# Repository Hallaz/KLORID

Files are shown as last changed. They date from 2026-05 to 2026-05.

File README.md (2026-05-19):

# KLORID

42-key split keyboard, polydactyl layout, sourced untuk komponen yang mudah didapat di **Indonesia** (Tokopedia / Shopee). Derivative dari [Lefuneste83/KLOR](https://github.com/Lefuneste83/KLOR), yang sendirinya fork dari [GEIGEIGEIST/KLOR](https://github.com/GEIGEIGEIST/KLOR).

> **"ID"** suffix = Indonesia variant. Sourcing decisions menghindari long-wait import (Mill-Max, Elite-Pi, etc.), default ke part Tokopedia-sourceable.

## Hardware modifications dari upstream KLOR

### Core PCB modifications (Phase 2)

| # | Modification | Source → Target |
|---|---|---|
| MOD #1 | MCU footprint | Elite-Pi (Pro-Micro form factor) → bare **Waveshare RP2040-Zero** (2.54mm pitch through-hole) |
| MOD #2 | Inter-half connector | TRRS jack MJ-4PP-9 → **USB-C 16-pin midmount** (HRO Type-C-31-M-12) |
| MOD #3 | RGB orientation | south-facing **verified** — fork's existing `SK6812MINI_and_cherry_1` footprint sudah benar (no schematic change needed) |

### Phase 3 PCB layout enhancements

| Phase | Enhancement |
|---|---|
| **3e** | **Dual-purpose SW23 at matrix [3,5]** — single position serves either encoder OR MX switch, builder chooses per side at assembly (mix possible — encoder on one half, switch on other) |
| **3f** | Left thumb cluster **breakaway notch removed** (real-world fragility evidence — fork's intentional snap-off point breaks too easily under normal handling) |
| **3g** | **Haptic feedback re-added as DNP** — Pimoroni Haptic Buzz 5-pin connector (`Conn_01x05`), I2C-shared with OLED (GP2/GP3), trigger on GP14. Optional install at assembly time; PCB ships with footprint+routing ready. |
| **3h** | **Silkscreen branding** — KLORID text + Garuda Pancasila image (Indonesia national emblem) on F.SilkS layer |

### Dropped from upstream (out of scope for V1)

- Audio speaker (PWM buzzer on GP9 — pin now repurposed sebagai matrix col 2)
- Battery + power switch chain (wired-only build)
- Trackball / pointing device module
- `lvc27_onlyInput` buffer (haptic-related, not needed dengan Pimoroni breakout approach)

## Status — Phase 4 ready (Gerber export complete)

PCB design lengkap. All Phase 3 enhancements committed. Gerber files regenerated (ZIP siap upload). Pending: actual JLCPCB order + case fabrication.

**Latest milestones:**
- ✅ Phase 3a-3h PCB layout complete (DRC clean, 0 violations)
- ✅ Schematic + PCB sync (ERC clean, 0 errors)
- ✅ Gerber export untuk all layers (`hardware/PCB/klor1_4/gerbers/gerbers.zip`)
- ✅ Switchplate DXF generated (`working/switchplate_klorid.dxf` — for CO2 laser cut)
- ⏳ JLCPCB order pending
- ⏳ Other case acrylic layers (bottom plate, spacers, top frame) pending generation
- ⏳ Firmware Phase 6 deferred (QMK + Vial dengan Justin Lam RP2040-Zero config)

Detail per-phase progress di [PHASE_LOG.md](PHASE_LOG.md).

## Case strategy (Indonesia-friendly)

PCB modifications drive case requirements (USB-C cutout, encoder/MX position, OLED window). Case approach untuk Indonesia sourcing:

- **PCB fab:** JLCPCB (2-layer FR4 1.6mm, black HASL)
- **Switchplate + acrylic layers:** Local CO2 laser cut shop (DXF generated programmatically from PCB)
- **Case body 3DP:** JLCPCB 3D printing service atau lokal print
- **Hardware:** M2 standoffs + screws from Tokopedia

## Spec & decisions

- [PROJECT_SPEC.md](PROJECT_SPEC.md) — Tier 1 (locked Requirements R1-R10) + Tier 2 (Component Decisions dengan justifikasi)
- [PHASE_LOG.md](PHASE_LOG.md) — Build progress log (append-only, latest at bottom)
- [CONTRIBUTING.md](CONTRIBUTING.md) — Collaboration model + KiCad workflow + hard rules
- [docs/phase-1-recon/](docs/phase-1-recon/) — Phase 1 reconnaissance outputs (5 deliverables)

## Repository structure

```
KLORID/
├── README.md             ← (you are here)
├── LICENSE               ← GPL-3.0 (inherited from upstream)
├── PROJECT_SPEC.md       ← Requirements + component decisions
├── PHASE_LOG.md          ← Build progress
├── CONTRIBUTING.md       ← Collaboration + workflow rules
├── docs/
│   └── phase-1-recon/    ← Phase 1 deliverables
└── hardware/             ← KiCad PCB + schematic + firmware + case
    ├── PCB/klor1_4/      ← Active design (KiCad 10)
    ├── FIRMWARE/         ← QMK + Vial firmware
    ├── case/             ← 3DP STL + acrylic DXF
    └── docs/             ← Fork's original hardware docs
```

Excluded (local-only, not in repo): `references/` (upstream snapshots untuk development context), `working/` (derived gerbers/firmware build artifacts), `.claude/` (harness state).

## License

**GPL-3.0** — same as upstream KLOR. Derivative works WAJIB tetap GPL-3.0. See [LICENSE](LICENSE).

## Attribution

Credit chain:
- **GEIGEIGEIST/KLOR** — original KLOR design
- **Lefuneste83/KLOR** — fork dengan klor1_4 (Rev 1.4) PCB
- **Hallaz/KLORID** — Indonesia-sourceable variant (this repo)

Built with Claude Code as collaborator. AI-assisted PCB modification per [CONTRIBUTING.md](CONTRIBUTING.md) collaboration model.

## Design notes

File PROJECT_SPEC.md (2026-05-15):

# KLOR Custom Build — Project Spec

> **Last updated 2026-05-14** (Phase 2 in-progress — schematic MOD #1 + MOD #2 done, ERC clean). Spec dibagi 2 tier: REQUIREMENTS (locked, user-owned) + COMPONENT DECISIONS (Claude-decided, justified). Tier 1 berubah hanya dengan explicit user discussion. Tier 2 bisa berubah dengan justifikasi teknis/sourcing.

---

## TIER 1: REQUIREMENTS (locked)

User's functional spec — apa keyboard ini harus DO.

| # | Requirement | Notes |
|---|---|---|
| R1 | 42-key split keyboard, polydactyl layout | **21 keys per side + 1 encoder/knob position per side** (total 42 keys + 2 encoders); 19.05 × 19.05 mm key spacing |
| R2 | MX switch ecosystem | Universal MX hotswap socket; switch + keycap MX-compatible |
| R3 | USB-C native MCU primary | No Pro-Micro daughterboard awkward USB |
| R4 | USB-C inter-half connector | Replace TRRS jack |
| R5 | Per-key RGB matrix | 42 LED total (21/side × 2), south-facing orientation |
| R6 | OLED display | Status / mode / animation rendering |
| R7 | Rotary encoder optional via jumper | EC11-style with push button (1 per side default) |
| R8 | JLCPCB-manufacturable | 2-layer FR4 1.6mm, standard DRC compliant |
| R9 | Vial-QMK firmware | Real-time keymap edit without re-flash |
| R10 | Socketable MCU | Untuk prototyping iteration |

---

## TIER 2: COMPONENT DECISIONS

### MCU

| | Decision | Rationale |
|---|---|---|
| **Part** | Original Waveshare RP2040-Zero (not clones) | 20 GPIO sufficient (17 used + 3 headroom), USB-C native, compact, $3-5/unit |
| **Sourcing** | Tokopedia / Shopee (verified seller) | Indonesia sourcing-locked: Elite-Pi unavailable |
| **Mounting** | 1.27mm pitch female pin header (2×12-pin per side) di PCB + 1.27mm male pin header solder ke castellated edge RP2040-Zero | Mill-Max preferred low profile tapi Aliexpress 3-4wk wait. 1.27mm header Tokopedia ~10rb/pasang. Stack ~6mm. |

### Inter-half connector

| | Decision | Rationale |
|---|---|---|
| **Part** | USB-C 16-pin midmount SMD (GCT USB4085 or HRO TYPE-C-31-M-12, final TBD Phase 2) | 16-pin = right pin count; midmount = cleaner PCB profile |
| **Wire allocation (firmware initial)** | **Half-duplex single-wire serial on GP1** (3 wires: VBUS + GND + GP1) | Per fork [config.h:49](hardware/FIRMWARE/qmk_rp2040/electronlab/klor/config.h) currently active |
| **Wire allocation (PCB routing)** | **Route both GP1 + GP4 to USB-C pads** (4 traces) | Future-proof full-duplex upgrade path per fork [CHANGELOG.md:69-73](hardware/CHANGELOG.md). Firmware switch later, no PCB re-spin needed. |
| **CC1, CC2** | Tied to 5.1kΩ pulldown to GND each | Dumb-sink USB-C; implemented in MOD #2 schematic |
| **VBUS / 5V net** | USB-C VBUS pin joined to global `+5V` net (shared with MCU 5V pad + LED VCC). `PWR_FLAG` marker placed on `+5V` net (MCU-side, `#FLG02`) to satisfy ERC | USB-C VBUS pin = passive type — ERC needs PWR_FLAG declared somewhere on net. PWR_FLAG is net-level marker; one instance covers entire `+5V` net regardless of placement. No PCB/physical effect. |
| **Cable** | USB-C to USB-C, ~30cm | Tokopedia sourceable; not part of PCB BOM |

### RGB LED

| | Decision | Rationale |
|---|---|---|
| **Part** | SK6812MINI-E (6028 size), south-facing reverse-mount | Better current + uniformity vs WS2812 3535. Fork klor1_4 sudah south-facing per [README:37](hardware/README.md) |
| **Count** | 42 (21 per side × 2) | Per R5 |
| **Footprint variant** | `SK6812MINI_and_cherry_1` (already di klor1_4 KLOR.pretty) — dual-layer pad placement + Edge.Cuts cutout zone | **No new footprint needed** ([FOOTPRINT_INVENTORY C.3](docs/phase-1-recon/FOOTPRINT_INVENTORY.md)) |
| **Assembly** | Hand-solder reverse-mount dengan hot air / reflow plate | User confirmed SMD capability |

### OLED

| | Decision | Rationale |
|---|---|---|
| **Part** | SSD1306 **0.96" 128×64** I²C 4-pin | **Revised from 128×32** — fork rendering code, animation library (`klorimation.h`), logo bitmap semua tuned untuk 128×64. Switching = significant firmware rewrite untuk zero benefit |
| **Footprint** | `SSD1306_128x64OLED` (existing klor1_4 KLOR.pretty) | Outline ~27×27mm = 0.96" form factor. Pin pitch 2.54mm universal |
| **Sourcing** | Tokopedia / Aliexpress (~25-35rb/unit) | Abundant |

### Encoder

| | Decision | Rationale |
|---|---|---|
| **Part** | EC11 vertical mount with push switch | Standard, fork sudah implementasi, sourceable Tokopedia |
| **Config** | Optional via jumper bridge | Fork's design preserved |
| **Encoder push position di matrix** | L35 [3,5] (left), R30 [7,5] (right) — encoder push-button shares matrix position untuk keycode assignment via Vial | Per fork `keyboard.json` LAYOUT_polydactyl |

### Switch socket & matrix

| | Decision | Rationale |
|---|---|---|
| **Hotswap** | Kailh MX hotswap PG1511 | Fork sudah pakai. Universal MX. Tokopedia |
| **Diode** | 1N4148W SOD-123 SMD | Fork's `Diode_SOD123` footprint dual-side reversible |
| **Direction** | COL2ROW | Per fork `keyboard.json:17` |
| **Matrix size** | 8 rows × 6 cols logical (4 rows × 6 cols per half) | Fork-preserved |

### Matrix pin allocation (RP2040-Zero) — REMAPPED

```json
// keyboard.json matrix_pins (Phase 6 firmware update):
"cols": ["GP27", "GP26", "GP9", "GP10", "GP11", "GP12"],
"rows": ["GP5", "GP6", "GP7", "GP8"]
```

| Logical pin | Pin (was, elite_pi) | Pin (new, RP2040-Zero) | Reason |
|---|---|---|---|
| col 0 | GP27 | GP27 | Keep — RP2040-Zero ADC pad |
| col 1 | GP26 | GP26 | Keep — RP2040-Zero ADC pad |
| col 2 | GP22 | **GP9** | Remap — GP22 not exposed on RP2040-Zero edge; ascending order chosen untuk natural label sequence |
| col 3 | GP20 | **GP10** | Remap |
| col 4 | GP23 | **GP11** | Remap |
| col 5 | GP21 | **GP12** | Remap |
| row 0-3 | GP5-GP8 | GP5-GP8 | Keep — exposed on RP2040-Zero edge |

**Additional GPIO assignments** (RP2040-Zero, 20 GPIO total):

| Function | Pin | Notes |
|---|---|---|
| RESET button | **GP15** | Soft reset via firmware (Vial reset keycode). Hardware reset to bootloader requires fine-wire jumper ke RP2040-Zero RUN test pad — defer ke Phase 5 assembly kalau dibutuhkan untuk "Windows startup recovery" use case |
| Spares | GP13, GP14 | 2 free GPIO untuk future expansion (e.g., second encoder, status LED, additional I²C device) |

Full GPIO allocation: [docs/phase-1-recon/PIN_MAPPING_PROPOSAL.md](docs/phase-1-recon/PIN_MAPPING_PROPOSAL.md).

### Base PCB variant

| | Decision | Rationale |
|---|---|---|
| **Variant** | Fork's `PCB/klor1_4/` (Rev 1.4) | Latest with committed files. Rev 1.5 announced but PCB files absent. LP_KS33 = irrelevant (low-profile beta) |

### Case

| | Decision | Rationale |
|---|---|---|
| **Files** | Fork's `case/3DP/polydactyl/regular/*.stl` + `case/3DP/polydactyl/switchplate/*.stl` | Drop-in from fork; no modification needed |
| **Material** | 3D printed (PETG / PLA / ASA — user choice) | Standard FFF print |

### Manufacturing & assembly model

| | Decision | Rationale |
|---|---|---|
| **PCB fab** | JLCPCB, 2-layer FR4 1.6mm, HASL/LeadFree HASL, black, "Remove Order Number: Yes" | Per fork [PCB/README.md:14](hardware/PCB/README.md) |
| **PCBA service** | ❌ NOT used | User has SMD soldering capability — hand-solder all parts |
| **BOM sourcing** | Mix Tokopedia + Aliexpress + LCSC | Indonesia sourcing-flexible |

### Firmware configuration (Phase 6 spec)

Per [Justin Lam handwired Skeletyl blog](https://www.justinmklam.com/posts/2025/08/handwired-skeletyl/) — bare RP2040-Zero requires these specific settings (NOT same as fork's `elite_pi` config):

**`keyboard.json` changes:**
```diff
- "development_board": "elite_pi"
+ "processor": "RP2040",
+ "bootloader": "rp2040"
```
Reason: Bare RP2040-Zero needs explicit processor + bootloader macros, bukan dev_board alias. Otherwise flashing may fail.

**`config.h` additions:**
```c
#define RP2040_BOOTLOADER_DOUBLE_TAP_RESET           // double-tap reset → bootloader entry
#define RP2040_BOOTLOADER_DOUBLE_TAP_RESET_TIMEOUT 500U
#define PICO_XOSC_STARTUP_DELAY_MULTIPLIER 64        // crystal startup delay = reliable boot
#define SERIAL_PIO_USE_PIO1                          // 🔑 PIO1 untuk serial; prevents conflict dengan WS2812 (PIO0)
```

**`rules.mk` addition:**
```make
SERIAL_DRIVER = vendor
```
`vendor` = QMK's RP2040-specific PIO-based serial driver.

---

## DROPPED (out of scope; do not re-add tanpa discussion)

- Haptic feedback (DRV2605L driver + ERM/LRA motor + Pimoroni footprint) — ✅ dropped from schematic commit `17c1fb3`
- Audio (PWM speaker on GP9 + `lib/klounds.h` sound clips) — ✅ Mallory Buzzer BZ1 dropped commit `17c1fb3`
- **Trackball module** (mouse/pointing device section in original fork schematic) — ✅ dropped commit `17c1fb3`. Discovered during Phase 2 housekeeping; was NOT in initial DROPPED list. User explicitly decided to skip pointing-device feature scope.
- ZMK firmware variant (QMK only)
- Bluetooth / Nice Nano support (wired RP2040-Zero only)
- Battery & power switch chain (wired-only build): drop MSK12C02 slide switch + JST-PH + `custombatteryconnector_small` placements — ✅ dropped commit `ee98b40` (MOD #1)
- `lvc27_onlyInput` 74LVC2G17 buffer — ✅ dropped commit `17c1fb3` (confirmed haptic-support related)

---

## PCB Modification Scope (revised after Phase 1)

1. **MOD #1 — MCU footprint:** Elite-Pi (RP2040 Pro-Micro form-factor) → custom Waveshare RP2040-Zero footprint with 1.27mm pitch socket pads. **Plus** re-route 4 matrix col pins per remap (GP22/20/23/21 → GP9/10/11/12, ascending order). RESET button connected ke GP15 (soft reset).

2. **MOD #2 — Inter-half connector:** TRRS jack (MJ-4PP-9) → USB-C 16-pin midmount SMD. Route both GP1 + GP4 to USB-C pins (future-proof).

3. **MOD #3 — RGB orientation (VERIFY ONLY):** Confirm klor1_4 schematic instantiate `SK6812MINI_and_cherry_1` variant (south-facing already) bukan older `SK6812MINI_and_cherry`. If yes, no PCB modification for RGB. Verify at Phase 2 schematic open.

**Plus housekeeping (Phase 2 schematic):**
- Remove placements: Pimoroni Haptic, Mallory buzzer, MSK12C02 slide switch, JST-PH battery, custombatteryconnector, lvc27_onlyInput (if haptic-related)
- Phase 6: update `keyboard.json` per pin remap + firmware config

### KEEP unchanged

- Switch footprint area (MX hotswap PG1511)
- Key spacing (19.05 mm × 19.05 mm)
- Encoder placement (optional via jumper, matrix [3,5]/[7,5] coords for push-button)
- OLED area (same physical slot for 128×64)
- Diode positions
- Matrix routing logic (8 rows × 6 cols, COL2ROW)
- Reset switch placement
- LED chain order (entry at GP0 → LED 00 → daisy-chain to LED 20)

---

## Phase 1 Recon outputs (reference)

All deliverables di `docs/phase-1-recon/`:
- [INVENTORY.md](docs/phase-1-recon/INVENTORY.md) — File census + LICENSE (GPL-3.0) + fork status (stale ~20 bulan)
- [MATRIX_VALIDATION.md](docs/phase-1-recon/MATRIX_VALIDATION.md) — Matrix dimensions, pin audit, GPIO budget
- [FOOTPRINT_INVENTORY.md](docs/phase-1-recon/FOOTPRINT_INVENTORY.md) — Library audit + mod-critical footprints
- [PIN_MAPPING_PROPOSAL.md](docs/phase-1-recon/PIN_MAPPING_PROPOSAL.md) — Final 17/20 GPIO allocation
- [REFERENCE_ANALYSIS.md](docs/phase-1-recon/REFERENCE_ANALYSIS.md) — zerosprey42 + Justin Lam + fork delta + Phase 2 risk register (15 items)

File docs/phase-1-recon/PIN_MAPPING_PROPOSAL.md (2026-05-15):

# Phase 1 / Deliverable #4 — PIN_MAPPING_PROPOSAL

> Lock specific pin assignments untuk Waveshare RP2040-Zero target. Cross-validated dari `keyboard.json`, `config.h`, [KLORpinout.png](../../references/KLOR-upstream/docs/images/KLORpinout.png) visual reference, dan zerosprey42 (42-key RP2040-Zero) sebagai exemplar.

---

## A. Reference baseline — fork's pin mapping (Pro Micro physical layout)

[KLORpinout.png](../../references/KLOR-upstream/docs/images/KLORpinout.png) menunjukkan **fork PCB uses Pro Micro physical pinout** (24-pin dual-row format). Pin label di PNG = AVR convention (D0-D7, B1-B7, C6, E6, F4-F7). Fork's elite_pi config (`development_board: "elite_pi"`) maps these physical positions ke **RP2040 GPxx labels** via standard elite_pi-to-Pro-Micro pin mapping.

Cross-reference table (Pro Micro pin → AVR label → RP2040 GPxx → function):

| PM pin # | Side | AVR label | RP2040 GPxx | Fork function | Source |
|---|---|---|---|---|---|
| 1 | TL | TX0/D3 | **GP0** | WS2812 RGB DI | KLORpinout, keyboard.json `ws2812.pin` |
| 2 | TL | RX1/D2 | **GP1** | Serial TX (half-duplex) | KLORpinout, [config.h:49](../../hardware/FIRMWARE/qmk_rp2040/electronlab/klor/config.h) |
| 3 | TL | GND | GND | Ground | — |
| 4 | TL | GND | GND | Ground | — |
| 5 | TL | 2/D1/SDA | **GP2** | I²C1 SDA (OLED) | KLORpinout, [config.h:26](../../hardware/FIRMWARE/qmk_rp2040/electronlab/klor/config.h) |
| 6 | TL | 3/D0/SCL | **GP3** | I²C1 SCL (OLED) | KLORpinout, config.h:25 |
| 7 | TL | 4/D4 | **GP4** | (Reserved: serial RX full-duplex) | config.h:52 commented |
| 8 | TL | 5/C6 | **GP5** | Matrix row 0 | KLORpinout, keyboard.json rows[0] |
| 9 | TL | 6/D7 | **GP6** | Matrix row 1 | keyboard.json rows[1] |
| 10 | TL | 7/E6 | **GP7** | Matrix row 2 | keyboard.json rows[2] |
| 11 | TL | 8/B4 | **GP8** | Matrix row 3 | keyboard.json rows[3] |
| 12 | TL | 9/B5 | **GP9** | Audio PWM (DROPPED) | KLORpinout, config.h:115 |
| 13 | TR | B6/10 | **GP21** | Matrix col 5 | keyboard.json cols[5] |
| 14 | TR | B2/16 | **GP23** | Matrix col 4 | keyboard.json cols[4] |
| 15 | TR | B3/14 | **GP20** | Matrix col 3 | keyboard.json cols[3] |
| 16 | TR | B1/15 | **GP22** | Matrix col 2 | keyboard.json cols[2] |
| 17 | TR | F7/A0 | **GP26** | Matrix col 1 | keyboard.json cols[1] |
| 18 | TR | F6/A1 | **GP27** | Matrix col 0 | keyboard.json cols[0] |
| 19 | TR | F5/A2 | **GP28** | Encoder A (left), Encoder B (right per split.encoder) | keyboard.json encoder |
| 20 | TR | F4/A3 | **GP29** | Encoder B (left), Encoder A (right) | keyboard.json encoder |
| 21 | TR | VCC | 3.3V | Logic power | — |
| 22 | TR | RST | RST | Reset (to button) | — |
| 23 | TR | GND | GND | Ground | — |
| 24 | TR | RAW | VBUS | 5V from USB | — |

✅ **Verified cross-consistency:** KLORpinout PNG, `keyboard.json`, `config.h` semua agree — pin assignment fork tersinkron.

---

## B. RP2040-Zero pin availability audit

Waveshare RP2040-Zero exposes **20 GPIO** (per [Waveshare wiki](https://www.waveshare.com/wiki/RP2040-Zero)):

| GPxx | Edge pad? | Notes |
|---|---|---|
| GP0–GP15 | ✅ Castellated edge | 16 pins, 1.27mm pitch |
| GP16 | ❌ Internal | Onboard WS2812 status LED (Waveshare boot indicator) |
| GP17–GP19 | ❌ NOT accessible | Not broken out |
| GP20–GP25 | ❌ NOT accessible | Not broken out (USB pins GP24/25) |
| GP26–GP29 | ✅ Bottom ADC pads | 4 pins (separate from castellated edge) |

🚨 **Critical mismatch identified:** Fork's cols GP20, GP21, GP22, GP23 are **NOT exposed** di RP2040-Zero. Need remap.

---

## C. Final pin allocation untuk Waveshare RP2040-Zero

| GPxx | Function | Type | Rationale | Status |
|---|---|---|---|---|
| **GP0** | WS2812 RGB DI | PIO | Native RGB data pin, PIO-driven (any GPIO works, GP0 is convention) | ✅ Keep from fork |
| **GP1** | Serial TX (half-duplex) | UART/PIO | Per fork config.h:49 active config | ✅ Keep from fork |
| **GP2** | I²C1 SDA | I²C alt-func | I²C1 hardware peripheral pair (GP2/GP3 native) | ✅ Keep from fork |
| **GP3** | I²C1 SCL | I²C alt-func | Pair with GP2 | ✅ Keep from fork |
| **GP4** | Serial RX (full-duplex upgrade path) | UART/PIO | Per fork CHANGELOG.md:69-73 documented spec | ⚠️ Route PCB pad even if firmware tidak enable initially |
| **GP5** | Matrix row 0 | GPIO | Keep from fork | ✅ |
| **GP6** | Matrix row 1 | GPIO | Keep from fork | ✅ |
| **GP7** | Matrix row 2 | GPIO | Keep from fork | ✅ |
| **GP8** | Matrix row 3 | GPIO | Keep from fork | ✅ |
| **GP9** | **Matrix col 2** | GPIO | **REMAP** dari GP22 (freed from audio drop). Ascending order chosen untuk natural label sequence | 🆕 New |
| **GP10** | **Matrix col 3** | GPIO | **REMAP** dari GP20 | 🆕 New |
| **GP11** | **Matrix col 4** | GPIO | **REMAP** dari GP23 | 🆕 New |
| **GP12** | **Matrix col 5** | GPIO | **REMAP** dari GP21 | 🆕 New |
| **GP13** | (Headroom / spare 1) | GPIO | Available for future feature | ⚪ Free |
| **GP14** | (Headroom / spare 2) | GPIO | Available for future feature | ⚪ Free |
| **GP15** | **RESET button** | GPIO | Soft reset via firmware (Vial reset keycode). User-accessible reset button on PCB | 🆕 New |
| GP16-GP25 | (Not accessible on RP2040-Zero) | — | Not broken out (board design limit) | ❌ N/A |
| **GP26** | Matrix col 1 | GPIO | Keep from fork (ADC-capable, but used as GPIO here) | ✅ |
| **GP27** | Matrix col 0 | GPIO | Keep from fork | ✅ |
| **GP28** | Encoder A (left) / B (right) | GPIO | Keep from fork. ADC-capable but used as GPIO here. | ✅ |
| **GP29** | Encoder B (left) / A (right) | GPIO | Keep from fork | ✅ |

**Total used: 18 GPIO of 20 available. Headroom: 2 GPIO** (GP13, GP14).

Used breakdown: GP0 (RGB DI) + GP1 (serial TX) + GP2-3 (I²C OLED) + GP4 (serial RX reserve, PCB-routed) + GP5-8 (rows) + GP9-12 (cols 2-5) + GP15 (RESET) + GP26-27 (cols 0-1) + GP28-29 (encoder).

---

## D. Updated `keyboard.json` matrix_pins (Phase 6 firmware update preview)

**Current** (fork's klor1_4):
```json
"matrix_pins": {
    "cols": ["GP27", "GP26", "GP22", "GP20", "GP23", "GP21"],
    "rows": ["GP5", "GP6", "GP7", "GP8"]
}
```

**Proposed** (post-remap untuk RP2040-Zero, **LOCKED** per schematic MOD #1 commit `ee98b40`):
```json
"matrix_pins": {
    "cols": ["GP27", "GP26", "GP9", "GP10", "GP11", "GP12"],
    "rows": ["GP5", "GP6", "GP7", "GP8"]
}
```

**Mapping logic untuk new col pins (ascending):**
- Maintain GP27/GP26 di cols 0-1 (fork-preserved, ADC pad)
- Cols 2-5 remap ascending to GP9, GP10, GP11, GP12 — user-accepted untuk natural label sequence (`col 2 < col 3 < col 4 < col 5` matches `GP9 < GP10 < GP11 < GP12`)
- GP9 freed by audio feature drop (was PWM speaker); now repurposed sebagai col 2

**Status:** locked in schematic. Update `keyboard.json` at Phase 6 firmware step (along with `processor`/`bootloader` macros + Justin Lam config — see PROJECT_SPEC.md firmware section).

---

## E. Pin function compatibility check (RP2040 alt-function table)

Verify none of our assignments conflict dengan RP2040's hardware peripheral routing:

| GPxx | Our use | RP2040 alt-functions yang relevant | Conflict? |
|---|---|---|---|
| GP0 | PIO (WS2812) | UART0 TX, I²C0 SDA, SPI0 RX, PIO | None — PIO is software-defined, no conflict dengan unused alts |
| GP1 | Serial (PIO or UART0 RX) | UART0 RX, I²C0 SCL, SPI0 CS, PIO | None |
| GP2 | I²C1 SDA | I²C1 SDA (native), SPI0 SCK, UART0 CTS | ✅ Using native peripheral |
| GP3 | I²C1 SCL | I²C1 SCL (native), SPI0 TX, UART0 RTS | ✅ Native |
| GP4 | Serial (PIO or UART1 TX) | UART1 TX, I²C0 SDA, SPI0 RX, PIO | None — flexible |
| GP5-GP8 | GPIO (matrix rows) | Various; not used | None |
| GP9-12 | GPIO (matrix cols 2-5) | Various; not used | None |
| GP15 | GPIO (RESET button) | Various; not used | None — used as standard digital input |
| GP26-29 | GPIO (cols + encoder) | ADC inputs; not used as ADC | None (configured as digital GPIO via QMK) |

✅ **No conflicts.** All special peripherals (I²C1, PIO untuk RGB, UART untuk serial) sudah pakai native pins atau PIO-flexible.

---

## F. Cross-validation dengan zerosprey42 (42-key RP2040-Zero exemplar)

[zerosprey42 README](../../references/zerosprey42/README.md) confirms:
- Same MCU: WaveShare RP2040-Zero
- Same firmware: QMK + Vial
- Same key count target: 42 keys
- **Different topology:** monoblock unibody (single PCB, single MCU) — bukan split

Zerosprey42 firmware ada di repo terpisah ([vial-qmk-zerosprey42](https://github.com/beekeeb/vial-qmk-zerosprey42)) — tidak cloned dalam workspace kita. Untuk pin assignment cross-check, akan butuh either:
- Clone vial-qmk-zerosprey42 (defer kalau tidak critical)
- Read zerosprey42's `pcb/zerosprey42.kicad_sch` schematic (sudah ada lokal, Phase 2 task)

**Penting:** zerosprey42 uses **42 individual switches direct-connected** (no matrix multiplexing? unlikely — likely uses matrix tapi RP2040 has plenty GPIO). Atau matrix dengan smaller dimensions (e.g., 6×7 or similar). PCB-back image menunjukkan diode per switch → matrix-scanned.

PCB-back visual menunjukkan **RP2040-Zero footprint di top center** dengan dual-row castellated edge pads — pattern reference untuk our PCB footprint design Phase 3.

> **Action item Phase 2:** Open zerosprey42 schematic untuk extract its exact pin allocation. Cross-validate vs proposal kita untuk catch any RP2040-Zero-specific gotcha (e.g., pins yang ternyata problematic di production).

---

## G. RGB LED data chain reference

[KLOR_LEDorder.png](../../references/KLOR-upstream/docs/images/KLOR_LEDorder.png) menunjukkan **WS2812/SK6812 daisy-chain order** per side:

- **Chain entry:** MCU GP0 → LED index 00 (bottom-right thumb area)
- **Chain progresses:** thumb cluster → bottom alpha row → home row → top alpha row
- **Chain exit:** LED index 20 (top-left)
- Per side: 21 LEDs total (matches `RGBLED_SPLIT { 21, 21 }` di config.h:86)

For RP2040-Zero target:
- GP0 still drives LED chain entry (no change)
- Chain order **preserved as-is** (no key layout changes per mod scope)
- `rgb_matrix.layout` di keyboard.json **unchanged** (matrix coordinates dan visual positions tetap)

> **Implication for Phase 3 PCB:** When relocating MCU footprint to RP2040-Zero physical position, ensure GP0 trace can reach the LED chain entry point on PCB tanpa awkward routing. Current fork uses ProMicro pin 1 (top-left of MCU) untuk GP0. RP2040-Zero edge GP0 pad will be at different physical position — Phase 3 plan trace accordingly.

---

## H. Untouched fork conventions (no change)

| Aspect | Fork value | Our value | Reason |
|---|---|---|---|
| MATRIX_ROWS | 8 (logical, split-aware) | 8 | Unchanged |
| MATRIX_COLS | 6 | 6 | Unchanged |
| DIODE_DIRECTION | COL2ROW | COL2ROW | Unchanged |
| DEBOUNCE | 5 ms | 5 ms | Unchanged |
| SPLIT_USB_DETECT | Enabled | Enabled | Unchanged |
| RGBLED_SPLIT | { 21, 21 } | { 21, 21 } | Unchanged (per side count) |
| OLED I²C address | Default 0x3C | 0x3C | Unchanged (SSD1306 standard) |

---

## I. Open items (Phase 2+)

1. ~~**Final col-pin order locked di Phase 3** based on PCB routing optimization.~~ ✅ **RESOLVED 2026-05-14** — Locked di schematic MOD #1 (commit `ee98b40`): ascending order `[GP27, GP26, GP9, GP10, GP11, GP12]`. User-accepted untuk natural label sequence.
2. ~~**GP4 routing decision Phase 2:** route to USB-C connector unconditionally?~~ ✅ **RESOLVED 2026-05-14** — Routed in schematic MOD #2 (commit `fa041cc`). GP1 + GP4 both connect ke USB-C inter-half data pins. Firmware enables half-duplex GP1 initially; GP4 reserve untuk future full-duplex upgrade.
3. ~~**CC1/CC2 USB-C handling Phase 2:** tie to 5.1kΩ pulldown?~~ ✅ **RESOLVED 2026-05-14** — Implemented in MOD #2 (commit `fa041cc`). 5.1kΩ pulldown ke GND each. PWR_FLAG on `+5V` net to satisfy ERC for passive VBUS pin.
4. **Encoder push-button matrix scanning:** keyboard.json LAYOUT_polydactyl has L35/R30 di matrix [3,5]/[7,5] sebagai encoder push position. Verify physical PCB encoder footprint connects switch terminals correctly — per new col mapping: row 3 (GP8) + col 5 (**GP12**, was GP10) for left, row 7 (GP8) + col 5 (**GP12**) for right. **Phase 3 PCB layout task.**
5. **zerosprey42 schematic pin extraction** — deferred non-critical. Our pin allocation already cross-validated via Justin Lam's blog + Waveshare wiki.
6. ~~**PROJECT_SPEC.md updates batch**~~ ✅ **RESOLVED 2026-05-13/14** — Phase 1 batch applied (OLED, serial, R1, col pins). Phase 2 follow-up applied 2026-05-14 (ascending col order, RESET GP15, PWR_FLAG note).
7. **NEW — RESET button hardware fallback:** GP15 soft-reset works via Vial keycode dari host PC. Untuk "Windows startup recovery" scenario (PC won't boot, can't send keycode), user needs hardware bootloader entry → fine-wire jumper between RP2040-Zero **RUN** test pad + GND. **Defer ke Phase 5 assembly:** decide whether to add jumper trace di PCB atau leave as soldering exercise during build.

---

## J. Summary table — bottom line untuk Phase 2 schematic

**RP2040-Zero pin allocation untuk PCB schematic Phase 2:**

```
GP0  → WS2812 RGB DI               (PIO-driven, route to LED chain entry)
GP1  → Serial TX (half-duplex)     (route to USB-C inter-half data pin)
GP2  → I²C1 SDA (OLED)             (route to OLED pad 4 SDA)
GP3  → I²C1 SCL (OLED)             (route to OLED pad 3 SCL)
GP4  → Serial RX reserve           (route to USB-C inter-half pin, NC initially di firmware)
GP5  → Matrix row 0
GP6  → Matrix row 1
GP7  → Matrix row 2
GP8  → Matrix row 3
GP9  → Matrix col 2
GP10 → Matrix col 3
GP11 → Matrix col 4
GP12 → Matrix col 5
GP13 → (free, spare)
GP14 → (free, spare)
GP15 → RESET button (soft reset, user-accessible)
GP26 → Matrix col 1
GP27 → Matrix col 0
GP28 → Encoder A (left half) / B (right half)
GP29 → Encoder B (left half) / A (right half)
VBUS → 5V from USB-C (USB1 primary + USB-C inter-half VBUS sharing)
3V3  → Logic level (RP2040-Zero internal LDO output, available on castellated)
GND  → ground reference
```

---

## K. Cross-references

- [INVENTORY.md](INVENTORY.md) — Phase 1 #1 file census
- [MATRIX_VALIDATION.md](MATRIX_VALIDATION.md) — Matrix dimensions + initial pin findings
- [FOOTPRINT_INVENTORY.md](FOOTPRINT_INVENTORY.md) — Library audit
- [KLORpinout.png](../../references/KLOR-upstream/docs/images/KLORpinout.png) — Fork pinout visual
- [KLOR_LEDorder.png](../../references/KLOR-upstream/docs/images/KLOR_LEDorder.png) — RGB chain order
- [zerosprey42 README](../../references/zerosprey42/README.md) — RP2040-Zero exemplar
- [Waveshare RP2040-Zero wiki](https://www.waveshare.com/wiki/RP2040-Zero) — GPIO availability spec
- [keyboard.json](../../hardware/FIRMWARE/qmk_rp2040/electronlab/klor/keyboard.json) — Pin source of truth (fork current)
- [config.h](../../hardware/FIRMWARE/qmk_rp2040/electronlab/klor/config.h) — Firmware config (fork current)

---

## L. Next deliverable

**Phase 1 deliverable #5: `REFERENCE_ANALYSIS.md`**

Scope:
- Compare zerosprey42 pin mapping (extract dari schematic file) vs proposal kita — catch any RP2040-Zero pin gotchas
- Lessons dari Justin Lam handwired Skeletyl blog (PIO serial, double-tap bootloader reset)
- Lefuneste83 fork analysis — what diverged dari upstream GEIGEIGEIST, why
- Compatibility check: KiCad 10 vs fork's KiCad 6/7/8 format (migration risks)
- Risk register untuk Phase 2 (things to watch saat schematic mod)

Estimated output: ~200 baris di `docs/phase-1-recon/REFERENCE_ANALYSIS.md`.

Confirm "go", atau ada catatan untuk PIN_MAPPING_PROPOSAL.md dulu?

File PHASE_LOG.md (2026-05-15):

# Phase Log

Append-only chronological log of decisions, milestones, blockers. Latest entries at bottom.

---

## Phase 0 — Project Setup · 2026-05-13 (morning)

**Done:**
- Cloned 4 repos: KLOR (Lefuneste83), KLOR-upstream (GEIGEIGEIST), zerosprey42 (beekeeb), Skeletyl (Bastardkb)
- Workspace reorganized: `hardware/`, `references/{KLOR-upstream, zerosprey42, Skeletyl}/`
- Scaffolded `docs/phase-1-recon/`, `working/{gerbers, bom, firmware, screenshots}/`
- Captured initial spec → [PROJECT_SPEC.md](PROJECT_SPEC.md) (refactored Phase 0.5)
- Captured project overview → [README.md](README.md)
- Captured Claude guidance → [CONTRIBUTING.md](CONTRIBUTING.md)

**Decisions confirmed:**
- Haptic + audio features → DROPPED
- MCU framing: Elite-Pi (RP2040 Pro-Micro form-factor) → Waveshare RP2040-Zero
- KiCad files edited in-place

**Environment:**
- Windows 11 (build 26200); KiCad 10.0.2; Git
- QMK CLI deferred Phase 6

---

## Phase 0.5 — Collaboration framework + spec refactor · 2026-05-13 (afternoon)

**Trigger:** User clarified — electronics + PCB-design background but NOT keyboard DIY expert.

**Framework changes:**
- [PROJECT_SPEC.md](PROJECT_SPEC.md) refactored: 2 tiers (REQUIREMENTS locked + COMPONENT DECISIONS Claude-decided)
- [CONTRIBUTING.md](CONTRIBUTING.md) updated collaboration model + Indonesia sourcing context

**Sourcing-driven decisions:**
- RP2040-Zero LOCKED (Elite-Pi unavailable Indonesia)
- 1.27mm female pin header (vs Mill-Max — Aliexpress wait avoided)
- User confirmed SMD capability → JLCPCB bare PCB only, no PCBA

**Initial Tier 2 component decisions** (all revisable per Phase 1 findings).

---

## Phase 1 — Recon · COMPLETED 2026-05-13

All 5 deliverables in `docs/phase-1-recon/`:

| # | Deliverable | Status | Key output |
|---|---|---|---|
| 1 | [INVENTORY.md](docs/phase-1-recon/INVENTORY.md) | ✅ | File census + **LICENSE = GPL-3.0** (not CC-BY-NC-SA) + fork stale ~20 bulan |
| 2 | [MATRIX_VALIDATION.md](docs/phase-1-recon/MATRIX_VALIDATION.md) | ✅ | 8×6 matrix; **GP20-23 not exposed on RP2040-Zero** (4 col pins must remap); OLED is 128×64 (fork) not 128×32 |
| 3 | [FOOTPRINT_INVENTORY.md](docs/phase-1-recon/FOOTPRINT_INVENTORY.md) | ✅ | KLOR.pretty 17 footprints custom (no marbastlib ref); `SK6812MINI_and_cherry_1` = south-facing ready (mod #3 = verify only) |
| 4 | [PIN_MAPPING_PROPOSAL.md](docs/phase-1-recon/PIN_MAPPING_PROPOSAL.md) | ✅ | Final 17/20 GPIO allocation; col remap GP22/20/23/21 → GP13/12/11/10 |
| 5 | [REFERENCE_ANALYSIS.md](docs/phase-1-recon/REFERENCE_ANALYSIS.md) | ✅ | Justin Lam firmware critical config; 15-item Phase 2 risk register |

### Major findings affecting PROJECT_SPEC.md (corrections applied this date)

1. **R1 clarification:** 42-key polydactyl = 21 keys + 1 knob per side (encoder/knob occupies matrix [3,5]/[7,5] in `LAYOUT_polydactyl`). User confirmed via "21 keys per side tidak termasuk knob"
2. **OLED:** firmware uses **128×64** (not 128×32) — `config.h:74` defines `OLED_DISPLAY_128X64` + footprint outline ~27×27mm. Accept fork's 128×64; revised spec.
3. **Inter-half serial:** **half-duplex GP1 active** (not full-duplex as initial assumption from CHANGELOG documentation). Route both GP1+GP4 pada PCB future-proof.
4. **GP20-23 NOT exposed on RP2040-Zero** → 4 col pins remap to GP10-13.
5. **MOD #3 reduces to "verify only"** — fork's `SK6812MINI_and_cherry_1` footprint already south-facing (dual-layer pad + Edge.Cuts cutout).
6. **Bare RP2040-Zero firmware config gotchas** (Justin Lam blog):
   - `keyboard.json`: `processor: RP2040, bootloader: rp2040` instead of `development_board: elite_pi`
   - `config.h`: add `SERIAL_PIO_USE_PIO1` (prevents PIO conflict with WS2812), `RP2040_BOOTLOADER_DOUBLE_TAP_RESET`, `PICO_XOSC_STARTUP_DELAY_MULTIPLIER 64`
   - `rules.mk`: `SERIAL_DRIVER = vendor`
7. **PCB housekeeping** (Phase 2 schematic): drop placements for Pimoroni Haptic, Mallory buzzer, MSK12C02 slide switch, JST-PH, custombatteryconnector, lvc27_onlyInput (74LVC2G17 buffer)
8. **Fork delta vs upstream:** 152 commits 100% Lefuneste83 work (118+34 alt identity). klor1_4 is Lefuneste's primary contribution. Rev 1.5 announced 2024-09-10 tapi PCB files NEVER committed → stay di klor1_4.

### PROJECT_SPEC.md corrections applied (this date)

- Tier 1 R1 wording updated dengan "21 keys + 1 knob per side"
- Tier 2 OLED 128×32 → **128×64**
- Tier 2 serial wire allocation → **half-duplex active GP1; GP4 routed reserve**
- Tier 2 matrix_pins → new col pin mapping `[GP27, GP26, GP13, GP12, GP11, GP10]`
- Tier 2 firmware config block added (Justin Lam settings — `keyboard.json` processor/bootloader, config.h defines, rules.mk SERIAL_DRIVER)
- MOD #3 status → "verify only"
- DROPPED list expanded (lvc27, battery items explicit)
- PCB modification scope clarified per Phase 1 risks

---

## Phase 2 — Schematic Mod · in progress (pending kickoff)

### Phase 2 prep tasks (before opening klor1_4 in KiCad 10)

1. **Install marbastlib via KiCad 10 PCM**
   - Document version installed
   - Audit RP2040-Zero footprint coverage
   - Audit USB-C 16-pin midmount footprint coverage
   - Fallback plan jika gaps: custom-build dari Waveshare datasheet + community footprints

2. **Create git branch** `kicad-10-migration` di `hardware/`
   - First KiCad 10 open will auto-migrate file format (irreversible)
   - Branch retains pre-migration state for rollback

3. **Open `klor1_4.kicad_pro` di KiCad 10 untuk first migration**
   - Verify migration dialog success
   - Run DRC immediately (catch KiCad 10 stricter rule violations)
   - Visual inspect schematic + PCB editor
   - Commit migration result

### Phase 2 deliverables — in progress

**Completed (branch `kicad-10-migration`):**
- ✅ KiCad 10 migration (commit `75b16dd`)
- ✅ Custom RP2040-Zero footprint added to KLOR.pretty (commit `4029b11`)
- ✅ RP2040-Zero symbol added to KLORlib (commit `f98d576`)
- ✅ Schematic MOD #1: ProMicro → RP2040-Zero, drop battery section, ERC clean (commit `ee98b40`)
- ✅ Schematic MOD #2: TRRS → USB-C 16-pin midmount + 5.1kΩ CC pulldowns + PWR_FLAG on 5V, ERC clean (commit `fa041cc`)

**Pending Phase 2:**
- ⏳ MOD #3 verify: confirm schematic instantiates `SK6812MINI_and_cherry_1` (not older variant) for all 42 LED positions
- ⏳ Drop remaining placements if still in schematic: Pimoroni Haptic DRV2605L, Mallory buzzer, `lvc27_onlyInput` 74LVC2G17 buffer
- ⏳ Annotate symbols (Tools → Annotate Schematic) — assign final refdes
- ⏳ Update PCB from schematic (F8 in PCB editor / Tools → Update PCB from Schematic)
- ⏳ Verify PCB DRC clean

**Spec updates APPLIED 2026-05-14** (doc-sync session — committed Phase 2 schematic decisions ke spec docs):
- ✅ Matrix col pins: revised from `[GP27, GP26, GP13, GP12, GP11, GP10]` (descending) to `[GP27, GP26, GP9, GP10, GP11, GP12]` (ascending — user-natural label order, accepted). Applied di [PROJECT_SPEC.md](PROJECT_SPEC.md) Matrix section + MOD #1 description, dan [PIN_MAPPING_PROPOSAL.md](docs/phase-1-recon/PIN_MAPPING_PROPOSAL.md) Sections C/D/E/J.
- ✅ col2 → GP9, col3 → GP10, col4 → GP11, col5 → GP12 (was GP13-GP10 in original spec)
- ✅ RESET button → GP15 (soft reset via firmware; user wants accessible reset, GP15 was spare). Documented di PROJECT_SPEC Matrix section + PIN_MAPPING Section C row.
- ✅ 5V net uses `+5V` power port + `PWR_FLAG` on 5V net (USB-C VBUS is passive type, needs PWR_FLAG to satisfy ERC). Documented sebagai new row "VBUS / 5V net" di PROJECT_SPEC Inter-half connector table.
- ✅ Spares now: GP13, GP14 (GP15 used for RESET, GP9 used for col2). PIN_MAPPING Section C total updated: 18 used / 2 spare (was 17 used / 3 spare).
- ⏳ **keyboard.json deferred ke Phase 6** — akan diupdate bareng Justin Lam config block (`processor`/`bootloader`/SERIAL_PIO_USE_PIO1/etc.)

---

### Phase 2 doc-sync session · 2026-05-14

Sebelum lanjut MOD #3 verify, sync spec docs ke actual schematic state (commits `ee98b40` + `fa041cc`) untuk avoid stale baseline going into Phase 3 PCB layout.

**Done:**
- ✅ ERC verified clean — [ERC.rpt](hardware/PCB/klor1_4/erc/ERC.rpt) timestamp `2026-05-14T18:32:30`: **0 errors, 0 warnings**
- ✅ PROJECT_SPEC.md sync (4 edits): header date + status, Inter-half VBUS row, Matrix section ascending + RESET note + spares table, MOD #1 pin remap text
- ✅ PIN_MAPPING_PROPOSAL.md sync (6 edits): Section C table, total usage, Section D JSON + logic, Section E compatibility table, Section J summary, Section I open items (3 resolved + 1 new)

**PWR_FLAG semantics clarification (user concern resolved):**
- User question: "MCU 5V ada PWR_FLAG, USB-C 5V tidak ada — aman?"
- Answer: **AMAN**. `power:+5V` symbol creates global label → SEMUA `+5V` symbols (di MCU dan di USB-C) auto-connected sebagai net `+5V` tunggal oleh KiCad netlister. PWR_FLAG bersifat net-level (bukan node-level); satu instance pada net `+5V` (`#FLG02` near MCU) satisfies ERC untuk seluruh net. PWR_FLAG tidak ada efek fisik (bukan footprint/pad/copper).
- Bukti: ERC 0 errors. Topology verified via symbol position mapping di `klor1_4.kicad_sch`: MCU U1 `(at 49.53, 36.83)`, USB-C J1 `(at 119.38, 30.48)`, `+5V` #PWR03 dekat MCU, `+5V` #PWR04 dekat USB-C, `PWR_FLAG` #FLG02 dekat MCU `+5V`.

**Pending Phase 2 (unchanged from previous session):**
- ⏳ MOD #3 verify (LED footprint `_1` variant for all 42 positions)
- ⏳ Drop residual placements (Haptic / buzzer / lvc27 — verify if still present)
- ⏳ Annotate schematic (final refdes)
- ⏳ Update PCB from Schematic (F8)
- ⏳ PCB DRC clean

### Phase 2 — MOD #3 + Housekeeping · 2026-05-14 (commit `17c1fb3`)

**MOD #3 LED south-facing verify** — ✅ done (no schematic change needed):
- 42/42 LED placement instances use `KLOR:SK6812MINI_and_cherry_1` (south-facing variant)
- 0 instances use older `Button_Switch_Keyboard:SK6812MINI_and_cherry` (only present as overridden library default)
- Footprint files both exist locally di `KLOR.pretty/`
- Verify pattern: pure file read on `klor1_4.kicad_sch` (no KiCad open required)

**Housekeeping (commit `17c1fb3`):**
- Dropped via KiCad GUI delete (user-side action):
  - BZ1 Mallory Buzzer (`Device:Buzzer` + `KLOR:Buzzer_Mallory_AST1109MLTRQ_reversible` footprint)
  - J2 Pimoroni Haptic Buzz DRV2605L (`Connector_Generic:Conn_01x05` + `KLOR:Pimoroni Haptic Buzz DRV2605L Driver` footprint)
  - J3 lvc27_onlyInput 74LVC2G17 buffer (`Connector_Generic:Conn_01x05` + `KLOR:lvc27_onlyInput` footprint)
  - **Trackball module section** — NEW DROPPED item discovered during cleanup. Was NOT in original DROPPED list. User explicitly decided to skip pointing-device feature scope. Updated PROJECT_SPEC.md + CONTRIBUTING.md DROPPED lists.
  - Cosmetic text labels: "HAPTIC FEEDBACK", "SPEAKER", "TRACKBALL MODULE"
- ERC re-verified clean: `0 errors, 0 warnings` per [ERC.rpt](hardware/PCB/klor1_4/erc/ERC.rpt) timestamp `2026-05-14T19:50:35`
- Critical components preserved (post-cleanup grep verification):
  - 42× `SW_PUSH-MX_W_LED` placement (= 42 keys × switch+LED composite symbol)
  - 1× RP2040-Zero, 1× USB-C 16-pin connector, 1× SSD1306 OLED, 1× Rotary Encoder
  - 22× `D_Small` matrix diode (pre-existing fork count, unchanged)

**Pending Phase 2 (updated):**
- ⏳ Annotate schematic (Tools → Annotate Schematic Symbols) — assign final refdes after housekeeping
- ⏳ Update PCB from Schematic (F8 in PCB Editor)
- ⏳ PCB DRC clean — likely flag orphan footprints from dropped components; Phase 3 PCB layout territory

---

## Phase 3 — PCB layout mod · pending
## Phase 4 — Gerbers + JLCPCB · pending
## Phase 5 — Assembly · pending
## Phase 6 — Firmware (Vial-QMK fork + RP2040-Zero config) · pending

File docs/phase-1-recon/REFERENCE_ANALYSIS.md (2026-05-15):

# Phase 1 / Deliverable #5 — REFERENCE_ANALYSIS

> Final Phase 1 deliverable. Synthesize: zerosprey42 schematic insights, Justin Lam handwired Skeletyl blog (RP2040-Zero firmware config), Lefuneste83 fork delta vs upstream, KiCad 10 migration risks, dan Phase 2 risk register.

---

## A. zerosprey42 cross-validation

[zerosprey42](../../references/zerosprey42/) = beekeeb's 42-key unibody RP2040-Zero keyboard. Direct exemplar untuk our MCU choice tapi topologi berbeda (monoblock vs split).

### A.1 RP2040-Zero pin → physical pad mapping (from schematic symbol)

Extracted dari [zerosprey42.kicad_sch](../../references/zerosprey42/pcb/zerosprey42.kicad_sch) Lines 396-484 — RP2040-Zero symbol pin definitions:

```
Side A (castellated edge row 1):                Side B (castellated edge row 2):
  pin 23 → GP0    (top)                            pin 1  → 5V/VBUS
  pin 22 → GP1                                     pin 2  → GND
  pin 21 → GP2                                     pin 3  → 3V3
  pin 20 → GP3                                     pin 4  → GP29
  pin 19 → GP4                                     pin 5  → GP28
  pin 18 → GP5                                     pin 6  → GP27
  pin 17 → GP6                                     pin 7  → GP26
  pin 16 → GP7                                     pin 8  → GP15
  pin 15 → GP8                                     pin 9  → GP14
  pin 14 → GP9    (bottom)
  pin 13 → GP10
  pin 12 → GP11
  pin 11 → GP12
  pin 10 → GP13
```

**Implications untuk Phase 3 PCB footprint:**
- RP2040-Zero punya 2 castellated edge rows + bottom ADC pad row
- Side A (14 pads, GP0-GP13) + Side B (top 3 = USB; 4-9 = GP14, GP15, GP26-29 = 6 pads)
- **Total accessible: 16 GPIO castellated + 4 ADC = 20 GPIO** ✓ matches earlier audit
- Pin number ↔ GPxx mapping = reference saat draw custom footprint dengan pin label assignment

### A.2 zerosprey42 vs our proposal — pin allocation comparison

zerosprey42 detailed pin allocation TIDAK extracted di Grep (schematic pakai wire connections tanpa explicit GPxx net labels — would need open di KiCad 10 untuk trace). 

Tapi dari README + screenshot:
- 42 keys monoblock unibody (single PCB, single MCU)
- Per-key diode + hotswap (matrix-scanned, COL2ROW)
- No inter-half serial (unibody → no split transport)
- Choc-spaced (not 19.05mm)

**Difference from our build:**
- Our build = **split** (2 halves, 2 MCUs, inter-half USB-C serial)
- Our pin priorities differ (need serial GP1+GP4, plus I²C OLED GP2/3)
- zerosprey42's wider pin freedom (no inter-half overhead) makes pin allocation more flexible

**Validation outcome:** zerosprey42 confirms RP2040-Zero works for 42-key keyboards dengan QMK+Vial firmware. Specific pin allocation TIDAK directly cross-reference-able, tapi feasibility validated.

> **Phase 2 follow-up:** Open `zerosprey42.kicad_sch` di KiCad 10 untuk extract exact pin nets (matrix col/row to GPxx wire connections). Optional — saat ini proposal kita already sound based on RP2040-Zero edge availability.

---

## B. Justin Lam handwired Skeletyl blog — RP2040-Zero firmware lessons

Source: https://www.justinmklam.com/posts/2025/08/handwired-skeletyl/

### B.1 Critical firmware config untuk bare RP2040-Zero

**`keyboard.json` essentials:**
```json
"bootloader": "rp2040",
"processor": "RP2040",
```

🚨 **Key gotcha:** Untuk **bare Waveshare RP2040-Zero**, jangan pakai `"development_board": "elite_pi"` (yang dipakai fork saat ini). Pakai explicit `processor` + `bootloader` instead. Author Justin Lam emphasize: "the bootloader and processor needed to just be RP2040 instead of the dev board."

> **Implication for fork:** Current fork's `keyboard.json:16` `"development_board": "elite_pi"` akan **break** untuk our RP2040-Zero target. Need switch ke `"bootloader": "rp2040"` + `"processor": "RP2040"`. Phase 6 firmware update task.

**`config.h` RP2040-Zero specific:**
```c
#define RP2040_BOOTLOADER_DOUBLE_TAP_RESET
#define RP2040_BOOTLOADER_DOUBLE_TAP_RESET_TIMEOUT 500U
#define PICO_XOSC_STARTUP_DELAY_MULTIPLIER 64
#define SERIAL_PIO_USE_PIO1
```

Explained per setting:
- **`RP2040_BOOTLOADER_DOUBLE_TAP_RESET`** → enable double-tap-reset-button to enter bootloader. Better UX vs holding BOOT pin saat power on (RP2040-Zero punya BOOT button onboard).
- **`RP2040_BOOTLOADER_DOUBLE_TAP_RESET_TIMEOUT 500U`** → 500ms window between two reset taps. Industry-standard timing.
- **`PICO_XOSC_STARTUP_DELAY_MULTIPLIER 64`** → extends crystal oscillator stabilization delay. Important untuk reliable boot — bare RP2040-Zero kadang ada XOSC startup issue, multiplier 64 = safer.
- **`SERIAL_PIO_USE_PIO1`** → explicitly use **PIO1** state machine block untuk inter-half serial. **Critical:** WS2812 RGB di GP0 already pakai PIO0 by default. Without PIO1 explicit, serial mungkin conflict dengan RGB → garbled comms.

**`rules.mk` RP2040-Zero specific:**
```make
SERIAL_DRIVER = vendor
```

`vendor` driver = QMK's RP2040-specific serial driver (PIO-based). Pairs with `SERIAL_PIO_USE_PIO1` define.

### B.2 Justin's pin allocation (reference, not adopted directly)

Justin's example untuk handwired Skeletyl:
- Columns: GP4-GP8 (5 cols)
- Rows: GP9-GP12 (4 rows)
- Soft serial: GP1
- Diode: COL2ROW

**Difference vs our proposal:** Different MCU pin layout (Justin's handwired Skeletyl = different topology). Pin choice tidak directly reusable, tapi confirms:
- GP1 = standard pick untuk serial (✓ matches our PIN_MAPPING_PROPOSAL)
- GP4-15 range = safe for matrix scanning (✓ matches our col remap to GP10-13)
- COL2ROW direction = standard (✓ matches fork's keyboard.json:17)

---

## C. Lefuneste83 fork delta vs upstream GEIGEIGEIST

### C.1 Quantitative summary

| Metric | Value |
|---|---|
| Fork commits ahead of upstream | **152** |
| Files changed | **248** |
| Author breakdown (fork-only) | Lefuneste83 (118) + Hilarion Lefuneste (34) = **152 commits 100% by fork maintainer** |

Top changed directories (fork delta):

| Files changed | Directory | Significance |
|---|---|---|
| 51 | `FIRMWARE/zmk` | ZMK config for Nice Nano BLE variants (Lefuneste maintains separate `zmk-config-klor` repo too) |
| 42 | `case/Alternate Case Design` | Community-contributed v2/v2.1 gasket designs (committed via merge into fork) |
| 41 | `PCB/klor1_4` | **klor1_4 = Lefuneste's primary contribution** — refactored PCB design, south-facing SK6812MINI-E |
| 41 | `PCB/klor1_4_LP_KS33` | Low-profile Gateron KS33 beta — Lefuneste's experimental variant |
| 21 | `PCB/klor1_3` | Legacy fixes (DRC cleanup for JLCPCB validation) |
| 19 | `docs/images` | Build guide images, Rev 1.5 renders (PCB files belum committed) |
| 19 | `FIRMWARE/qmk_rp2040` | QMK RP2040 modernization (elite_pi config, Vial keymap, full-duplex serial doc) |
| 8 | `FIRMWARE/Ready-to-flash` | Pre-built UF2 binaries (will become stale post-Phase 6) |

### C.2 Qualitative fork contributions (per CHANGELOG + commit messages)

**Lefuneste83's core contributions:**

1. **PCB Rev 1.4** — completely refactored layout dari Rev 1.3:
   - South-facing SK6812MINI-E (vs upstream's WS2812 3535 north-facing)
   - Re-routed 90% of traces, cleaned DRC errors
   - Triangular solder jumpers (vs upstream rectangular)
   - Dual ground planes
   - Logo change to Lefuneste's branding
   - 0 JLCPCB DRC errors

2. **PCB Rev 1.4 LP KS33** — low-profile beta dengan Gateron KS33 hotswap.

3. **QMK RP2040 modernization** — elite_pi development_board config, full Vial-QMK support, EE_HANDS firmware-based handedness, half-duplex serial transport documented.

4. **Rev 1.5 announcement (Sept 2024)** — major improvements (direct USB 5V, full duplex, hardware handedness, OLED voltage select) **TAPI PCB files tidak committed di repo**. Hanya renders + CHANGELOG description. Inactive since Sept 2024.

5. **DIY Haptic Module alternative** — DRV2605L DIY breakout untuk cost-saving vs Pimoroni's $15 module. **Dropped from our scope** per haptic decision.

### C.3 Anything to merge back (upstream PR potential)?

Tidak relevant untuk our project (we fork from Lefuneste83 directly), tapi noting:
- Lefuneste's klor1_4 mature enough untuk dianggap upstream-mergeable, tapi GEIGEIGEIST upstream stagnant (last commit 2024 buildguide_acrylic.md update only)
- Lefuneste83 maintains independent fork ecosystem (zmk-config-klor + klor-config + community contributions)

### C.4 Unique-to-fork vs upstream-shared

| Feature | Upstream | Lefuneste's fork |
|---|---|---|
| PCB Rev 1.3 | Original | Inherited + DRC fixes |
| PCB Rev 1.4 | ❌ Not present | ✅ Lefuneste's main work |
| PCB Rev 1.4 LP KS33 | ❌ Not present | ✅ Beta low-profile |
| PCB Rev 1.5 | ❌ Not present (renders only) | ⚠️ Announced, PCB files NOT committed |
| QMK RP2040 elite_pi config | ❌ AVR Pro Micro era | ✅ Lefuneste modernized |
| Vial firmware support | ❌ QMK only | ✅ Lefuneste added |
| ZMK NiceNano support | ⚠️ Initial | ✅ Lefuneste enhanced (separate repo) |
| Alternate community cases | ❌ | ✅ Merged community PRs |
| SK6812MINI-E reverse-mount (`_1` variant) | ❌ WS2812 3535 era | ✅ Lefuneste klor1_4 |

> **For us:** Starting from Lefuneste83's fork = right choice. Inherits everything modernized, RP2040-ready, south-facing LED, Vial support. We just need to swap MCU footprint + USB-C connector.

---

## D. KiCad 10 migration risk register

### D.1 Fork's KiCad file format versions

| File | Generator version | Likely KiCad era |
|---|---|---|
| `klor1_4.kicad_pro` | version 1 (`meta.version`) | KiCad 7/8 |
| `ProMicro.kicad_mod` | 20211014 | KiCad 6/7 |
| `MJ-4PP-9.kicad_mod` | 20240108 (generator 8.0) | KiCad 8 |
| `Diode_SOD123.kicad_mod` | 20240108 | KiCad 8 |
| `RotaryEncoder_..keebio_modified.kicad_mod` | 20221018 | KiCad 7 |
| `SSD1306_128x64OLED.kicad_mod` | 20211014 | KiCad 6/7 |
| `SK6812MINI_and_cherry.kicad_mod` | 20211014 | KiCad 6/7 |
| `SK6812MINI_and_cherry_1.kicad_mod` | 20240108 | KiCad 8 |

Fork = **mixed KiCad 6/7/8 format**. KiCad 10 will auto-migrate semua to v10 format.

### D.2 Migration risks

| Risk | Likelihood | Mitigation |
|---|---|---|
| Auto-migration breaks footprint references | Low | Run KiCad 10 migration dialog di branch terpisah; verify open visually before commit |
| Schematic symbol-to-footprint mappings break | Low-medium | KiCad 10 typically handles backward compat well; tapi some KiCad 6 footprints with deprecated syntax mungkin warning |
| 3D model `${KISYS3DMOD}` path resolution | Medium | KiCad 10 deprecated `KISYS3DMOD` in favor of `KICAD8_3DMODEL_DIR` / `KICAD9_3DMODEL_DIR`. May cause "3D model not found" warnings (cosmetic, doesn't block design) |
| Net class definitions migration | Low | Should auto-migrate |
| DRC rule changes (KiCad 10 stricter) | Medium | Re-run DRC after open; existing 0-error status mungkin reveal new warnings. Fix if blocker |
| Library table format change | Low | `fp-lib-table` already version 7 = KiCad 7+ format, KiCad 10 compatible |
| Custom layer setups | Low | Standard 2-layer FR4, no exotic layers |

### D.3 Migration workflow (Phase 2 start)

**Mandatory steps before first KiCad 10 open:**

1. ✅ `cd hardware && git checkout -b kicad-10-migration` — create dedicated branch *(historical: ran from `base-fork/KLOR/` before Phase 2 close flatten)*
2. ✅ Commit current state if uncommitted (currently 0 dirty per Phase 0 verification)
3. ✅ Verify KiCad 10.0.2 installed (Anda verified earlier)
4. ✅ **Optional but recommended:** Install marbastlib via PCM **before** opening klor1_4 (so KiCad 10 already knows about new libraries during migration scan)
5. ⚠️ Open `klor1_4.kicad_pro` di KiCad 10 → dialog "Migrate files? (Irreversible)" → click Yes
6. ⚠️ KiCad 10 akan generate `_backup` files dari originals
7. ✅ Run DRC immediately to check no new errors (especially after KiCad 10's stricter rules)
8. ✅ Commit migrated files dengan message: "KiCad 10 auto-migration from KiCad 6/7/8 format"
9. ✅ Visual inspect: open schematic + PCB editor, verify nothing broken

### D.4 Rollback plan

Kalau migration breaks something irrecoverable:
- `git checkout main` — back to pre-migration state (KiCad 6/7/8 format intact)
- Either install older KiCad version (e.g., KiCad 8 LTS) OR fix issues manually post-migration
- Migration branch retains progress

---

## E. Phase 2 risk register (consolidated from all Phase 1 findings)

| # | Risk | Severity | Probability | Mitigation |
|---|---|---|---|---|
| 1 | RP2040-Zero footprint marbastlib coverage | High | Medium | Verify marbastlib has RP2040-Zero footprint at Phase 2 start. Fallback: custom-build from Waveshare datasheet (~2-3 jam) |
| 2 | USB-C 16-pin midmount footprint marbastlib coverage | High | Medium | Same fallback plan. GCT USB4085 + HRO TYPE-C-31-M-12 are common community footprints; should be obtainable |
| 3 | KiCad 10 auto-migration of fork's mixed-version files | Medium | High | Branch-based approach (D.3). Test before commit |
| 4 | Schematic uses OLDER `SK6812MINI_and_cherry` variant (without south-facing cutout) | Low-medium | Low | FOOTPRINT_INVENTORY C.3 identified `_1` variant is the correct south-facing. Verify at Phase 2 schematic open. Replace older variant if found |
| 5 | RP2040-Zero **GP20-23 not exposed** = 4 col pins must remap | High | Confirmed | PIN_MAPPING_PROPOSAL section C locks new col pins. Apply at Phase 6 firmware update |
| 6 | `keyboard.json` uses `"development_board": "elite_pi"` but bare RP2040-Zero requires `"processor": "RP2040", "bootloader": "rp2040"` | High | Confirmed (B.1 Justin Lam finding) | Update keyboard.json at Phase 6 firmware step |
| 7 | Inter-half PIO serial conflict with WS2812 (both use PIO by default) | Medium | Possible | Set `SERIAL_PIO_USE_PIO1` di config.h → separates serial (PIO1) from WS2812 (PIO0). Justin Lam confirmed pattern |
| 8 | RP2040-Zero XOSC startup unreliability | Low-medium | Low | Add `PICO_XOSC_STARTUP_DELAY_MULTIPLIER 64` to config.h per Justin Lam recommendation |
| 9 | Bootloader access: BOOT button on RP2040-Zero hard to access in case | Medium | Likely | Enable `RP2040_BOOTLOADER_DOUBLE_TAP_RESET` for double-tap-reset entry (no need to touch BOOT button after first flash) |
| 10 | GP0 RGB chain entry trace routing from new MCU position | Medium | Likely | Phase 3 PCB layout concern — trace from RP2040-Zero GP0 pad to LED 00 entry. Plan early |
| 11 | Mill-Max sockets sourcing fail-over | Low (already mitigated) | Low | PIN_MAPPING + FOOTPRINT decisions already specify 1.27mm pin header instead of Mill-Max |
| 12 | 1.27mm female pin header height adds ~3mm vs Mill-Max — case clearance | Low-medium | Possible | Verify klor1_4 case STL has sufficient MCU clearance (~6mm stack height). May need case mod (not in scope; user accepts trade-off per PROJECT_SPEC) |
| 13 | USB-C 16-pin midmount cutout pada PCB | Low-medium | Likely (per part chosen) | Most midmount USB-C requires PCB edge cutout (slot ~3-4mm deep × 9mm wide). Plan Phase 3 layout |
| 14 | Fork's CC pins handling on USB-C unclear | Low | Possible | Phase 2 schematic: tie CC1/CC2 to 5.1kΩ pulldown to GND for "dumb sink" behavior (standard practice for power-only USB-C connectors) |
| 15 | Drop placements correctness (haptic/audio/battery footprints removal) | Low | Likely | Phase 2 schematic mod: delete instantiated components, verify net cleanup, re-run ERC |

---

## F. PROJECT_SPEC.md update queue (batch at end of Phase 1)

Compiled corrections dari Phase 1 #1-#5, to be applied di single batch update:

### F.1 Tier 1 REQUIREMENTS clarifications
- **R1** clarify: "42-key split keyboard polydactyl layout = 21 keys per side + 1 encoder/knob position per side (total 42 keys + 2 encoders)" — explicit per user confirmation

### F.2 Tier 2 COMPONENT DECISIONS updates
- **OLED:** 128×32 → **128×64** (fork-native; firmware tuned for 128×64; tukar tidak worth it)
- **Inter-half wire allocation:** "full-duplex" → "**half-duplex active GP1; GP4 reserved for full-duplex upgrade (both pads routed pada PCB)**"
- **Matrix col pins remap** added: `GP27, GP26, GP13, GP12, GP11, GP10` (4 of 6 remapped untuk RP2040-Zero edge availability)
- **MOD #3 status:** scope reduces to "verify only" (klor1_4's `SK6812MINI_and_cherry_1` footprint already south-facing per FOOTPRINT_INVENTORY C.3)

### F.3 New firmware config additions (for Phase 6)
Per Justin Lam blog findings:
```c
// config.h additions (RP2040-Zero specific):
#define RP2040_BOOTLOADER_DOUBLE_TAP_RESET
#define RP2040_BOOTLOADER_DOUBLE_TAP_RESET_TIMEOUT 500U
#define PICO_XOSC_STARTUP_DELAY_MULTIPLIER 64
#define SERIAL_PIO_USE_PIO1
```

```make
# rules.mk:
SERIAL_DRIVER = vendor
```

```json
// keyboard.json changes:
// Remove: "development_board": "elite_pi"
// Add:    "processor": "RP2040", "bootloader": "rp2040"
// Update: "matrix_pins.cols": ["GP27","GP26","GP13","GP12","GP11","GP10"]
```

### F.4 PCB scope (housekeeping additions)
Beyond 3 main mods, drop placements (Phase 2 schematic):
- Pimoroni Haptic DRV2605L (haptic out)
- Mallory buzzer (audio out)
- MSK12C02 slide switch (battery out)
- JST-PH connector (battery out)
- `custombatteryconnector_small` (battery out)
- `lvc27_onlyInput` (74LVC2G17 buffer — likely haptic-related, verify and remove if so)

---

## G. Cross-references

- [INVENTORY.md](INVENTORY.md) — Phase 1 #1 file census
- [MATRIX_VALIDATION.md](MATRIX_VALIDATION.md) — Pin assignment audit + GPIO budget
- [FOOTPRINT_INVENTORY.md](FOOTPRINT_INVENTORY.md) — Library audit
- [PIN_MAPPING_PROPOSAL.md](PIN_MAPPING_PROPOSAL.md) — Final pin allocation + col remap
- [zerosprey42 README](../../references/zerosprey42/README.md) — RP2040-Zero exemplar
- [zerosprey42 schematic](../../references/zerosprey42/pcb/zerosprey42.kicad_sch) — RP2040-Zero symbol pin definitions (Phase 2 detailed extraction TBD)
- [Justin Lam blog](https://www.justinmklam.com/posts/2025/08/handwired-skeletyl/) — RP2040-Zero firmware config gotchas
- [PROJECT_SPEC.md](../../PROJECT_SPEC.md) — to be batch-updated dengan F.1-F.4
- [PHASE_LOG.md](../../PHASE_LOG.md) — to be appended dengan Phase 1 completion

---

## H. Phase 1 deliverable status

| # | Deliverable | Status | File |
|---|---|---|---|
| 1 | INVENTORY | ✅ Done | [docs/phase-1-recon/INVENTORY.md](INVENTORY.md) |
| 2 | MATRIX_VALIDATION | ✅ Done | [docs/phase-1-recon/MATRIX_VALIDATION.md](MATRIX_VALIDATION.md) |
| 3 | FOOTPRINT_INVENTORY | ✅ Done | [docs/phase-1-recon/FOOTPRINT_INVENTORY.md](FOOTPRINT_INVENTORY.md) |
| 4 | PIN_MAPPING_PROPOSAL | ✅ Done | [docs/phase-1-recon/PIN_MAPPING_PROPOSAL.md](PIN_MAPPING_PROPOSAL.md) |
| 5 | REFERENCE_ANALYSIS | ✅ **Done (this doc)** | [docs/phase-1-recon/REFERENCE_ANALYSIS.md](REFERENCE_ANALYSIS.md) |

**Phase 1 Recon COMPLETE.** Ready untuk transition ke Phase 2 Schematic Mod.

---

## I. Recommended next step

**Pending batch update:** [PROJECT_SPEC.md](../../PROJECT_SPEC.md), [CONTRIBUTING.md](../../CONTRIBUTING.md), [PHASE_LOG.md](../../PHASE_LOG.md) dengan F.1-F.4 corrections + Phase 1 completion status.

After batch update, Phase 2 prep:
1. Install marbastlib via KiCad PCM
2. Create `kicad-10-migration` branch di `hardware/`
3. Open `klor1_4.kicad_pro` for first KiCad 10 migration
4. Verify migration success + run DRC
5. Begin schematic mod (start dengan MCU footprint replacement)

Confirm "go" untuk batch update file root, atau ada catatan untuk REFERENCE_ANALYSIS.md dulu?

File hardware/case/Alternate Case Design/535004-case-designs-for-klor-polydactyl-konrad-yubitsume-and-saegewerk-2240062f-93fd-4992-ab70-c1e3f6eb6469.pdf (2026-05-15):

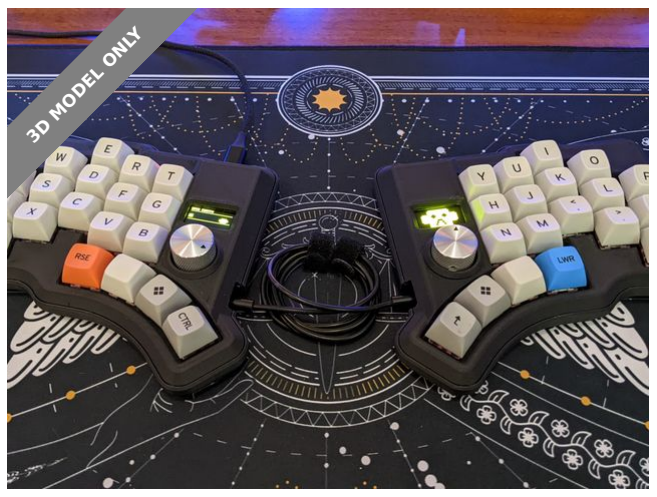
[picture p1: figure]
3D MODEL ONLY

## Summary

This is a case design for all four variants of the KLOR by GEIST

Gadgets (https://printables.com/model?categoryId=21) > Other Gadgets (https://printables.com/model?categoryId=43)

These are gasket mount case designs with optional tenting for KLOR. All four variants are supported. The top and bottom pieces fasten with 6mm x 3mm neodymium magnets. The optional tenting fastens via M3 heatset inserts. The lid pieces support encoder knobs up to 24mm. There are encoder inserts to accommodate knobs of a smaller diameter (20mm and 16mm).

IMPORTANT: The case design requires the MCU be mounted on TOP of the PCB with its components facing up. MCU sockets are recommended. The OLED screens were mounted with IC SIP sockets to allow it to be mounted low enough to fit in the case. Some low profile MCU sockets would also suffice.

M3 Inserts: https://www.amazon.com/gp/product/B09ZNXRD2H/ref=ppx_yo_dt_b_search_asin_title?ie=UTF8&th=1 (https://www.amazon.com/gp/product/B09ZNXRD2H/ref=ppx_yo_dt_b_search_asin_title?ie=UTF8&th=1)

Magnets: https://www.amazon.com/DIYMAG-6x3mm-Refrigerator-Premium-Brushed/dp/B07KZQGWNN (https://www.amazon.com/DIYMAG-6x3mm-Refrigerator-Premium-Brushed/dp/B07KZQGWNN)

chewiedies (https://printables.com/@chewiedies_360738)

## Case designs for

KLOR (Polydactyl,
Konrad, Yubitsume,

## and Saegewerk,)

VIEW IN BROWSER (https://printables.com/model/535004-case-designs-for-klor-polydactyl-konrad-yubitsume)

updated 2. 7. 2024 | published 2. 7. 2024

## Model files

3mm Foam: https://www.amazon.com/Neoprene-Adhesive-Padding-Multi-Function-Soundproof/dp/B08RB2FWVR/?th=1 (https://www.amazon.com/Neoprene-Adhesive-Padding-Multi-Function-Soundproof/dp/B08RB2FWVR/?th=1)

1mm Foam: https://www.amazon.com/gp/product/B07L6KV4QG/ref=ppx_yo_dt_b_search_asin_title?ie=UTF8&psc=1 (https://www.amazon.com/gp/product/B07L6KV4QG/ref=ppx_yo_dt_b_search_asin_title?ie=UTF8&psc=1)

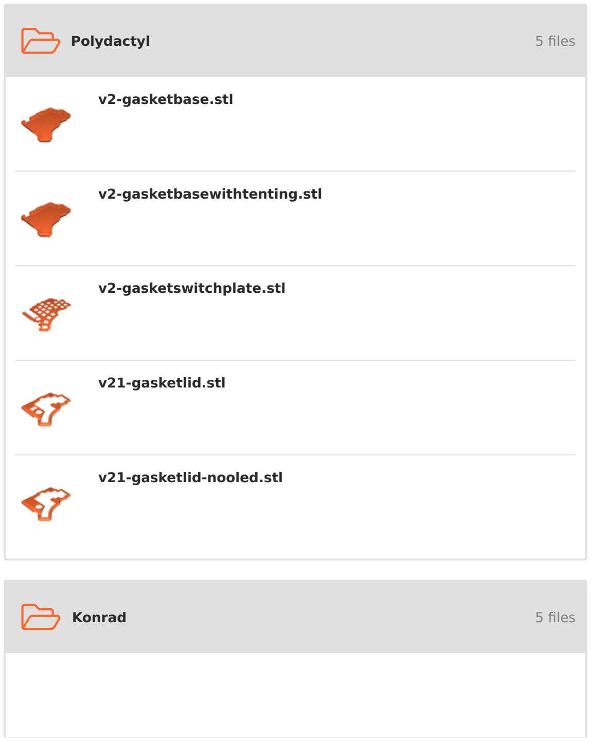
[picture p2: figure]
Polydactyl; 5 files; Konrad; v2-gasketbase.stl; v2-gasketbasewithtenting.stl; v2-gasketswitchplate.stl; v21-gasketlid.stl; v21-gasketlid-nooled.stl

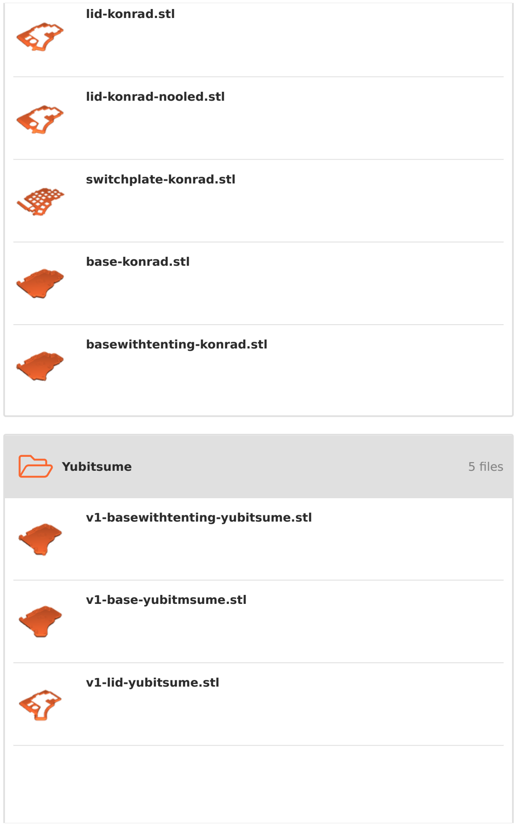
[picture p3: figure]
Yubitsume; 5 files; lid-konrad.stl; lid-konrad-nooled.stl; switchplate-konrad.stl; base-konrad.stl; basewithtenting-konrad.stl; v1-basewithtenting-yubitsume.stl; v1-base-yubitmsume.stl; v1-lid-yubitsume.stl

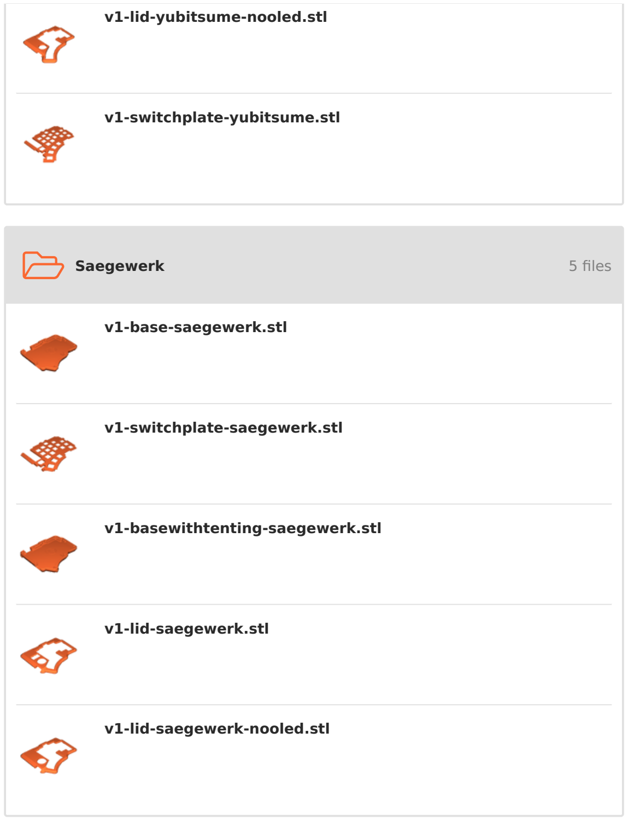
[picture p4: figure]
Saegewerk; 5 files; v1-lid-yubitsume-nooled.stl; v1-switchplate-yubitsume.stl; v1-base-saegewerk.stl; v1-switchplate-saegewerk.stl; v1-basewithtenting-saegewerk.stl; v1-lid-saegewerk.stl; v1-lid-saegewerk-nooled.stl

encoderinsert-flat-16mm.stl

## License

This work is licensed under a
Creative Commons (4.0 International License)

Attribution—Noncommercial—Share Alike (http://creativecommons.org/licenses/by-nc-sa/4.0/)

✖ | Sharing without ATTRIBUTION
✔ | Remix Culture allowed
✖ | Commercial Use
✖ | Free Cultural Works
✖ | Meets Open Definition

encoderinsert-flat.stl

encoderinsert-16mm.stl

encoderinsert.stl

klor-case-designs-v52.step

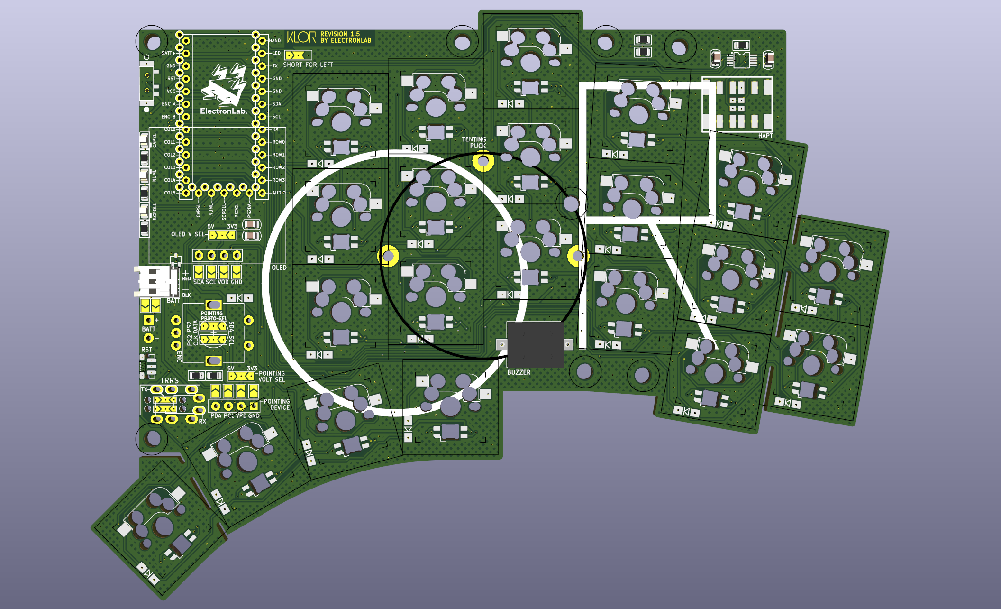
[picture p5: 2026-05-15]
hardware/docs/images/KLOR_1.5.png

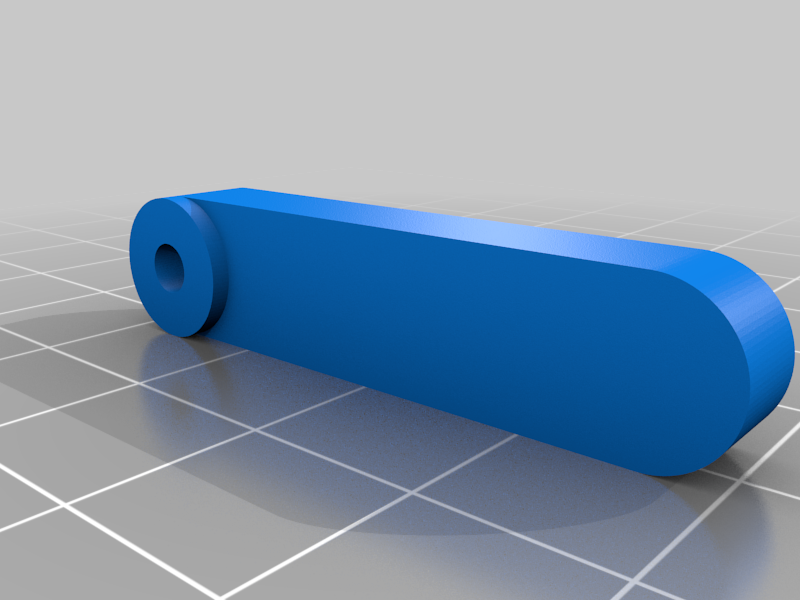
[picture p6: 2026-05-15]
hardware/case/Alternate Case Design/Tenting Legs/images/tentingleg36mm.png

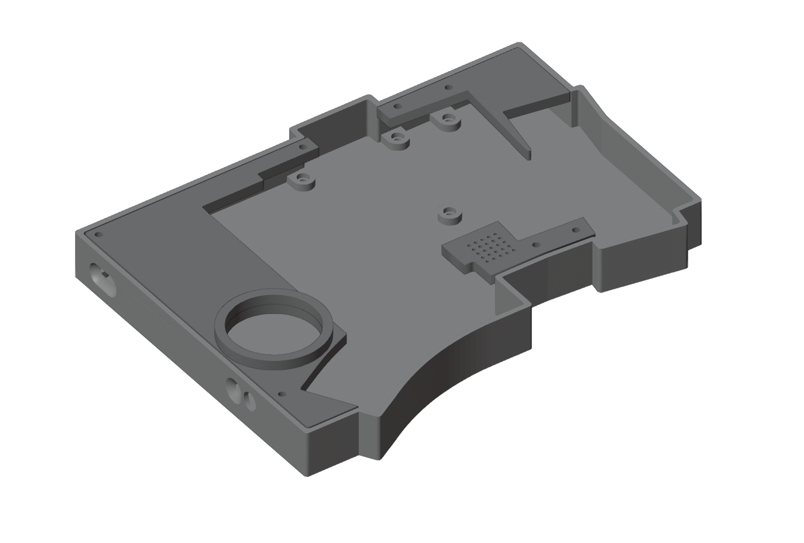
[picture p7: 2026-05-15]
hardware/case/docs/images/saegewerk_3dp_ble.png

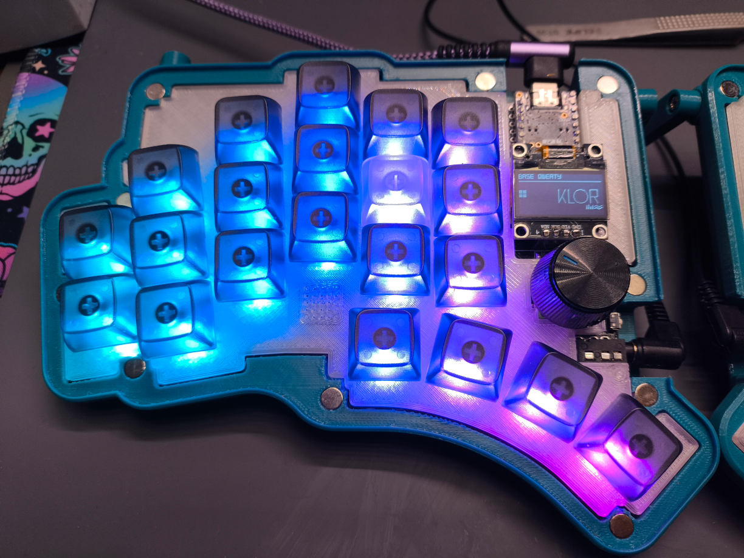
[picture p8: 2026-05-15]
hardware/docs/images/KLOR_1.5_picture3.png

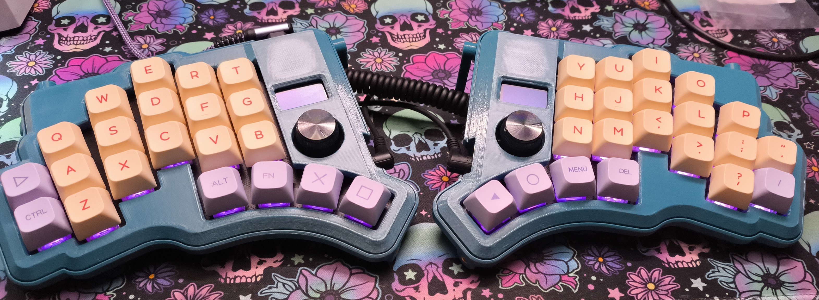
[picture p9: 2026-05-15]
hardware/docs/images/Klor_1.4_picture6.jpg

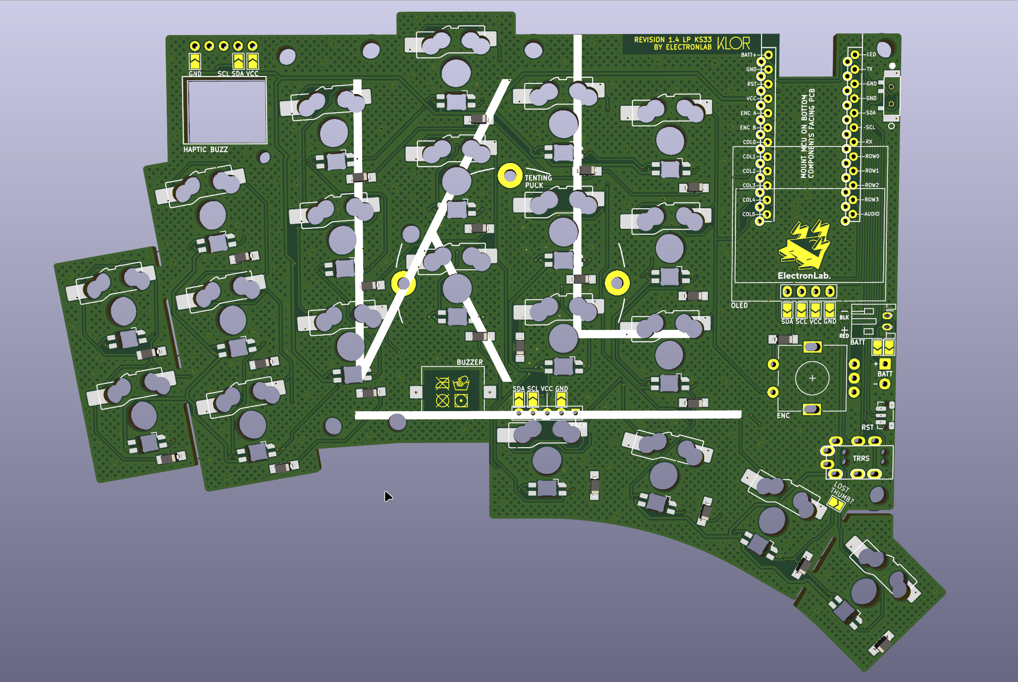
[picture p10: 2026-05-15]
hardware/docs/images/Klor_1.4_picture8.png

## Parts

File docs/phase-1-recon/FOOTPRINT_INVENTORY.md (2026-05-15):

# Phase 1 / Deliverable #3 — FOOTPRINT_INVENTORY

> Audit footprints di `hardware/PCB/klor1_4/`. Identifikasi library source per footprint, analyze mod-critical footprints (orientation, pad compat), list footprints baru yang harus ditambah untuk modifications.

---

## A. Library setup (klor1_4 project)

### Project-local libraries (fp-lib-table & sym-lib-table)

[fp-lib-table](../../hardware/PCB/klor1_4/fp-lib-table) (project root):
```
(fp_lib_table (version 7)
  (lib (name "KLOR")(type "KiCad")(uri "${KIPRJMOD}/KLOR.pretty")(options "")(descr ""))
)
```

[sym-lib-table](../../hardware/PCB/klor1_4/sym-lib-table):
```
(sym_lib_table (version 7)
  (lib (name "KLORlib")(type "KiCad")(uri "${KIPRJMOD}/KLORlib.kicad_sym")(options "")(descr ""))
)
```

**Implication:** Project-local library cuma satu = **KLOR.pretty** (footprints) + **KLORlib.kicad_sym** (symbols). Semua footprint dan symbol "non-KLOR" datang dari **KiCad global libraries** (instal sistem) — yaitu standard KiCad footprint libraries (Resistor_SMD, Diode_SMD, dll) yang sudah jadi default install.

**Important:** **marbastlib (Bastardkb) NOT installed/referenced di project.** Kalau marbastlib ada di KiCad PCM globally, footprint-nya accessible via global lib path; tapi tidak ada explicit reference di project.

### Library setup yang perlu Phase 2

Sebelum modify schematic Phase 2:
1. **Install marbastlib** via KiCad PCM (Plugin & Content Manager) — kemungkinan besar source untuk RP2040-Zero footprint dan USB-C midmount. Verify version compatible dengan KiCad 10.0.2.
2. **Add marbastlib ke project's `fp-lib-table`** (optional — could juga rely on global table)
3. **Atau:** clone marbastlib repo manual + reference via `${KIPRJMOD}/marbastlib/...`

---

## B. Inventory: KLOR.pretty footprints (17 entries di klor1_4)

| # | Footprint | Type | Pad placement | Generator | Source | Mod relevance |
|---|---|---|---|---|---|---|
| 1 | `ProMicro` | TH | Dual-side reversible | 20211014 (KiCad 6/7) | **Custom/KLOR** | 🚨 **MOD #1 — REPLACE** with RP2040-Zero |
| 2 | `MJ-4PP-9` | TH | Dual-side reversible | 20240108 (KiCad 8) | Custom/KLOR | 🚨 **MOD #2 — REPLACE** with USB-C |
| 3 | `SK6812MINI_and_cherry` | TH + SMD hybrid | Dual-side reversible | 20211014 | Custom/KLOR | ✅ Per-key LED+switch combined (older variant) |
| 4 | `SK6812MINI_and_cherry_1` | TH + SMD hybrid | Dual-side reversible + Edge.Cuts cutout | 20240108 (KiCad 8) | Custom/KLOR | ✅ **South-facing refined variant** (see C.3) |
| 5 | `Diode_SOD123` | SMD | Dual-side reversible | 20240108 | Custom/KLOR (override) | ✅ KEEP — fork's own SOD-123 with dual-side pads |
| 6 | `RotaryEncoder_Alps_EC11E-...keebio_modified` | TH | Single-side | 20221018 | Keebio-derived | ✅ KEEP encoder (R7) |
| 7 | `SSD1306_128x64OLED` | TH | Single-side | 20211014 | Custom/KLOR | ⚠️ See C.4 |
| 8 | `SW_Push_1P1T-MP_NO_Horizontal_Alps_SKRTLAE010_both_sides` | TH | Dual-side reversible | (unread) | Custom/KLOR | ✅ KEEP — reset switch |
| 9 | `MSK12C02_reversible` | TH | Dual-side reversible | (unread) | Custom/KLOR | 🗑️ Drop (battery/power switch, wired-only build) |
| 10 | `JST_PH_reversible` | TH | Dual-side reversible | (unread) | Custom/KLOR | 🗑️ Drop (no battery — wired only) |
| 11 | `custombatteryconnector_small` | TH | Dual-side | (unread) | Custom/KLOR | 🗑️ Drop (no battery) |
| 12 | `Buzzer_Mallory_AST1109MLTRQ_reversible` | TH | Dual-side | (unread) | Custom/KLOR | 🗑️ Drop (audio out of scope) |
| 13 | `Pimoroni Haptic Buzz DRV2605L Driver` | TH | Dual-side | (unread) | Custom/KLOR | 🗑️ Drop (haptic out of scope) |
| 14 | `lvc27_onlyInput` | SMD | Single-side | (unread) | Custom/KLOR | 🗑️ Probably drop (74LVC2G17 buffer — likely haptic/audio-related) |
| 15 | `R_1206_DoubleSided` | SMD | Dual-side | (unread) | Custom/KLOR | ✅ KEEP — resistor for jumper pullups |
| 16 | `Jumper` | SMD | Dual-side | (unread) | Custom/KLOR | ✅ KEEP — solder jumper triangle (FABNOTES mentions triangular shape) |
| 17 | `SplitkbTentingPuckWithoutCenterHole` | TH/NPTH | Single-side | (unread) | Custom/KLOR | ✅ KEEP — SplitKB puck mounting |

**Observations:**
- All footprints are **custom in `KLOR.pretty`** (project-local) — none reference external lib like marbastlib
- Mix dari generator versions: 20211014 (KiCad 6/7), 20221018, 20240108 (KiCad 8) → KiCad 10 akan auto-migrate semuanya (irreversible). Backup branch wajib sebelum first open.
- Mayoritas dual-side reversible footprints — sophisticated design untuk PCB mirror image (same PCB for both halves, mounted on opposite sides)

---

## C. Mod-critical footprint analysis

### C.1 `ProMicro.kicad_mod` — TO REPLACE (MOD #1)

Source: [hardware/PCB/klor1_4/KLOR.pretty/ProMicro.kicad_mod](../../hardware/PCB/klor1_4/KLOR.pretty/ProMicro.kicad_mod)

| Property | Value |
|---|---|
| Pin count | 24 (2 rows × 12 pins per row) |
| Pin spacing | 2.54mm (0.1" standard header) |
| Pad diameter | 1.524mm, drill 0.8128mm |
| Form factor | Pro Micro standard (~17.8mm × 32mm pad-to-pad) |
| Mount style | Through-hole, dual-side reversible (pads di F.Cu DAN B.Cu untuk kedua row) |
| Outline | F.SilkS dan B.SilkS rectangle |

**Why replace:** Pin pitch 2.54mm (Pro Micro form-factor) tidak match Waveshare RP2040-Zero yang punya pitch **1.27mm** di castellated edge (23-pin per side, 46 total + 4 ADC pad di bawah). Pad arrangement berbeda completely.

**Verdict:** Custom footprint baru wajib untuk RP2040-Zero. See D.1.

### C.2 `MJ-4PP-9.kicad_mod` — TO REPLACE (MOD #2)

Source: [MJ-4PP-9.kicad_mod](../../hardware/PCB/klor1_4/KLOR.pretty/MJ-4PP-9.kicad_mod)

| Property | Value |
|---|---|
| Pin count | 4 signal pins + 4 NPTH mounting holes |
| Type | 3.5mm TRRS jack, vertical mount |
| Pad shape | Oval 1.7 × 2.5mm, drill oval 1 × 1.5mm |
| Mount style | TH, dual-side reversible |
| Generator version | 20240108 (KiCad 8) — newer format |

**Why replace:** Spec project ganti TRRS → USB-C 16-pin midmount. Completely different connector + pad arrangement. See D.2.

### C.3 ✅ `SK6812MINI_and_cherry_1.kicad_mod` — SOUTH-FACING VERIFIED

Source: [SK6812MINI_and_cherry_1.kicad_mod](../../hardware/PCB/klor1_4/KLOR.pretty/SK6812MINI_and_cherry_1.kicad_mod)

**Key findings:**
- Footprint **combines MX switch + WS2812-style 4-pin LED** in single component
- 4 LED pads dengan **dual-layer placement** (F.Cu + B.Cu) di setiap pad — supports mounting LED pada F.Cu (north-facing) atau B.Cu (south-facing)
- Punya **Edge.Cuts cutout zone** (rect ~3.5mm × 4.5mm) — ini lubang fisik di PCB tempat LED light SHINES THROUGH dari bottom ke top side
- Punya **chamfered pads** (pin 1 indicator) — design refinement
- Has CUTOUT zone keepout (no copper around LED window) — supports south-facing optical clearance

**Conclusion:** `SK6812MINI_and_cherry_1` adalah **south-facing variant yang mature**. The `_1` suffix = newer iteration after fork README:37 ("moved to south-facing LED").

**Difference vs original `SK6812MINI_and_cherry`:**
- Original: pad shape `rect` (square corners), no Edge.Cuts cutout, no chamfer
- `_1`: pad shape `roundrect` (rounded), Edge.Cuts cutout for optical pass-through, chamfered pin 1

> **Verdict for MOD #3:** ✅ **`_1` variant already supports south-facing reverse-mount SK6812MINI-E**. Hipotesis di MATRIX_VALIDATION F.2 confirmed — **MOD #3 reduces to "verify klor1_4 schematic uses `_1` variant"** (not the original variant). Likely yes per fork README intent, but confirm di Phase 2 saat open schematic. **NO new footprint needed.**

**Bonus finding:** Both LED variants (`_1` and original) have **19.05mm × 19.05mm reference square** on Dwgs.User layer — confirming key spacing R1.

### C.4 ✅ `SSD1306_128x64OLED.kicad_mod` — Pad PIN-COMPATIBLE

Source: [SSD1306_128x64OLED.kicad_mod](../../hardware/PCB/klor1_4/KLOR.pretty/SSD1306_128x64OLED.kicad_mod)

| Property | Value |
|---|---|
| Pin count | 4 (VCC, GND, SCL, SDA — standard I²C OLED breakout) |
| Pin pitch | **2.54mm** (10.6 / 4 = 2.54) — verified from pad positions: -3.62, -1.08, 1.46, 4 |
| Pad shape | Oval 2 × 1.6mm, drill 1mm |
| Outline (B.SilkS / F.SilkS rect) | ~27.4mm × 27.3mm — matches **0.96" 128×64 module** physical size |

**Pin compatibility analysis:**

Universal 4-pin I²C OLED breakout modules (both 0.91" 128×32 dan 0.96" 128×64) menggunakan **identical 4-pin header @ 2.54mm pitch** dengan urutan (VCC, GND, SCL, SDA). **Footprint pad layout WORKS for both resolutions.**

**Outline compatibility:**
- 0.96" 128×64 module: ~27 × 27mm → fits footprint outline ✓
- 0.91" 128×32 module: ~30 × 11mm (taller × narrower) → fits pin holes tapi outline tidak match

**Decision (MATRIX_VALIDATION F.2 confirmed):** **Use 0.96" 128×64 module.** Footprint native compatible. No new footprint needed.

### C.5 ✅ `RotaryEncoder_Alps_EC11E-...keebio_modified.kicad_mod`

Source: [RotaryEncoder_Alps_EC11E-Switch_Vertical_H20mm-keebio_modified.kicad_mod](../../hardware/PCB/klor1_4/KLOR.pretty/RotaryEncoder_Alps_EC11E-Switch_Vertical_H20mm-keebio_modified.kicad_mod)

| Property | Value |
|---|---|
| Pin count | 5 signal (A, B, C, S1, S2) + 2 MP mechanical |
| Origin | Alps EC11E datasheet, modified from Keebio's library |
| 3D model | `${KISYS3DMOD}/Rotary_Encoder.3dshapes/...wrl` (KiCad built-in) |
| Mount style | TH, vertical shaft, H20mm height |

**Verdict:** ✅ KEEP unchanged. Standard EC11 encoder footprint, sourceable Tokopedia.

### C.6 ✅ `Diode_SOD123.kicad_mod`

Source: [Diode_SOD123.kicad_mod](../../hardware/PCB/klor1_4/KLOR.pretty/Diode_SOD123.kicad_mod)

| Property | Value |
|---|---|
| Package | SOD-123 (SMD) |
| Pad shape | Rect 1.8 × 1.5mm, drill 0.4mm (slight pad-hole hybrid) |
| Mount | Dual-side reversible (pads on `*.Cu` and `*.Paste`/`*.Mask` semua layers) |
| 3D model | `${KISYS3DMOD}/Diode_SMD.3dshapes/D_SOD-123.wrl` |

**Note:** Fork's variant punya **drill 0.4mm** even on SMD pads — ini hybrid SMD/TH design supaya bisa solder either way. Standard SOD-123 = pure SMD tanpa drill, fork's = SMD pad + small through-hole pin assist.

**Verdict:** ✅ KEEP — fork-specific reliability tweak for matrix diodes.

---

## D. New footprints needed for mods

### D.1 🚨 Waveshare RP2040-Zero footprint — MUST ADD

**Specification (per Waveshare wiki):**
- 23 pins per side castellated edge + 4 ADC pads di bottom = 50 total pad positions
- 20 GPIO accessible (some pads are GND/power/USB)
- Pin pitch: **1.27mm (0.05") on castellated edge**, custom pitch on bottom ADC pads
- Board dimensions: 18mm × 23.5mm
- Through-hole or surface-mount castellated (can solder edge-on-edge or via pin headers)

**Sourcing options:**

| Source | Pros | Cons |
|---|---|---|
| **marbastlib** (Bastardkb KiCad lib) | Well-maintained, supports KiCad 10 | Need to install via PCM + verify RP2040-Zero coverage (cek docs sebelum lock-in) |
| **Community footprint** (GitHub kiboard libraries) | Usually free, KiCad-native | Quality varies; may need verification with calipers |
| **Custom footprint** (build dari datasheet) | Full control, exact spec match | Time investment (~1-2 jam Phase 2); requires careful dimension verification |
| **boardsource/kicad-rp2040-zero** | Open source community | Verify maintenance status |

**Decision (Claude, Phase 2):** **Primary path = marbastlib.** Bastardkb known to support RP2040-based custom builds. Install PCM → verify footprint exists → use. **Fallback:** custom footprint dari Waveshare datasheet jika marbastlib coverage tidak ada.

**Note untuk socketing (R10):** Footprint harus support 1.27mm pitch female header pad arrangement — bukan langsung solder castellated. Typical pattern: through-hole pads di 1.27mm pitch yang line-up dengan castellated edge of RP2040-Zero. User insert RP2040-Zero ke pin headers vertically.

### D.2 🚨 USB-C 16-pin midmount SMD footprint — MUST ADD

**Specification target:**

Two candidate part numbers (final pick di Phase 2):

| Part | Pin count | Mount | LCSC stock | Footprint source candidate |
|---|---|---|---|---|
| **GCT USB4085** | 16 SMD | Midmount | Yes (good stock) | marbastlib likely; also community libs |
| **HRO TYPE-C-31-M-12** | 16 SMD | Midmount | Yes | Generic Type-C breakout, community footprints abundant |

Both share **16-pin SMD midmount form factor**. Pin allocation typical:
- A1, B12: GND
- A4, B9: VBUS
- A5: CC1, B5: CC2 (USB-C role detection)
- A6, B7: D+
- A7, B6: D-
- A2, A3, B10, B11: TX/RX SuperSpeed pairs (we ignore)
- A8, B8: SBU1, SBU2 (not used)
- A9, B4: extra contacts (often unused on basic breakouts)

**Decision (Claude, Phase 2):** Lock specific part di Phase 2 after marbastlib audit. Both parts have same footprint pad arrangement (16-pin SMD), so PCB design can proceed dengan generic 16-pin midmount footprint; final part sourcing depends on JLCPCB/LCSC stock pas-PCB order day.

**Wire usage** (per MATRIX_VALIDATION D):
- VBUS, GND: power
- D+ (single pin): half-duplex serial → GP1 ↔ GP1 inter-half
- D- (single pin): reserved for full-duplex serial upgrade → GP4 ↔ GP1 cross (when enabled)
- CC1/CC2: tied to 5.1kΩ pulldowns? Or NC for "dumb" sink behavior. Phase 2 schematic detail.
- Other pins: unused/NC

### D.3 ✅ SK6812MINI-E reverse-mount — NOT NEEDED

**Already covered by `SK6812MINI_and_cherry_1` footprint** (see C.3). South-facing reverse-mount supported via dual-layer pad placement and Edge.Cuts cutout zone. **MOD #3 reduces to "ensure klor1_4 schematic uses `_1` variant, not the older `SK6812MINI_and_cherry`."**

Phase 2 task: open schematic, verify all 42 LED positions instantiate `SK6812MINI_and_cherry_1`, replace any using older variant.

---

## E. marbastlib expected coverage (informational)

[marbastlib (Bastardkb)](https://github.com/Bastardkb/bastardkb-kicad-libraries) typically provides:

| Category | Coverage | Relevant to us? |
|---|---|---|
| RP2040 modules | RP2040-Zero, Pro Micro RP2040 variants | ✅ D.1 |
| USB-C connectors | Multiple midmount variants | ✅ D.2 |
| MX hotswap sockets | Kailh, Gateron, Outemu | (already have via custom KLOR variant) |
| SK6812 LEDs | Multiple orientation variants | (already have via `_1`) |
| TRRS jacks | Multiple variants | (not used — we're replacing TRRS) |

**Action item Phase 2 start:** Install marbastlib via PCM, audit which of D.1/D.2 footprints available. Document version installed for reproducibility.

---

## F. Library audit summary (Phase 2 prep)

| Action | Priority | Owner | Phase |
|---|---|---|---|
| Install marbastlib via KiCad 10 PCM | High | User (or via instructions saya) | Phase 2 start |
| Verify marbastlib has RP2040-Zero footprint | High | Claude (post-install) | Phase 2 |
| Verify marbastlib has USB-C 16-pin midmount | High | Claude (post-install) | Phase 2 |
| Build custom RP2040-Zero footprint (fallback) | Conditional | Claude — if marbastlib gap | Phase 2 |
| Build custom USB-C midmount footprint (fallback) | Conditional | Claude — if marbastlib gap | Phase 2 |
| Confirm schematic uses `SK6812MINI_and_cherry_1` (not older) | Medium | Claude — open schematic Phase 2 | Phase 2 |
| Remove placements: Pimoroni Haptic, Buzzer, MSK12C02, JST_PH, lvc27, custombatteryconnector | Medium | Phase 2 schematic mod | Phase 2 |
| Delete unused footprint files dari KLOR.pretty (cleanup) | Low | Optional — keep for fork reference | Phase 3 |

---

## G. Cross-references

- [INVENTORY.md](INVENTORY.md) — Phase 1 #1 file census
- [MATRIX_VALIDATION.md](MATRIX_VALIDATION.md) — Pin assignments
- [PROJECT_SPEC.md](../../PROJECT_SPEC.md) — Component decisions
- [hardware/PCB/klor1_4/KLOR.pretty/](../../hardware/PCB/klor1_4/KLOR.pretty/) — All custom footprints
- [marbastlib (GitHub)](https://github.com/Bastardkb/bastardkb-kicad-libraries) — Expected source for new footprints

## H. Open items (Phase 1 #4 + Phase 2 to resolve)

1. **Final col-pin remap GP10-15 specific assignment** → Phase 1 #4 PIN_MAPPING_PROPOSAL
2. **marbastlib version installation + audit** → Phase 2 start
3. **Confirm klor1_4 schematic uses `SK6812MINI_and_cherry_1` (south-facing) everywhere** → Phase 2 schematic open
4. **Final USB-C midmount part lock-in (GCT USB4085 vs HRO Type-C-31-M-12)** → Phase 2 based on JLCPCB stock & footprint availability
5. **RP2040-Zero footprint: marbastlib vs custom-built** → Phase 2 after marbastlib audit

## I. Next deliverable

**Phase 1 deliverable #4: `PIN_MAPPING_PROPOSAL.md`**

Scope:
- Lock specific GP10-15 assignment untuk matrix col remap (4 pins of 6)
- Cross-reference zerosprey42 (42-key RP2040-Zero) pin mapping untuk validation
- Document full 17-pin allocation table dengan reasoning per pin
- Note GPIO headroom (3-4 free pins) untuk future-proofing
- Validate PIO peripheral assignment (GP1/GP4 serial, GP0 RGB)

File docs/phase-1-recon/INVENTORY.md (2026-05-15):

# Phase 1 / Deliverable #1 — INVENTORY

> **Source:** `hardware/` — Lefuneste83 fork  
> **HEAD:** `2dbde45` (2024-09-10)  
> **Method:** read-only audit. No modifications to fork files.  
> **Date generated:** 2026-05-13

---

## A. File tree overview

```
hardware/
├── README.md                    (11.2 KB)  — Fork overview; Rev 1.4 = main build target
├── CHANGELOG.md                 (11.0 KB)  — Dates 2024-07 → 2024-09; mentions Rev 1.5
├── FABNOTES.md                  (5.4 KB)   — First-time builder recommendations
├── FIRMWARE.md                  (3.5 KB)   — Firmware variants overview (QMK + ZMK)
├── LICENSE.md                   (35 KB)    — GNU GPL v3 (full text)
├── .github/FUNDING.yml
├── PCB/                         ← 3 KiCad project variants
│   ├── klor1_3/                 — Rev 1.3 (original-derived, WS2812 3535)
│   ├── klor1_4/                 — Rev 1.4 ← MAIN TARGET (SK6812MINI-E south)
│   ├── klor1_4_LP_KS33/         — Rev 1.4 LP (Gateron KS33 low-profile, beta)
│   ├── Alternate DIY Haptic Module/
│   └── README.md                — Manufacturing notes (JLCPCB params)
├── FIRMWARE/
│   ├── qmk_rp2040/electronlab/klor/  — Main QMK source
│   ├── zmk/config/boards/shields/klor/ — ZMK shield (Nice Nano wireless)
│   └── Ready-to-flash/          — 8 pre-built UF2 binaries
├── case/
│   ├── 3DP/{konrad, polydactyl, saegewerk, yubitsume}/
│   ├── acrylic/{konrad, polydactyl, saegewerk, yubitsume}/
│   └── Alternate Case Design/   — Community v2/v2.1 gasket designs
├── docs/
│   ├── buildguide_{3DP, 3DP_ble, acrylic, acrylic_ble}.md
│   ├── images/                  — ~50 images including KLOR_1.5_picture1-5
│   └── klor_rev1-3_ibom.html    — Interactive BOM (Rev 1.3 only)
└── knob/                        — EC11 knob design
```

**File counts (Glob):**

| Type | Count | Globbed via |
|---|---|---|
| `.kicad_pro` | 3 | `hardware/**/*.kicad_pro` |
| `.kicad_sch` | 3 | `hardware/**/*.kicad_sch` |
| `.kicad_pcb` | 3 | `hardware/**/*.kicad_pcb` |
| `.kicad_sym` | 3 | `hardware/**/*.kicad_sym` |
| `.kicad_mod` (footprints) | 50 | `hardware/**/*.kicad_mod` |
| `.stl` (3DP) | 73 | `hardware/case/**/*.stl` |
| `.step` | 9 | `hardware/case/**/*.step` |
| `.dxf` | 16 | `hardware/case/**/*.dxf` |
| `.svg` | 90 | `hardware/case/**/*.svg` |

---

## B. KiCad files

### B.1 PCB project variants (three)

| Project folder | Variant | Status | Files |
|---|---|---|---|
| `PCB/klor1_3/` | Rev 1.3 | Stable, JLCPCB-passing, WS2812 3535 (older LED) | `klor1_3.kicad_pro/sch/pcb` + `KLORlib.kicad_sym` + `KLOR.pretty/` (16 footprints) |
| `PCB/klor1_4/` | **Rev 1.4 ← MAIN** | Refactored layout, SK6812MINI-E **south-facing** | `klor1_4.kicad_pro/sch/pcb` + `KLORlib.kicad_sym` + `KLOR.pretty/` (17 footprints) |
| `PCB/klor1_4_LP_KS33/` | Rev 1.4 LP | Beta — Gateron KS33 low-profile sockets | `klor1_4_LP_KS33.kicad_pro/sch/pcb` + `KLORlib.kicad_sym` + `KLOR.pretty/` (17 footprints) |

> **Decision input:** target variant untuk mod = **klor1_4** (MX standard hotswap + south-facing LED per fork README:11-12). Verifikasi di Phase 2 setelah migrate KiCad-8 → KiCad-10 di branch terpisah.

Plus folder `PCB/Alternate DIY Haptic Module/` — separate small PCB module project (DIY haptic alternative). Skipped from main mod scope per "haptic dropped" decision.

Source: Glob `hardware/PCB/**/*.kicad_*`.

### B.2 Footprint library `KLOR.pretty/` (klor1_4 — 17 footprints)

| Footprint file | Function | Relevance to our 3 mods |
|---|---|---|
| `ProMicro.kicad_mod` | MCU footprint (Pro Micro / Elite-Pi pinout) | **MOD #1 target** — replace with RP2040-Zero |
| `MJ-4PP-9.kicad_mod` | TRRS jack (MJ-4PP-9 standard) | **MOD #2 target** — replace with USB-C 16-pin midmount |
| `SK6812MINI_and_cherry.kicad_mod` | Combined LED + MX switch footprint | **MOD #3 verify** — README claims fork sudah south-facing |
| `SK6812MINI_and_cherry_1.kicad_mod` | Variant ke-2 dari combined footprint | TBD inspect; orientation difference? |
| `Pimoroni Haptic Buzz DRV2605L Driver.kicad_mod` | Pimoroni haptic module | **DROP per decision** — remove placements in PCB |
| `Buzzer_Mallory_AST1109MLTRQ_reversible.kicad_mod` | PWM speaker | **DROP per decision** |
| `MSK12C02_reversible.kicad_mod` | Slide power switch | KEEP — useful for wired build? FABNOTES says optional |
| `Diode_SOD123.kicad_mod` | 1N4148W matrix diode | KEEP unchanged |
| `RotaryEncoder_Alps_EC11E-Switch_Vertical_H20mm-keebio_modified.kicad_mod` | EC11 encoder | KEEP unchanged |
| `SSD1306_128x64OLED.kicad_mod` | OLED footprint | **VERIFY** — name says 128×64 tapi spec kita 128×32 (lihat Section G #3) |
| `SplitkbTentingPuckWithoutCenterHole.kicad_mod` | SplitKB tenting puck mount | KEEP |
| `JST_PH_reversible.kicad_mod` | Battery connector | KEEP (battery option ada di KLOR) |
| `custombatteryconnector_small.kicad_mod` | Alt battery connector | KEEP |
| `Jumper.kicad_mod` | Solder jumper (triangular) | KEEP |
| `R_1206_DoubleSided.kicad_mod` | Resistor 1206 SMD | KEEP |
| `lvc27_onlyInput.kicad_mod` | 74LVC2G17 buffer | TBD — relevance unclear; mungkin terkait haptic/audio gate (drop if so) |

`klor1_4_LP_KS33` adds: `KS33_Symetrical.kicad_mod` (low-profile Gateron socket — tidak relevan untuk MX hotswap target).

Source: Glob `hardware/PCB/**/*.kicad_mod`.

### B.3 Footprints needed but ABSENT (must add at Phase 2)

| Needed for | Footprint | Source candidate |
|---|---|---|
| MOD #1 | Waveshare RP2040-Zero (NOT clone) | marbastlib has variant; verify di Phase 1 deliverable #3 FOOTPRINT_INVENTORY |
| MOD #2 | USB-C 16-pin midmount (specific part TBD Phase 2) | marbastlib `USB_C_Midmount` family or KiCad community lib |
| MOD #3 verify | SK6812MINI-E reverse-mount (kalau existing tidak sesuai) | Bastardkb marbastlib likely has |

---

## C. Firmware files

### C.1 QMK source (`FIRMWARE/qmk_rp2040/electronlab/klor/`)

| File | Lines (approx) | Purpose |
|---|---|---|
| `keyboard.json` | 394 | **Already verified** — `development_board: elite_pi`, matrix pins GP5-8/20-27, RGB GP0, encoder GP28/29, split_count [21,21], 4 LAYOUT variants |
| `config.h` | TBD (Phase 1 deliverable #2) | Hardware-level settings; **OLED resolution di sini** |
| `halconf.h` | small | ChibiOS HAL config |
| `mcuconf.h` | small | RP2040 MCU clock/peripheral config |
| `klor.c` / `klor.h` | larger | Custom matrix scan, OLED rendering, haptic, audio, animations |
| `rules.mk` | small | Build flags |
| `lib/glcdfont.c` | large | OLED bitmap font |
| `lib/klorimation.h` | medium | OLED animation frames |
| `lib/klounds.h` | medium | Audio note/sound clips (DROP per audio decision) |
| `keymaps/default/` | 3 files | QMK keymap (config.h, keymap.c, rules.mk) |
| `keymaps/vial/` | 5 files | Vial-QMK keymap (+ klor.vil + vial.json) |

**QMK build path:** `qmk compile -kb electronlab/klor -km {default,vial}` (per FIRMWARE.md:21-25)

**Inter-half transport (per CHANGELOG.md & FIRMWARE.md):**
```c
// Full duplex serial (recommended for RP2040 ProMicro):
#define SERIAL_USART_TX_PIN GP4
#define SERIAL_USART_RX_PIN GP1
#define SERIAL_USART_FULL_DUPLEX
#define SERIAL_USART_PIN_SWAP
```
> Reference: CHANGELOG.md:69-73 + FIRMWARE.md:43-47

**Required QMK-root patch (per CHANGELOG.md:46-50):**  
File `./platforms/chibios/boards/QMK_PM2040/configs/mcuconf.h`:
```c
#define RP_PWM_USE_PWM4   TRUE   // was FALSE
```
> Gotcha untuk Phase 6 build setup — bukan edit di keyboard folder.

### C.2 ZMK source (`FIRMWARE/zmk/config/boards/shields/klor/`)

Shield-style ZMK config:
- Board overlays: `nice_nano.overlay`, `nice_nano_v2.overlay`, `nrfmicro_11.overlay`, `nrfmicro_11_flipped.overlay`, `nrfmicro_13.overlay`
- Device tree: `klor.dtsi`, `klor_common.dtsi`, `klor_{left,right}.overlay`, `klor.keymap`
- Side configs: `klor_left.conf`, `klor_right.conf`
- Battery monitoring: `battery_status.c/h` + 12 icon files (`bat_00.c`, `bat_25.c`, etc.)
- Bluetooth icons: 8 files (`bt_out_*.c`, `bt_pro_*.c`)
- Logo: `klor_logo.c`, `usb_out.c`
- Kconfig: `Kconfig.shield`, `Kconfig.defconfig`
- Shield metadata: `klor.zmk.yml`

> **Not relevant untuk build kita** (RP2040 wired, no BLE). Leave as-is di firmware fork nanti, atau strip kalau Anda mau bersihkan repo Phase 6.

### C.3 Pre-built UF2 binaries (`FIRMWARE/Ready-to-flash/`)

| Path | Variant |
|---|---|
| `qmk-RP2040/QMK/klor_default_{left,master_left,right}.uf2` | QMK default keymap |
| `qmk-RP2040/VIAL/klor_vial_{left,master_left,right}.uf2` | Vial-QMK keymap |
| `zmk-NiceNanoV2/klor_{left,right}-nice_nano_v2-zmk.uf2` | ZMK Nice Nano BLE |

> 8 pre-built binaries — akan **stale** setelah Phase 6 firmware rebuild. Pertimbangkan delete pasca-Phase 6 untuk avoid confusion.

---

## D. Case files

### D.1 3DP per layout variant (4 variants × 4 sub-folders)

Per variant (konrad, polydactyl, saegewerk, yubitsume) sub-folders:
- `acrylic/` — DXF + SVG untuk laser-cut acrylic plate (full version + logotype)
- `bluetooth/` — STL untuk BLE-specific case (skip untuk wired build)
- `regular/` — STL untuk wired case (case L, R, puck L, puck R)
- `switchplate/` — DXF + STEP + STL + SVG + ZIP (gerber untuk FR4 plate)

**Polydactyl-specific files (target Anda):**

| File | Size | Purpose |
|---|---|---|
| `case/3DP/polydactyl/regular/KLOR_polydactyl_case_L.stl` | 383 KB | Left half case |
| `case/3DP/polydactyl/regular/KLOR_polydactyl_case_R.stl` | 383 KB | Right half case |
| `case/3DP/polydactyl/regular/KLOR_polydactyl_case_puck_L.stl` | 364 KB | Left with SplitKB puck cutout |
| `case/3DP/polydactyl/regular/KLOR_polydactyl_case_puck_R.stl` | 364 KB | Right with puck cutout |
| `case/3DP/polydactyl/switchplate/KLOR_polydactyl_3DP_switchplate.{stl,step,dxf,svg,zip}` | 5 formats | FR4-cut switchplate |
| `case/3DP/polydactyl/acrylic/KLOR_polydactyl_3DPcase_acrylic.{dxf,svg}` | 4 files (+ logotype variants) | Bottom acrylic plate untuk 3DP case |

### D.2 Acrylic stacked case (polydactyl)

Layer-by-layer SVG untuk laser-cut acrylic stacked case:
- 6 layers: `01_bottom`, `02`, `03`, `04`, `05_top`, `06_ring`
- Plus `01_bottom_puck` variant (untuk SplitKB puck)
- Plus `_typo` (logotype embedded) variant untuk top layer
- Plus `_ble` variants per layer (untuk BLE build — skip)
- Plus `KLOR_polydactyl_acrylic_case_switchplate.{dxf,step,stl,svg,zip}`

Total ~16 SVG + ~1 DXF + ~1 STEP untuk polydactyl acrylic case (regular + BLE combined).

### D.3 Alternate Case Design

`case/Alternate Case Design/` — community contribution:
- `klor-case-designs-v52.step` — 28 MB combined source STEP for all 4 variants (v52)
- `Konrad/` — Base, BaseWithTenting, Lid variants
- `Polydactyl/` — v2/v2.1 Gasket designs (Lid, Base, SwitchPlate)
- `Saegewerk/`, `Yubitsume/` — similar
- `Tenting Legs/files/` — 7 STL variants (26mm, 36mm, 38mm, 40mm, 42mm, ALT31, ALT37)
- Encoder inserts: `EncoderInsert.stl`, `EncoderInsert-flat.stl`, `EncoderInsert-16mm.stl`, `EncoderInsert-flat-16mm.stl`
- Documentation: `LICENSE.txt`, `README.txt`, PDF guide `535004-case-designs...pdf` (245 KB)

> Worth keeping for reference. Not in mod scope; gunakan kalau Anda mau gasket-style enclosure.

---

## E. License & contribution status

### E.1 License: **GNU GPL v3** (confirmed)

`hardware/LICENSE.md:1-2`:
```
                    GNU GENERAL PUBLIC LICENSE
                       Version 3, 29 June 2007
```

**Implications untuk fork kita:**
- ✅ Commercial use diperbolehkan
- ✅ Modifikasi diperbolehkan (sesuai mod scope kita)
- ✅ Distribusi binary diperbolehkan
- ⚠️ **Copyleft (strong):** kalau kita distribute board (PCB + firmware bundled), source code modified harus GPL-3.0 dan publicly available
- ⚠️ Hardware design files: GPL applicability ke schematic/PCB layout debatable, tapi spirit GPL = share-alike
- ✅ Hobbyist personal build (no distribution): no obligation

> Source: `hardware/LICENSE.md` (35 KB = standard GPL-3.0 full text).

### E.2 Git activity stats

| Metric | Value | Source |
|---|---|---|
| Fork HEAD | `2dbde45` | `git rev-parse HEAD` |
| Upstream HEAD | `e2f9c2c` | `git rev-parse HEAD` di `references/KLOR-upstream/` |
| Fork commits ahead of upstream | **152** | `git log --oneline e2f9c2c..HEAD \| wc -l` |
| Files changed vs upstream | **248** | `git diff --name-only e2f9c2c HEAD \| wc -l` |
| Total commits (fork HEAD ancestry) | 469 | `git rev-list --count HEAD` |
| First commit (inherited from upstream) | 2022-06-21 "Initial commit" | `git log --reverse` |
| Last commit on fork | **2024-09-10** | `git log -1` |
| Time stale (as of 2026-05-13) | **~20 bulan** | calculated |

### E.3 Top contributors (fork repo, includes upstream history)

| Commits | Name | Likely identity |
|---|---|---|
| 291 | schwarzgrau | Upstream GEIGEIGEIST maintainer (inherited) |
| 113 | Lefuneste83 | **Fork maintainer** (GitHub username) |
| 31 | Hilarion Lefuneste | Same person, real name attribution |
| 17 | GEIST | Co-maintainer upstream |
| 4 | moritz-john | Community contributor |

> Lefuneste83 + Hilarion = 144 commits (~31% of total). Active fork divergence focused on firmware modernization (per file change pattern below).

### E.4 Files changed in fork (sample, 30 of 248)

Predominantly **firmware**:
- `FIRMWARE/qmk_rp2040/electronlab/klor/` — all source files (config.h, halconf.h, mcuconf.h, klor.c/h, keyboard.json, lib/*)
- `FIRMWARE/qmk_rp2040/electronlab/klor/keymaps/{default,vial}/` — full keymap rewrites
- `FIRMWARE/Ready-to-flash/qmk-RP2040/` + `zmk-NiceNanoV2/` — pre-built binaries
- Top-level docs: CHANGELOG, FABNOTES, FIRMWARE.md, README

Suggests Lefuneste83's contribution focus = **firmware modernization** (QMK RP2040 elite_pi config, Vial support, full-duplex serial, PWM4 workaround), bukan major PCB layout redesign. Detailed PCB-level diff perlu dilakukan di Phase 1 deliverable #5 REFERENCE_ANALYSIS.

---

## F. Documentation files

| File | Notable content |
|---|---|
| `README.md` | Rev 1.4 = main build target. Mentions Rev 1.5 design tapi PCB files tidak ada. References Sofle/Kyria/Yacc46/Elephant42 sebagai inspiration. Listed credits: KarlK90, MangoIV, 0xCB-dev, microfortnight, dreipunkteinsvier. |
| `CHANGELOG.md` | Last entry 2024-09-10. Rev 1.5 announced dengan major improvements (direct USB 5V, full duplex serial, hardware handedness, OLED voltage select), tapi PCB files belum committed. Full-duplex serial snippet di lines 69-73. PWM4 patch di lines 46-50. |
| `FABNOTES.md` | SK6812MINI-E orientation gotcha, Gateron socket asymmetry, Pimoroni haptic 15 EUR each, **Mill-Max 0.5mm gold wire** rekomendasi untuk socketed MCU mount, power switch optional untuk wired build. |
| `FIRMWARE.md` | Build commands per environment. **Note correction:** keyboard path adalah `electronlab/klor` (bukan `klor`) per FIRMWARE.md:21,25 (newer convention). |
| `PCB/README.md` | JLCPCB manufacturing params: 159.8 mm × 118 mm, 1.6mm thickness, 2 layers, **HASL or LeadFree HASL** finish, **Remove Order Number: Yes**. References gerber ZIP — but path points to Rev 1.3 only. |
| `docs/buildguide_*.md` | 4 guides: 3DP + 3DP_ble + acrylic + acrylic_ble (only `3DP_ble.md` is tiny stub 0.1 KB) — relevant Phase 5 assembly. |
| `docs/klor_rev1-3_ibom.html` | Interactive BOM Rev 1.3 only. **Rev 1.4 ibom belum di-generate** — bisa kita generate di Phase 4 untuk our custom rev. |

---

## G. Findings to flag for Phase 2

Hal-hal non-obvious yang akan affect Phase 2+ decisions:

1. **Rev 1.5 announced tapi PCB files absent.** CHANGELOG 2024-09-10 menunjukkan major design improvements (direct USB 5V distribution antar halves, full-duplex serial, hardware handedness detection, OLED voltage select 3.3V/5V). Tapi `PCB/` hanya berisi 1_3, 1_4, 1_4_LP_KS33. Confirm: kita fork dari **1.4** sebagai base. Worth investigating apakah 1.5 ada di branch lain (Phase 1 deliverable #5 REFERENCE_ANALYSIS).

2. **klor1_4 README claims south-facing LED.** `hardware/README.md:37` ("As Hipyo Tech can confirm, we are in 2024 so no North facing LED are allowed anymore. I have moved to South facing LED."). **MOD #3 mungkin sudah largely done** di fork. Verify di Phase 1 deliverable #3 FOOTPRINT_INVENTORY (open `SK6812MINI_and_cherry.kicad_mod` dan inspect pad orientation).

3. **OLED footprint nama `SSD1306_128x64OLED` vs spec 128×32.** Need to inspect footprint file di Phase 1 deliverable #2 MATRIX_VALIDATION untuk verify apakah ini universal SSD1306 pad layout (same untuk 128×32 dan 128×64) atau spesifik 128×64. Also cek `config.h` untuk `OLED_DISPLAY_HEIGHT` setting.

4. **Full-duplex serial config sudah documented** di CHANGELOG.md:69-73 — `TX=GP4, RX=GP1, FULL_DUPLEX, PIN_SWAP`. Ini base untuk PIN_MAPPING_PROPOSAL (Phase 1 deliverable #4). Konsisten dengan Justin Lam blog yang mention GP1 untuk PIO serial.

5. **PWM4 patch needed di QMK root** (CHANGELOG.md:46-50): file `./platforms/chibios/boards/QMK_PM2040/configs/mcuconf.h` set `RP_PWM_USE_PWM4 TRUE`. Gotcha untuk Phase 6 build — diff terhadap upstream QMK tree, bukan keyboard folder.

6. **Footprint `lvc27_onlyInput` (74LVC2G17 buffer).** Function unclear tanpa baca schematic. Mungkin terkait haptic atau audio signal gating — kalau iya, bisa removed dari layout per drop decision. Verify di Phase 2 schematic mod.

7. **Mill-Max 0.5mm gold wire** disebut FABNOTES sebagai best practice untuk socketed MCU. Bukan COTS part — flag for Phase 5 sourcing (Aliexpress / Mouser).

8. **GPL-3.0 license.** Different dari hipotesis awal CC-BY-NC-SA. Allow commercial + modifikasi tapi copyleft. Hobbyist build = no constraint. Distribution = full source must be available with same license.

9. **Fork ~20 bulan stale.** Lefuneste83 last commit 2024-09-10. Tidak ada upstream maintenance — bug discovered = self-fix. Tidak ada PR community yang merged di antara 2024-09 dan hari ini (verify Phase 1 #5).

10. **`development_board: elite_pi`** di `keyboard.json` mengindikasikan firmware sudah fully RP2040-aware. Setiap pin label sudah `GPxx`. **Implikasi:** kalau PCB kita routing RP2040-Zero ke pin label yang SAMA dengan elite_pi target, firmware delta = minimal (perhaps zero outside dropping haptic/audio).

---

## H. Cross-references

- [PROJECT_SPEC.md](../../PROJECT_SPEC.md) — Locked hardware spec (3 mods scope)
- [PHASE_LOG.md](../../PHASE_LOG.md) — Decision log
- [CONTRIBUTING.md](../../CONTRIBUTING.md) — Project guidance untuk Claude sessions
- [README.md](../../README.md) — Project overview
- [keyboard.json](../../hardware/FIRMWARE/qmk_rp2040/electronlab/klor/keyboard.json) — Pin mapping ground truth
- [hardware/CHANGELOG.md](../../hardware/CHANGELOG.md) — Fork change history
- [hardware/README.md](../../hardware/README.md) — Fork overview

---

## I. Next deliverable (proposed)

**Phase 1 deliverable #2: `MATRIX_VALIDATION.md`**

Scope (per kickoff spec):
- Konfirmasi matrix dimensions polydactyl variant (expected 4 row × 6 col, 21 keys per half)
- Extract `MATRIX_ROW_PINS` dan `MATRIX_COL_PINS` dari `config.h` (cross-reference `keyboard.json` matrix_pins)
- Identifikasi pin Pro Micro original (D0-D10 mapping) — note: fork sudah RP2040, jadi this maps to elite_pi GPxx labels
- Map polydactyl layout (21 keys per half) ke posisi matrix coordinates

Estimated read targets: `config.h`, `keymaps/default/keymap.c`, `klor.h`, `keyboard.json` (full re-read). Output: ~150 lines markdown di `docs/phase-1-recon/MATRIX_VALIDATION.md`.

**Confirm "lanjut" atau ada catatan untuk INVENTORY.md dulu?**

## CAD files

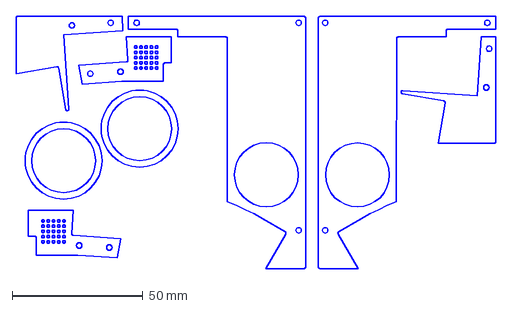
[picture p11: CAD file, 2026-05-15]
hardware/case/3DP/konrad/acrylic/KLOR_konrad_3DPcase_acrylic.dxf
183.7 x 96.8 mm

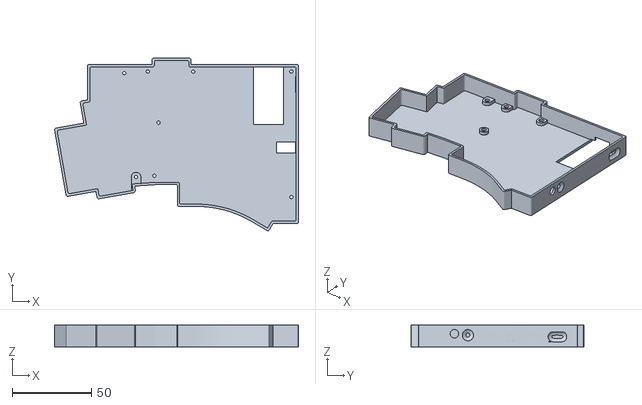
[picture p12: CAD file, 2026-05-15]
hardware/case/3DP/konrad/bluetooth/KLOR_konrad_case_ble_L.stl
154.3 x 109.2 x 13.6

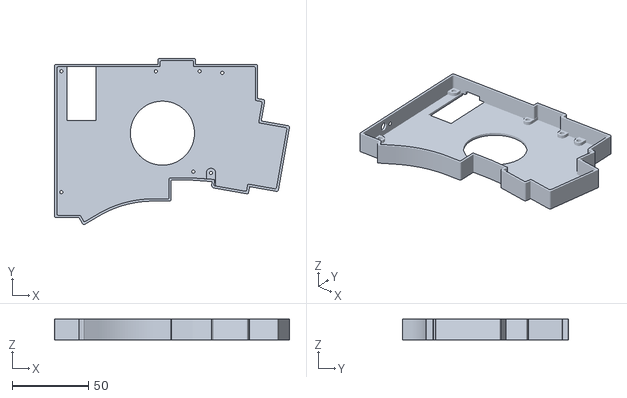
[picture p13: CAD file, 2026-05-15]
hardware/case/3DP/konrad/regular/KLOR_konrad_case_puck_R.stl
154.3 x 109.2 x 13.6

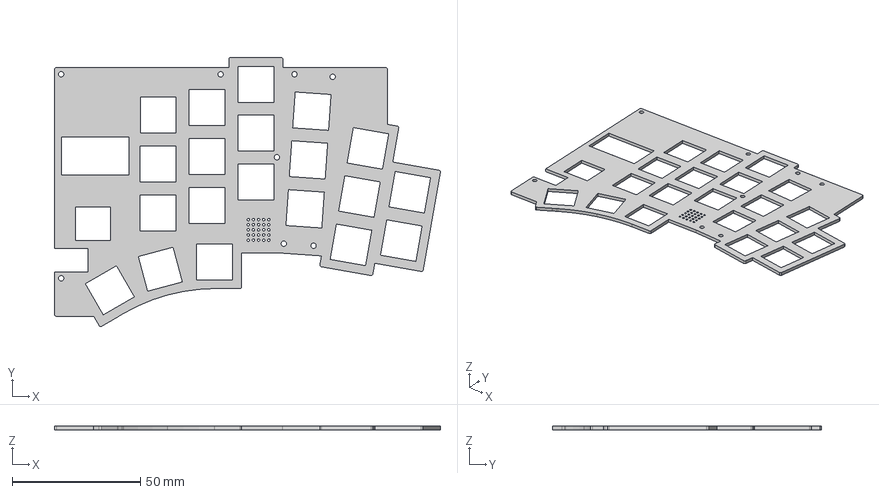
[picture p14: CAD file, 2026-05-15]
hardware/case/3DP/konrad/switchplate/KLOR_konrad_3DP_switchplate.step
150.3 x 104.8 x 1.50 mm

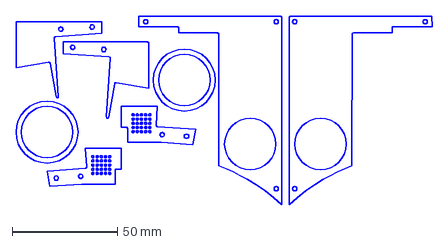
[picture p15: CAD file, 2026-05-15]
hardware/case/3DP/polydactyl/acrylic/KLOR_polydactyl_3DPcase_acrylic.dxf
197.8 x 89.7 mm

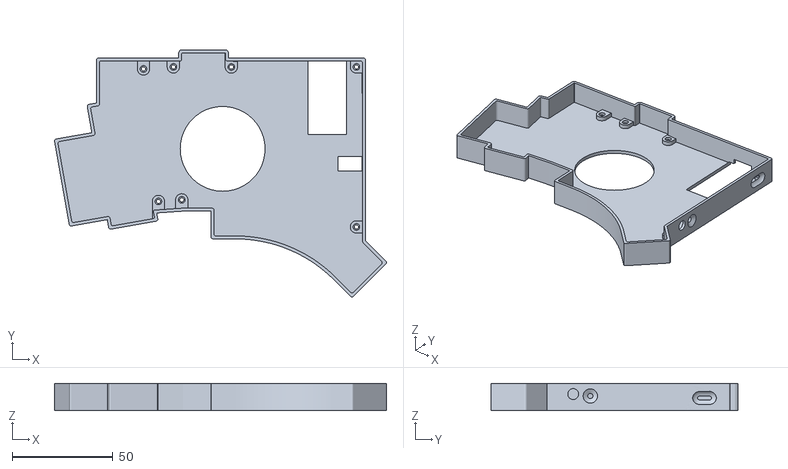
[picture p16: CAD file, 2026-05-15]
hardware/case/3DP/polydactyl/bluetooth/KLOR_polydactyl_case_ble_puck_L.stl
164.7 x 122.7 x 13.6

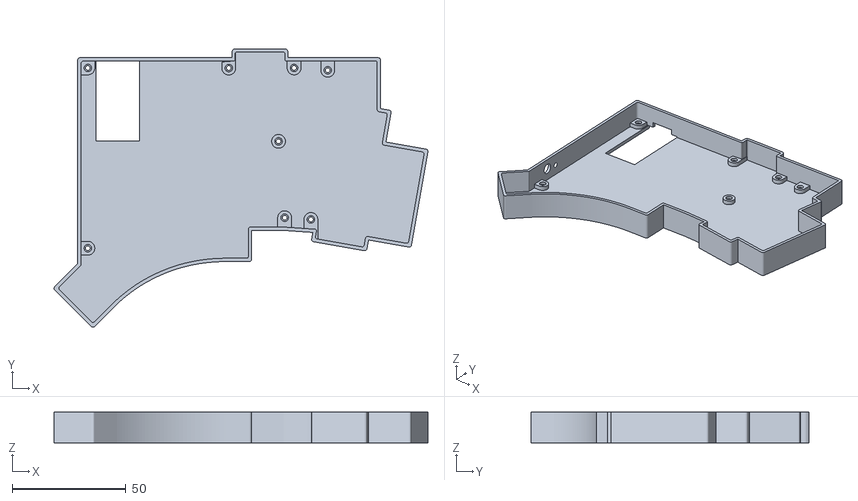
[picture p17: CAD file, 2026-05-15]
hardware/case/3DP/polydactyl/regular/KLOR_polydactyl_case_R.stl
164.7 x 122.7 x 13.6

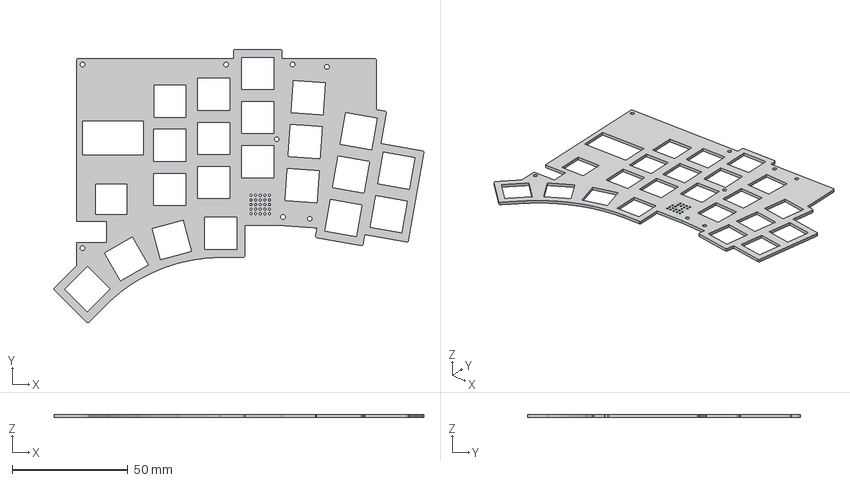
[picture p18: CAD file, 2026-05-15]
hardware/case/3DP/polydactyl/switchplate/KLOR_polydactyl_3DP_switchplate.step
160.0 x 118.2 x 1.50 mm

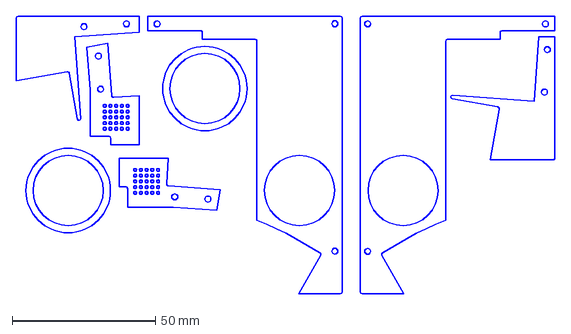
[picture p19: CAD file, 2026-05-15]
hardware/case/3DP/saegewerk/acrylic/KLOR_saegewerk_3DPcase_acrylic.dxf
188.1 x 96.8 mm

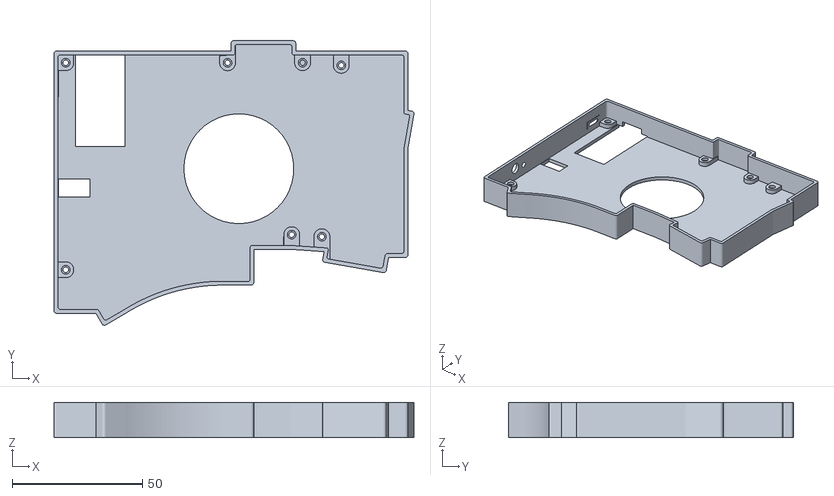
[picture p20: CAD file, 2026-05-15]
hardware/case/3DP/saegewerk/bluetooth/KLOR_saegewerk_case_puck_ble_R.stl
138.1 x 109.2 x 13.6

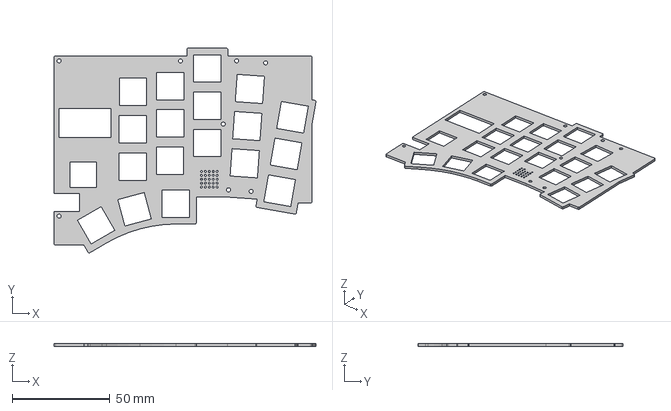
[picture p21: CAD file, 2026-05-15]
hardware/case/3DP/saegewerk/switchplate/KLOR_saegewerk_3DP_switchplate.step
134.0 x 104.8 x 1.50 mm

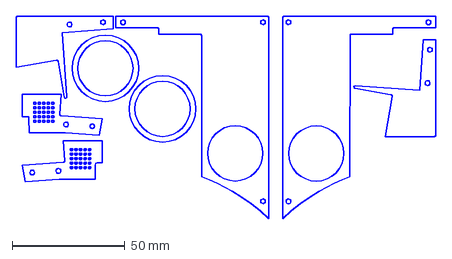
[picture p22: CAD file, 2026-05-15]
hardware/case/3DP/yubitsume/acrylic/KLOR_yubitsume_3DPcase_acrylic.dxf
186.0 x 89.7 mm

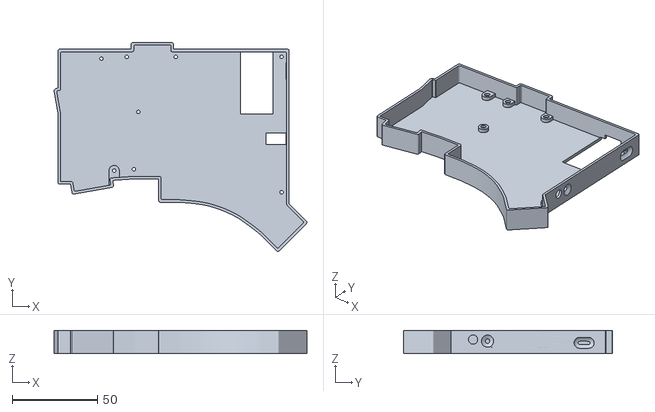
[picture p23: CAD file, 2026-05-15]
hardware/case/3DP/yubitsume/bluetooth/KLOR_yubitsume_case_ble_L.stl
148.4 x 122.7 x 13.6

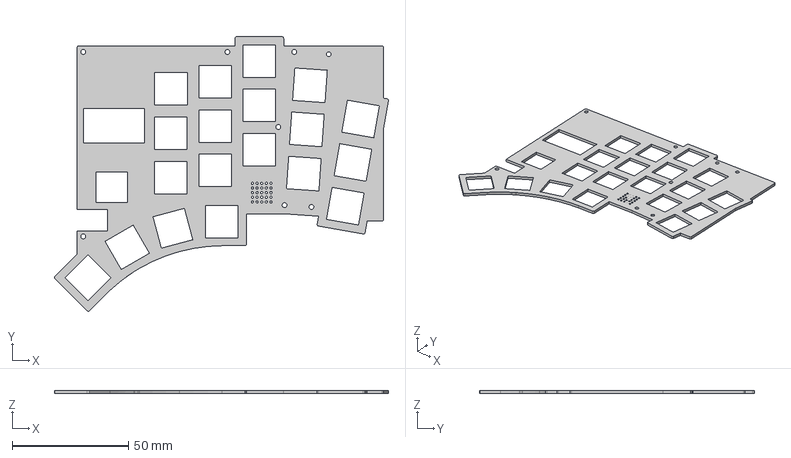
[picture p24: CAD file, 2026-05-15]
hardware/case/3DP/yubitsume/switchplate/KLOR_yubitsume_3DP_switchplate.step
143.8 x 118.2 x 1.50 mm

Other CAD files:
hardware/case/3DP/saegewerk/regular/KLOR_saegewerk_case_puck_L.stl
hardware/case/3DP/yubitsume/regular/KLOR_yubitsume_case_L.stl
hardware/case/acrylic/konrad/switchplate/KLOR_konrad_acrylic_case_switchplate.step
hardware/case/acrylic/polydactyl/switchplate/KLOR_polydactyl_acrylic_case_switchplate.step
hardware/case/3DP/konrad/acrylic/KLOR_konrad_3DPcase_acrylic_logotype.dxf
hardware/case/3DP/konrad/bluetooth/KLOR_konrad_case_ble_R.stl
hardware/case/3DP/konrad/bluetooth/KLOR_konrad_case_ble_puck_L.stl
hardware/case/3DP/konrad/bluetooth/KLOR_konrad_case_ble_puck_R.stl
hardware/case/3DP/konrad/regular/KLOR_konrad_case_L.stl
hardware/case/3DP/konrad/regular/KLOR_konrad_case_R.stl
hardware/case/3DP/konrad/regular/KLOR_konrad_case_puck_L.stl
hardware/case/3DP/konrad/switchplate/KLOR_konrad_3DP_switchplate.dxf
hardware/case/3DP/konrad/switchplate/KLOR_konrad_3DP_switchplate.stl
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

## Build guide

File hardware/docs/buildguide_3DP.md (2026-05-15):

# KLOR BUILD GUIDE (3DP CASE) [WIP]

## PART LIST

### REQUIRED PARTS

| Part name | Count | Remarks | 
| :--- | :---: | :--- |
| KLOR PCB | 02 | You can find the files for it [here](/PCB/) |
| ProMicro | 02 | Alternatively, you can use another controller with a similar pinout like the Elite-C, Puchi-C, KB2040 dda. |
| MX Key switch | 42 | 40 switches for Konrad / 38 switches for Yubitsume / 36 switches for Saegewerk |
| switch socket | 42 | 40 sockets for Konrad / 38 sockets for Yubitsume / 36 sockets for Saegewerk |
| diodes 1N4148W| 44 | These are surface mount diodes in SOD123 package. 42 for Konrad / 40 for Yubitsume / 38 for Saegewerk |
| 1u MX keycaps | 42 | 40 keycaps for Konrad / 38 keycaps for Yubitsume / 36 keycaps for Saegewerk |
| OLED module | 02 | SSD1306 128x64 pixel OLED Displays |
| reset button  | 02 | Alps SKRTLAE010 |
| TRRS jack | 02 | MJ-4PP-9 or PJ320A |
| TRRS cable | 01 | Alternatively, you can use a TRS cable for [half-duplex](https://github.com/qmk/qmk_firmware/blob/master/docs/serial_driver.md#usart-half-duplex)|
| EC11 encoder  | 02 | You can use any EC11 encoder, but it will look better if you use a short one, like the EC11N1524402 |
| encoder knob  | 02 | The design works best with a 2,2cm encoder knob. I'd recommend kilo international knobs with a number starting with 90. You could also use the [knob](/knob/) I designed for the KLOR, based on the kilo knob. 
| USB cable | 01 | For connecting the keyboard to your PC |

### OPTIONAL PARTS

| Part name | Count | Remarks | 
| :--- | :---: | :--- |
| MCU sockets | 04 | For socketing your MCU. Highly recommended |
| MCU pins | 48 | In combination with the MCU sockets |
| SK6812 Mini LED (not Mini-E) 3535 size | 42 | 40 LEDs for Konrad / 38 LEDs for Yubitsume / 36 LEDs for Saegewerk |
| [Haptic Feedback Module](https://shop.pimoroni.com/products/drv2605l-linear-actuator-haptic-breakout) | 01 | Pimoroni Haptic Buzz |
| speaker | 01 | Mallory AST1109MLTRQ or Keliking KLJ-1102 |
| [trackball](https://bit-trade-one.co.jp/selfmadekb/adtb7m/) | 01 | Pixart PAW3204OA. Available at [Yushakobo](https://shop.yushakobo.jp/products/adtb7m) |
| [level converter](https://github.com/sekigon-gonnoc/LevelConverterForTrackballModule) | 01 | Needed to use the trackball. You can get it from [Yushakobo](https://shop.yushakobo.jp/products/a0800tl-01-1/) |
| [tenting puck](https://splitkb.com/products/tenting-puck)| 02 | SplitKB Tenting Puck |

### 3DP CASE PARTS

| Part name | Count | Remarks | 
| :--- | :---: | :--- |
| 3D printed case | 02 | Find the case files [here](/case/3DP) |
| acrylic parts | 02 | Three parts and one ring per side |
| switch plate | 02 | 1.5mm switch plate |
| 7mm M2 standoffs | 16 | round |
| 6mm M2 screws | 16 | |
| 6mm M2 countersunk screws | 16 | The bottom only supports countersunk screws |

## INTRODUCTION

Here is an overview of where and on which side each component needs to be soldered (click on the image to see a larger version).

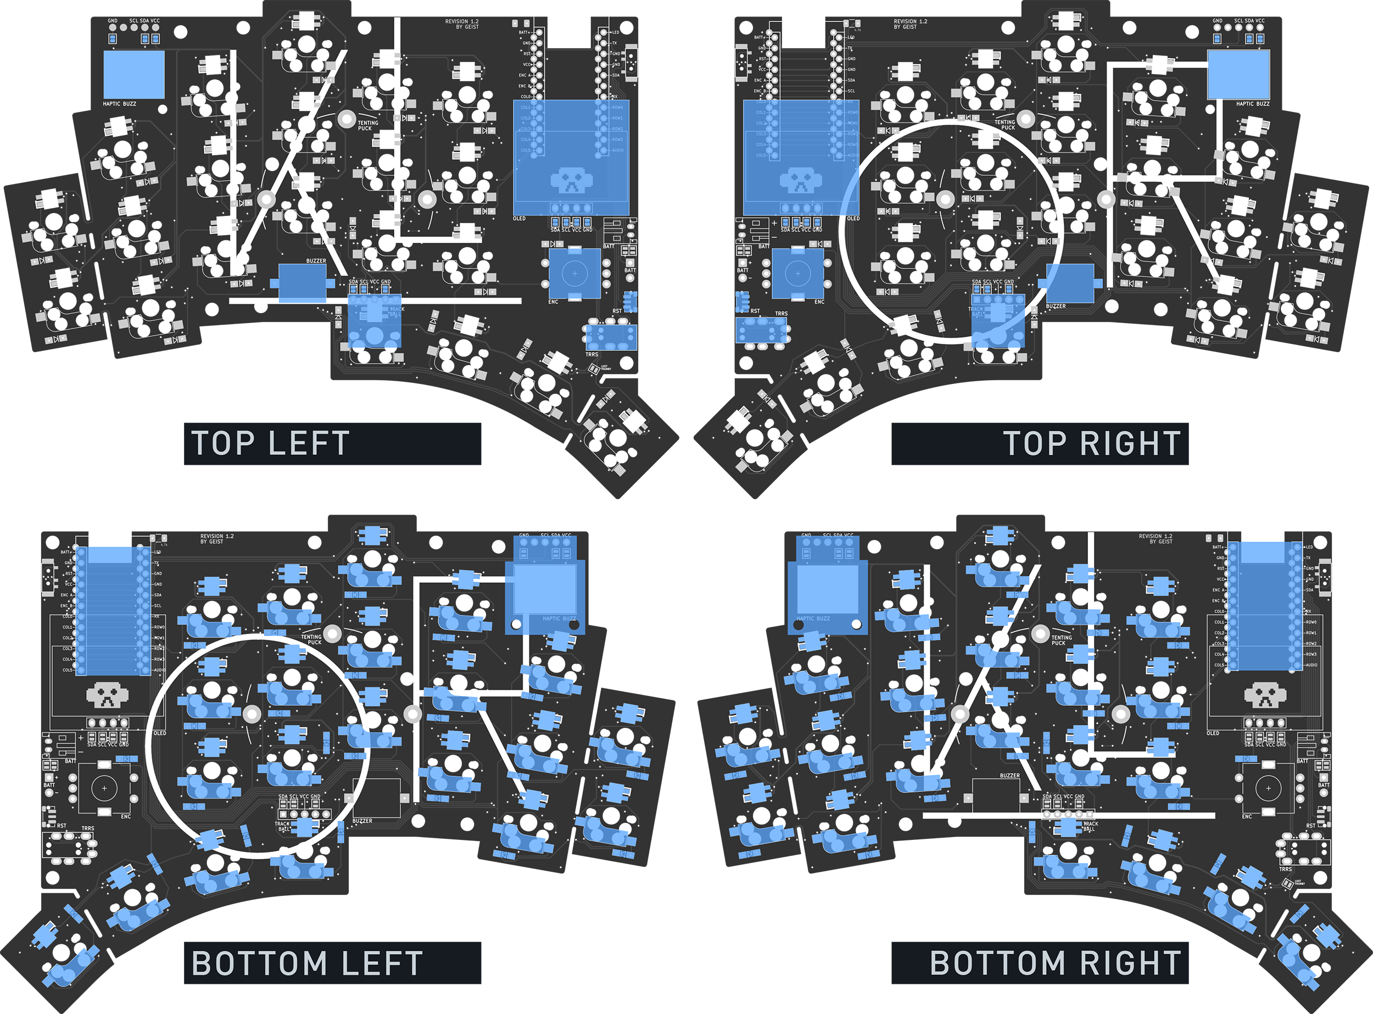
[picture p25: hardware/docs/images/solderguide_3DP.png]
KLOR solder guide


To see what component needs to sit where you can take a look at the [interactive HTML BOM](https://htmlpreview.github.io/?https://github.com/GEIGEIGEIST/KLOR/blob/main/docs/klor_rev1-3_ibom.html).

> **Warning**
> This interactive HTML BOM does show where each component is located, but please still refer to the soldering guide above to see if a component needs to go on the top or bottom of the PCB.

Be aware that for the stacked acrylic case some components need to be soldered on the opposite side.\
Some people mark the top and bottom with tape to keep track of which side is which, as the PCB is reversible.\
Begin with the flat components and progress to the higher ones, ending with the OLEDs and the encoders.

***

## BREAK OFF PARTS (optional)

If you choose a layout [other than](/README.md#layouts) Polydactyl you should remove the unnecessary parts. Use a flush cutter to snip through the support sections. You can also use a boxcutter to carve in grooves, which makes it easier to break on the right spot. 

> **Warning**
> Be very careful with this step, since there is a risk to break the PCB. Probably it would be best to begin with this step, to avoid losing already soldered parts.

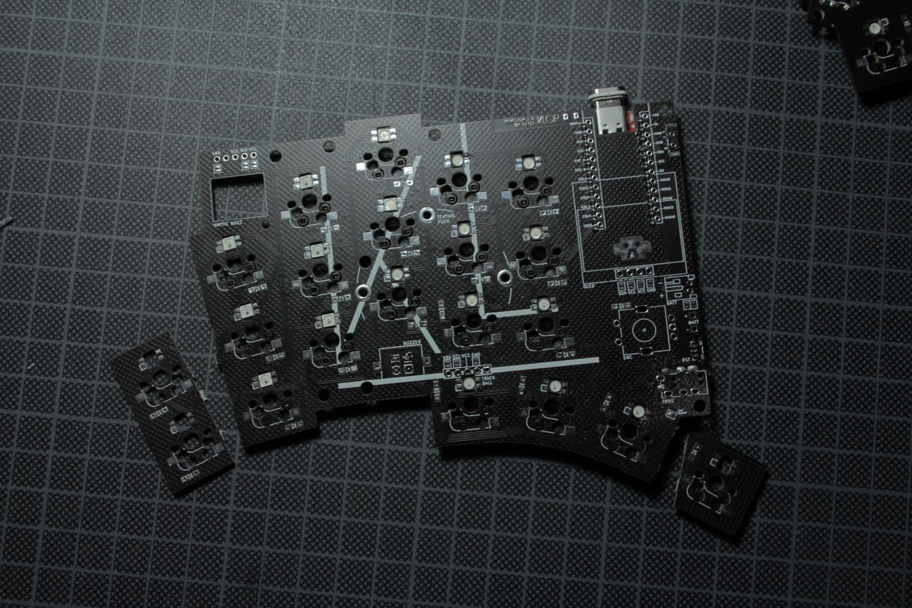
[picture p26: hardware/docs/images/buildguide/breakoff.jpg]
break off parts


You can use a file to smooth out the edges, but you should wear a mask while doing this since the FR4 dust is considered to be toxic.

***

## MICROCONTROLLER

> **Warning**
> First flash the microcontroller to make sure it works, before soldering it in.

Unlike most other boards here the microcontroller needs to be mounted on the bottom, with the components facing upwards (to the PCB).\
Feel free to use the included header pins, but it's highly recommended to use MillMax low-profile sockets.\
Place the sockets in the marked spots on the bottom side of the PCB.

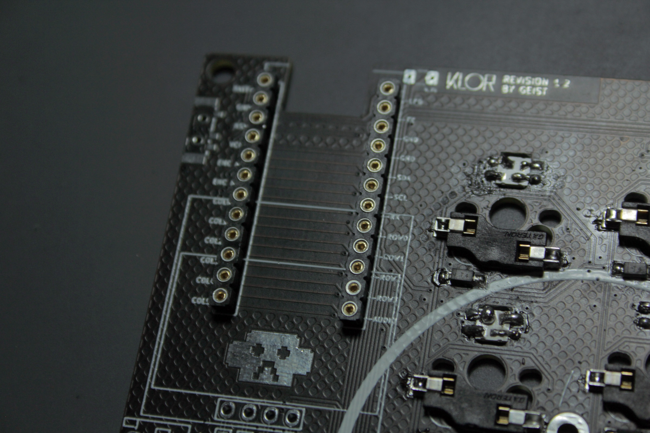
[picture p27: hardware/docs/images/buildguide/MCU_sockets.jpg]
MCU sockets


You can keep them in place by using masking tape.

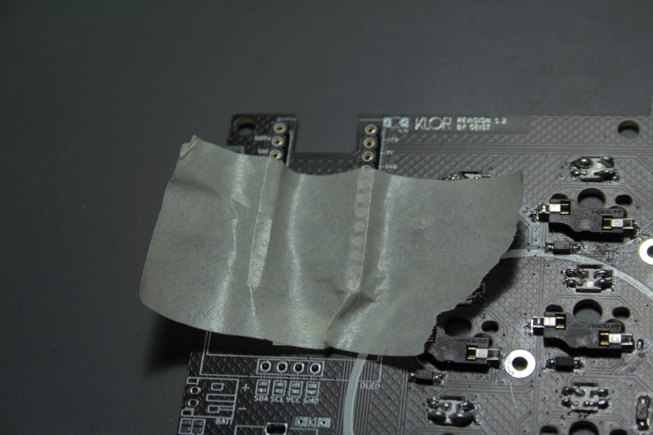
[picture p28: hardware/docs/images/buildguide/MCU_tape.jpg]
sockets taped


Then you can flip the board to solder in the sockets from the top.
Flip it again and insert the pins into the sockets.

> **Note**
> Use tweezers to insert them. Don't apply too much force, you will feel them snap in. After that, you can carefully apply some pressure, using a flat object to make sure they're fully seated. 

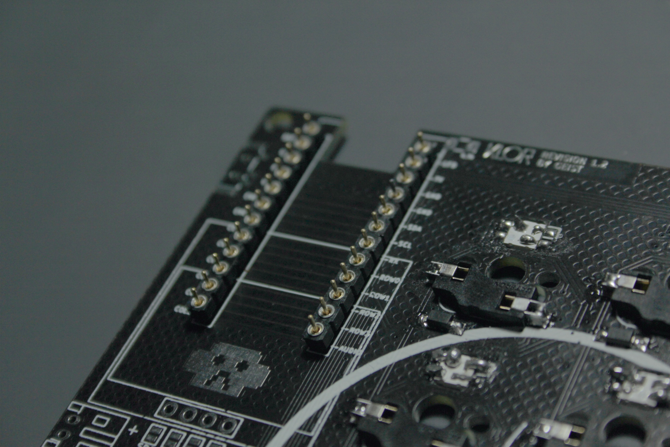
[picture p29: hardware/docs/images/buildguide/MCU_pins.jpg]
MCU pins


Now place your microcontroller on the pins (components facing the PCB) and solder it to them.\
You can use flush cutters to trim the header pins.

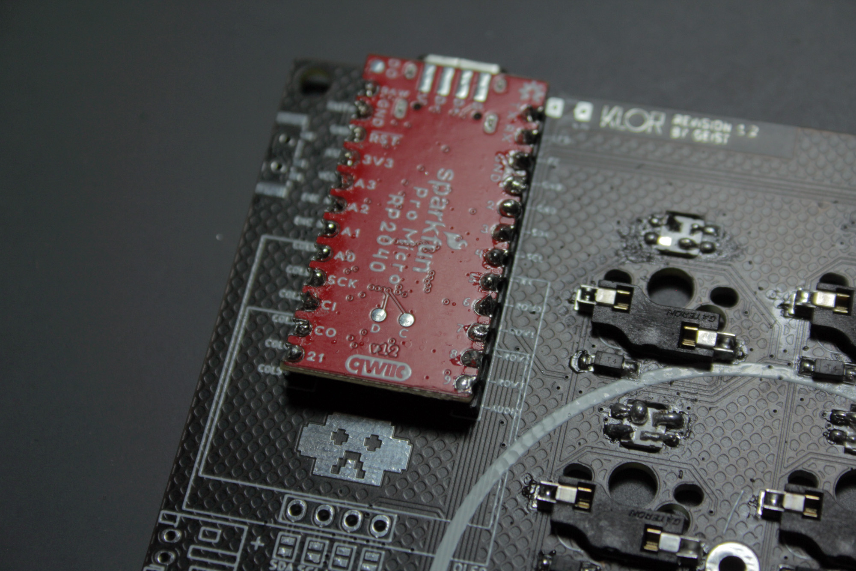
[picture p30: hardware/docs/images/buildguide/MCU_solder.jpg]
MCU solder


> **Warning**
> When trimming with flush cutters wear eye protection or hold your hand close above the pins. Otherwise, sharp metal pins flying around might hurt you.

***

## LEDS (optional)

> **Note**
> If you use a layout with three thumbs, instead of four, you need to bridge the 'lost thumb?' jumper below the TRRS sockets on the primary and secondary PCB, since the led chain lost its beginning. 

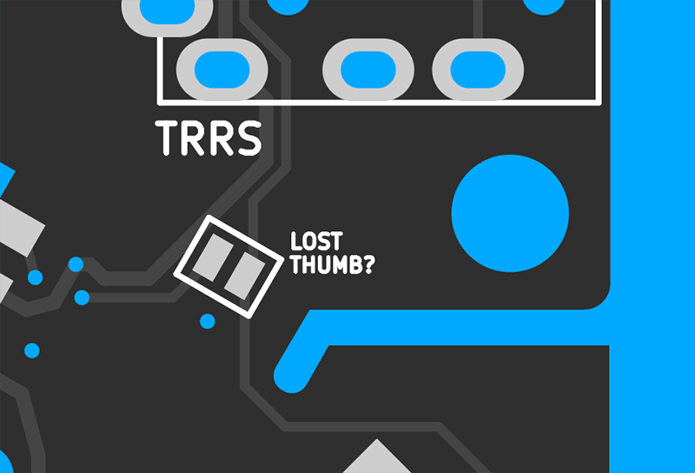
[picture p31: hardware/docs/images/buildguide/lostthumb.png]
Lost thumb jumper


LEDs are very heat sensitive. So it's a good idea to solder the pads on the PCB bottom first and then insert the LED.

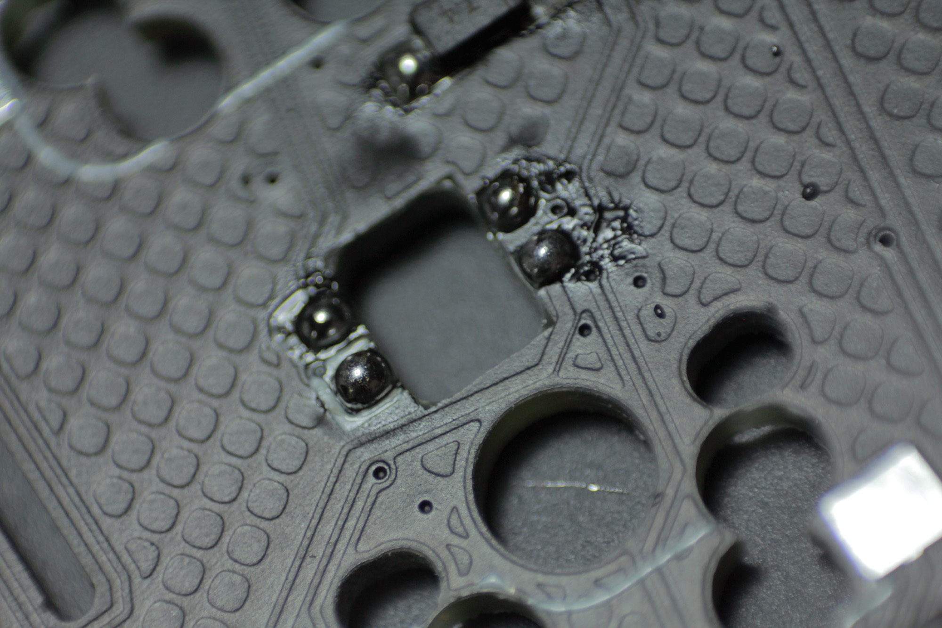
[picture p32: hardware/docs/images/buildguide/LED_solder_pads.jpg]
LED solder pads


While the bottom of the PCB is facing you, insert the LEDs in the holes. The lens should face the table.

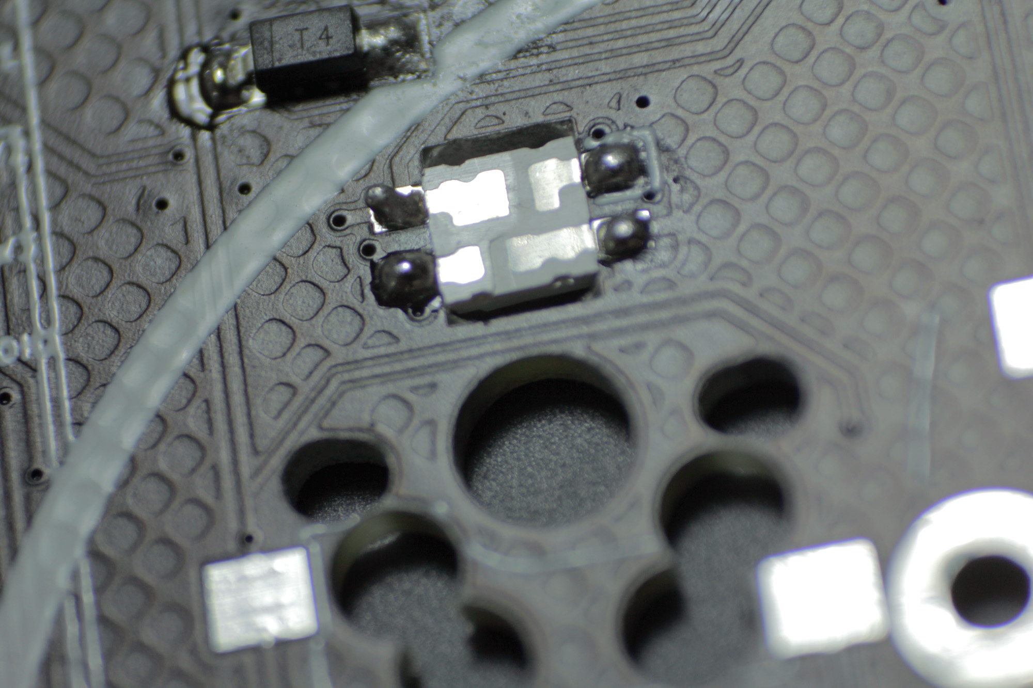
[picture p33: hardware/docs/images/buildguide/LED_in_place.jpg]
LED in place


This image depicts the correct orientation.\
The L-shaped pad on the LED needs to be connected to the square-marked pad.

LED orientation1

> **Note**
> While the orientation is uniform within a half, it differs between left and right.

> **Warning**
> It's recommended to solder the LEDs in at 220º since they're pretty heat sensitive. Personally, I had a hard time keeping it below 270º. So my advice would be while soldering the first pad on every LED, try to be really quick. Then solder the second pad on every LED, starting with the first LED. This way they can cool down in the meantime.

Make sure the solder always builds a strong connection between the pad on the LED and the pad on the PCB. 

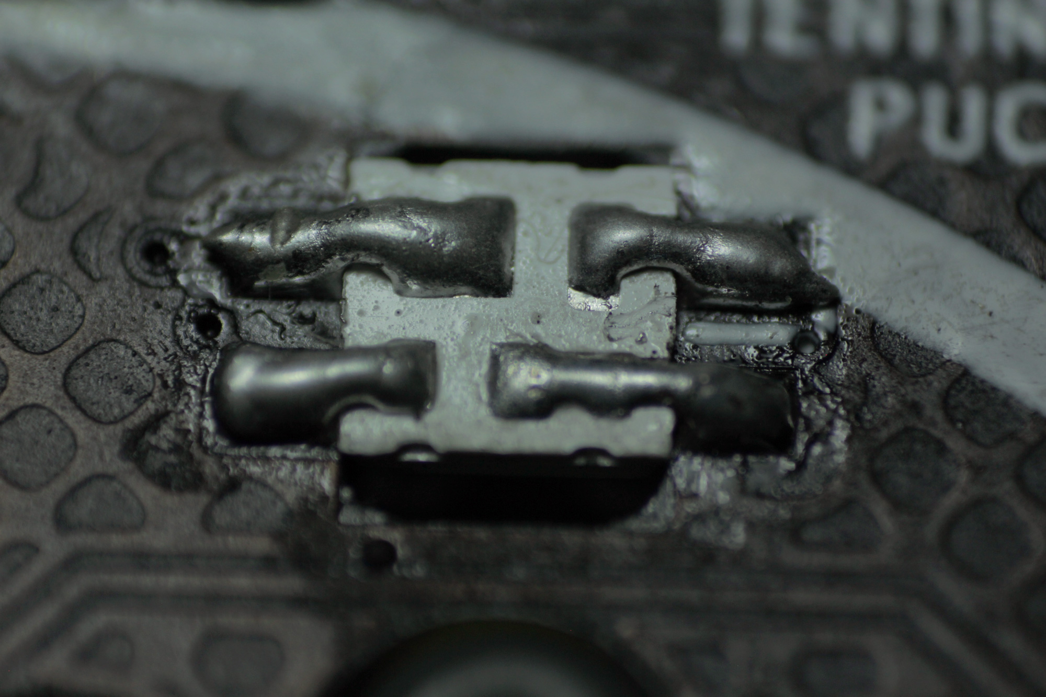
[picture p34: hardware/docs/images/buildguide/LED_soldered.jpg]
LED connection


The advantage of soldering in the microcontroller first is that you can occasionally check if all the LEDs work before continuing. 

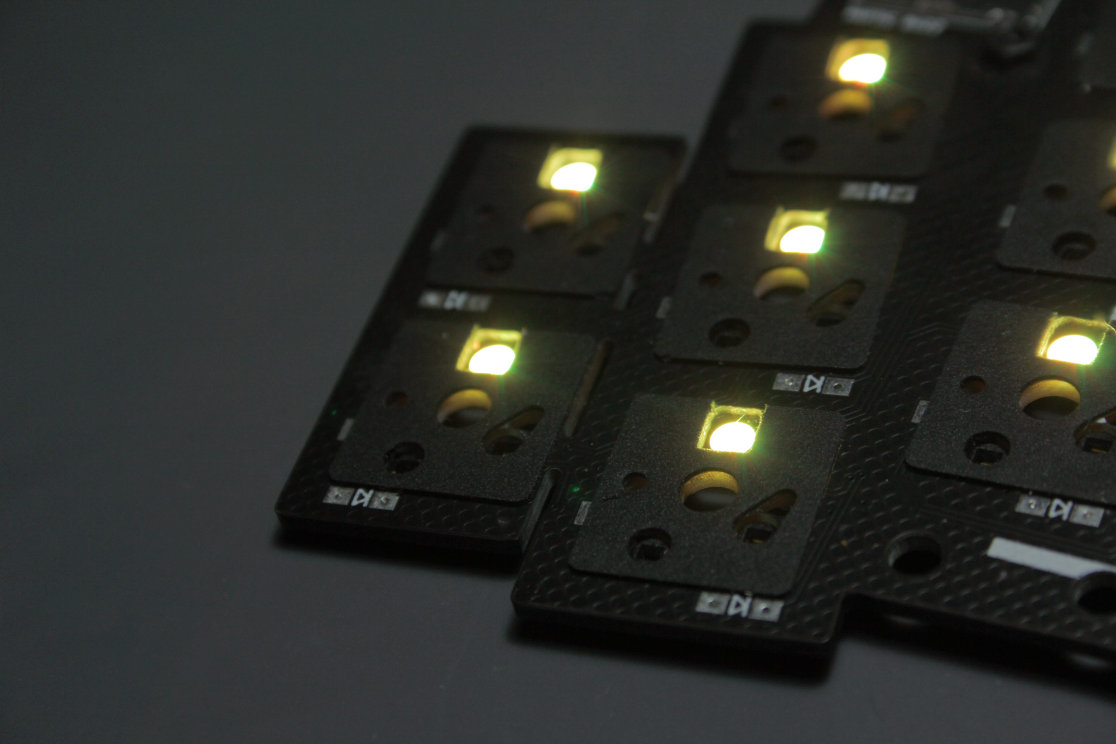
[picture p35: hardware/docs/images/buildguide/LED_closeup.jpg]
KLOR LED working


This graphic shows the order in which the LEDs are chained together.

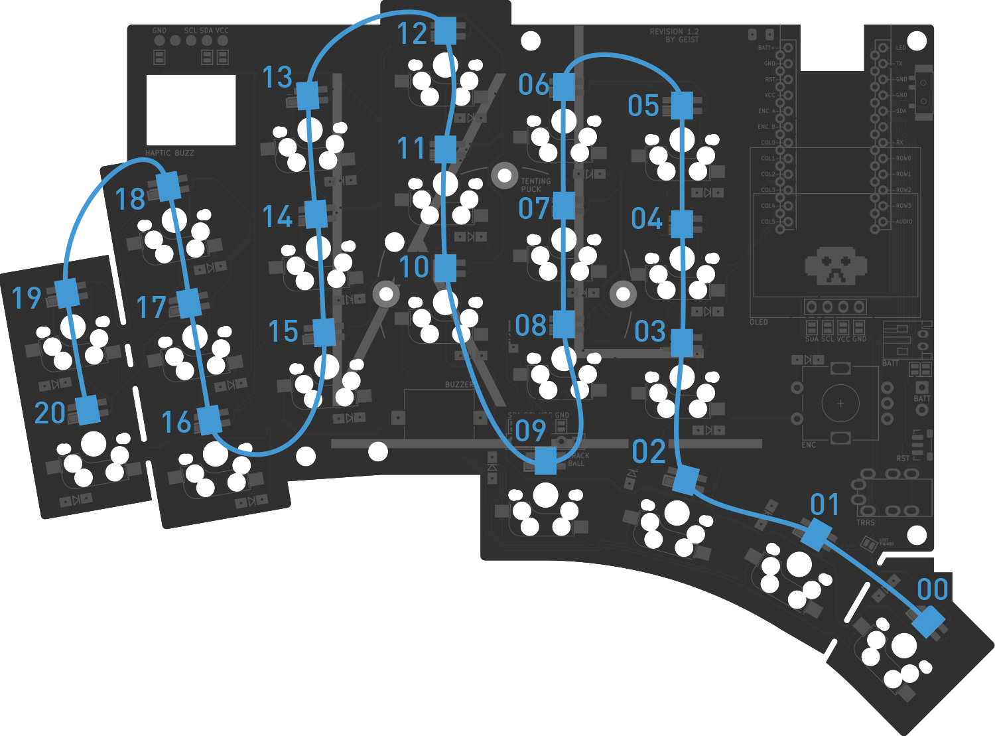
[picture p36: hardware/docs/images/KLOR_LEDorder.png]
KLOR LED order


***

## DIODES

The diodes need to be soldered on the bottom of the PCB. Pay attention to their orientation:  They have a small line on one side, which should be on the side the arrow on the PCB is facing to.

<p align="center">
<picture>
  <source media="(prefers-color-scheme: dark)" srcset="/docs/images/buildguide/diodes_dark.svg">
  <source media="(prefers-color-scheme: light)" srcset="/docs/images/buildguide/diodes_bright.svg">
  diode orientation
</picture>
</p>

Apply a small amount of solder on one pad.

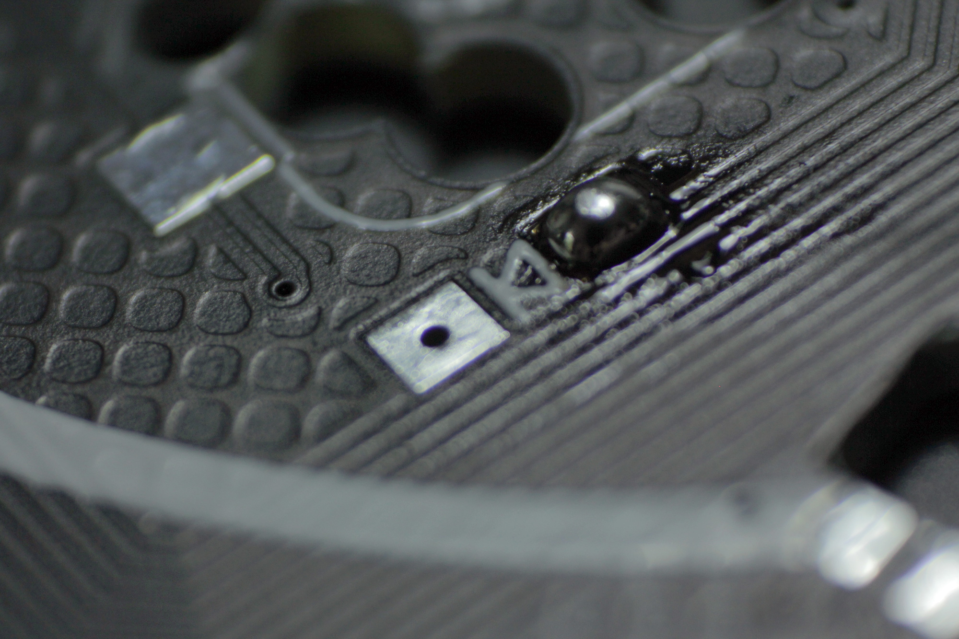
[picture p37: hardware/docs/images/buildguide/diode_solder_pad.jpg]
Solder on one pad


Then use tweezers to place the diode on the pads and reheat the solder to secure the diode.

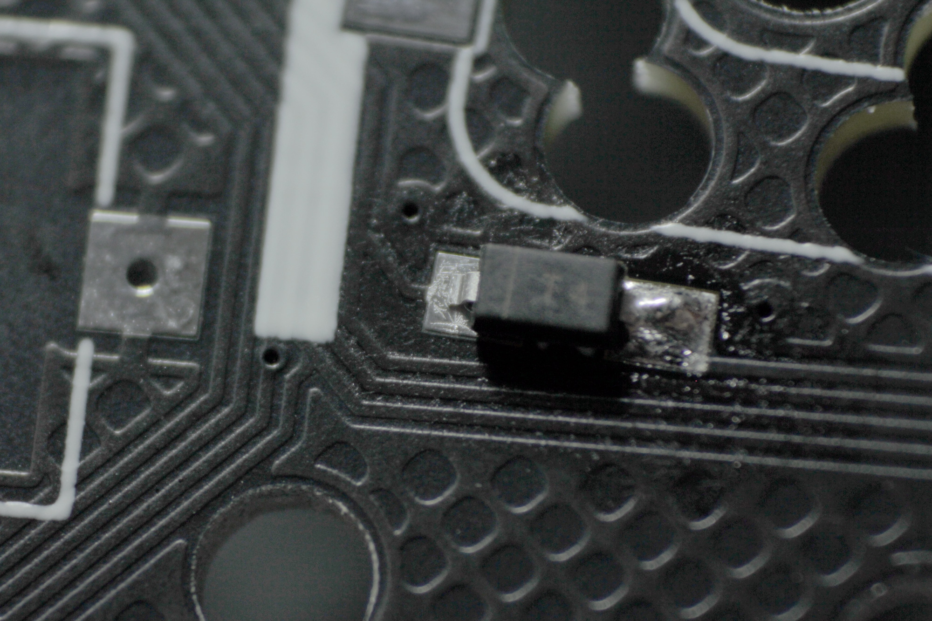
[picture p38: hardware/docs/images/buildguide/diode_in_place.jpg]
Solder diode


Now you can solder the second pad.

***

## SWITCH SOCKETS

Here you can apply the same technique as used for the diodes: Apply some solder on one of the pads first.

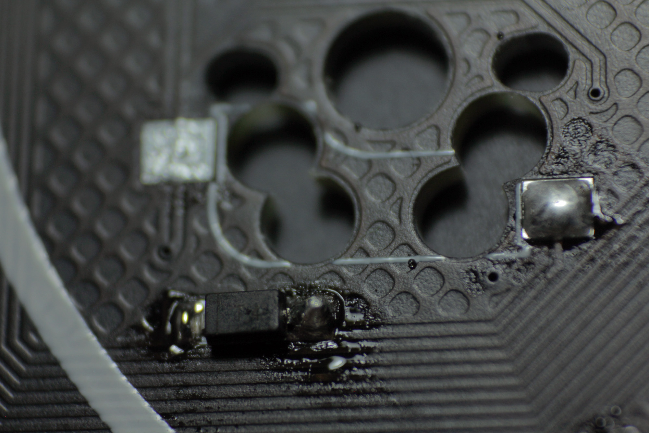
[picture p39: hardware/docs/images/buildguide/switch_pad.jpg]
switch sockets pad


Then place the switch socket in the silk screen markings and reheat the solder. Apply some pressure with a pair of tweezers to make sure the socket is fully seated.\
Now solder the second pad.

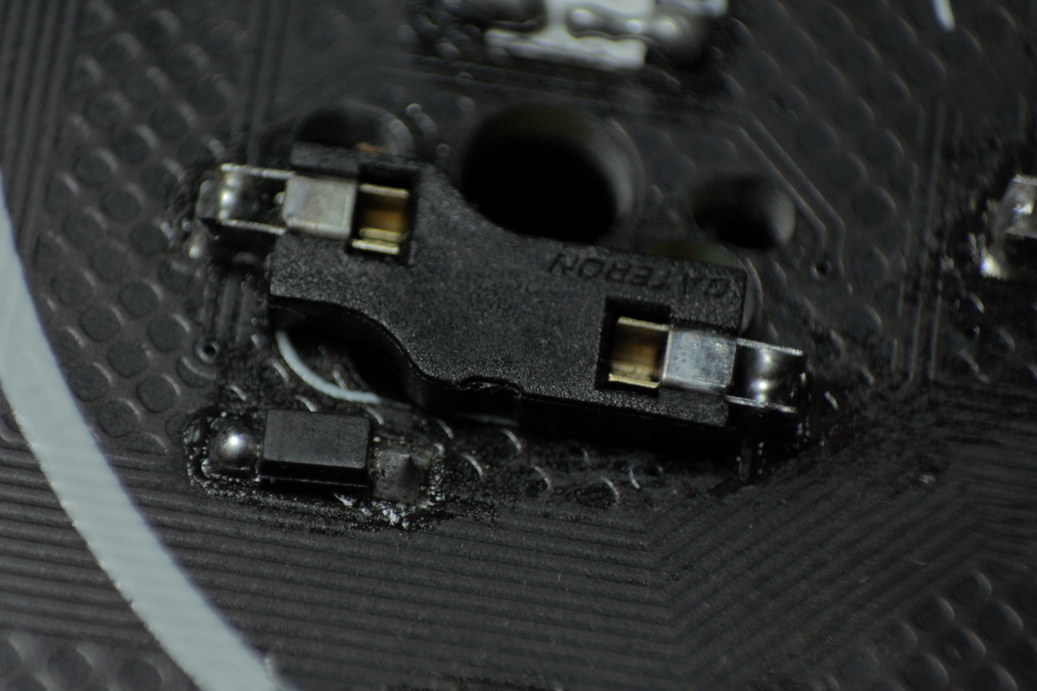
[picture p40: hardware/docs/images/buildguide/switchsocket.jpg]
switch socket soldered


***

## RESET SWITCHES

The reset switches are a bit fiddly to solder. It helps to apply a really thin film of solder to the outer pads first. Then hold the switch in place with tweezers and solder the big pads on the left and right of the switch (they do not fulfill any electrical purpose, but serve to hold the switches in place). If the switch is seated correctly flip the PCB and solder the pads in the middle from below.

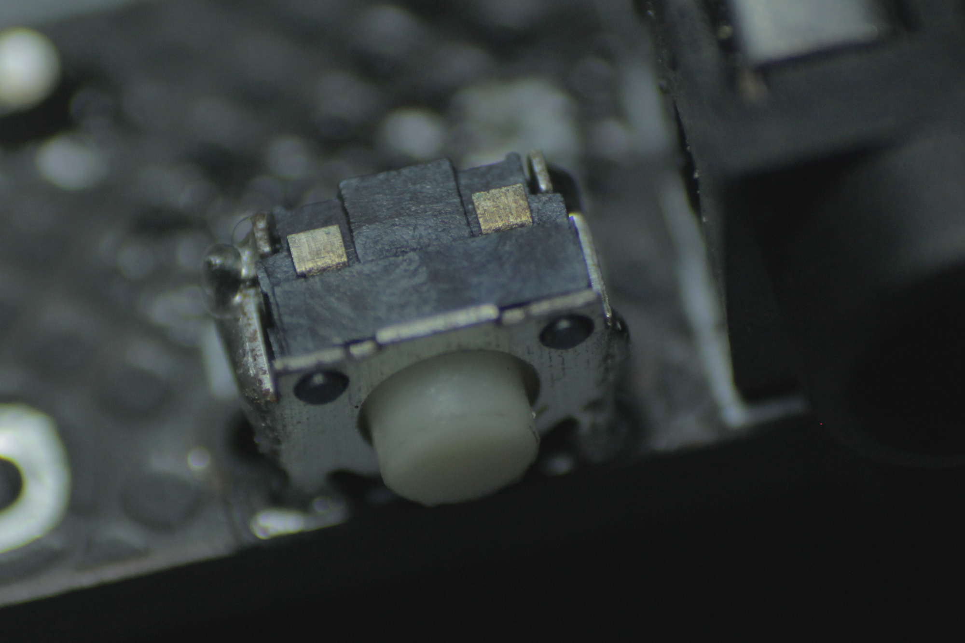
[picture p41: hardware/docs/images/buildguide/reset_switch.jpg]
reset switch


***

## TRRS JACKS

Install the TRRS jack on the top side of the PCB. The place where you should insert it is marked with a white line.
You may want to use some masking tape to hold it in place since you need to solder it on the bottom.

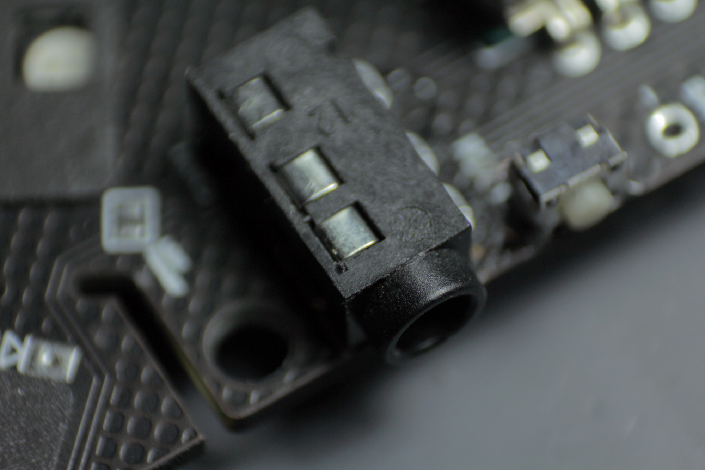
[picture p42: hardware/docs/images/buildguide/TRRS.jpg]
TRRS jack soldered


***

## HAPTIC FEEDBACK (optional)

> **Note**
> Currently, haptic feedback only works on the primary side of your keyboard, which is a limitation of QMK.

Apply some solder to the jumpers on the top to bridge them.

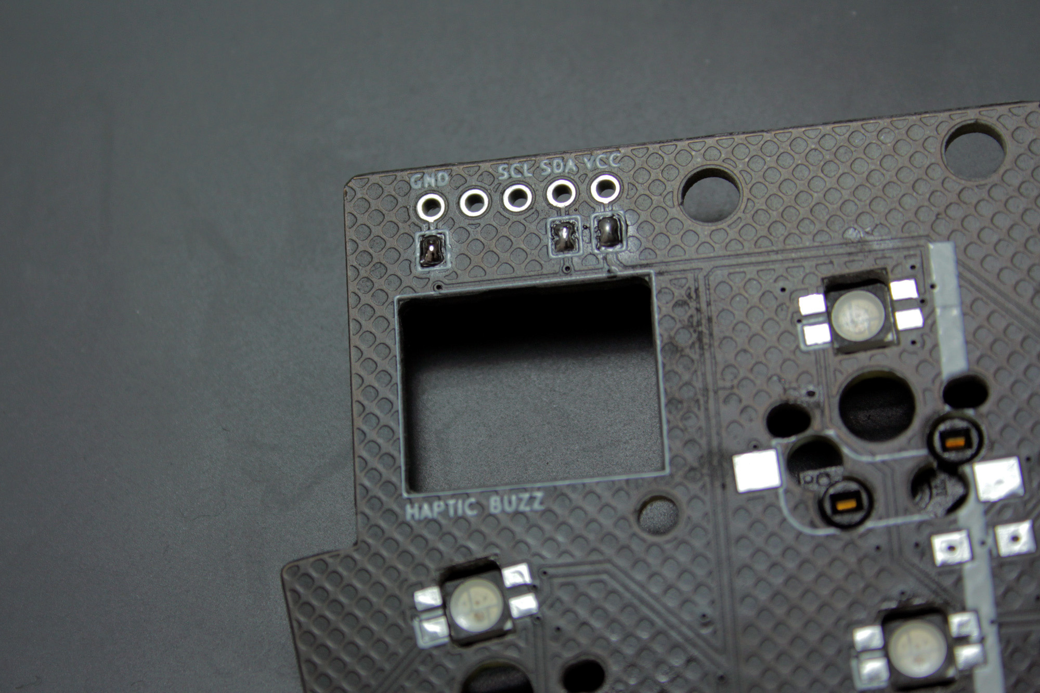
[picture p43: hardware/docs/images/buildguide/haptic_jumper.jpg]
haptic feedback Jumper


Insert the module from below with the motor facing upwards. Then insert the pin headers from below.

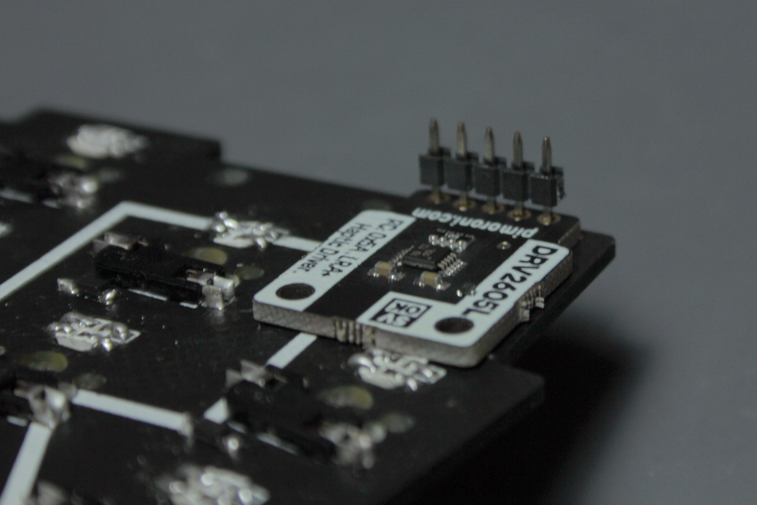
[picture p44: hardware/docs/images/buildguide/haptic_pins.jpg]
haptic feedback pins


Now you can solder the pins and use a flush cutter to snap off the excess. Remember to hold your hand above them or wear eye protection while doing so.

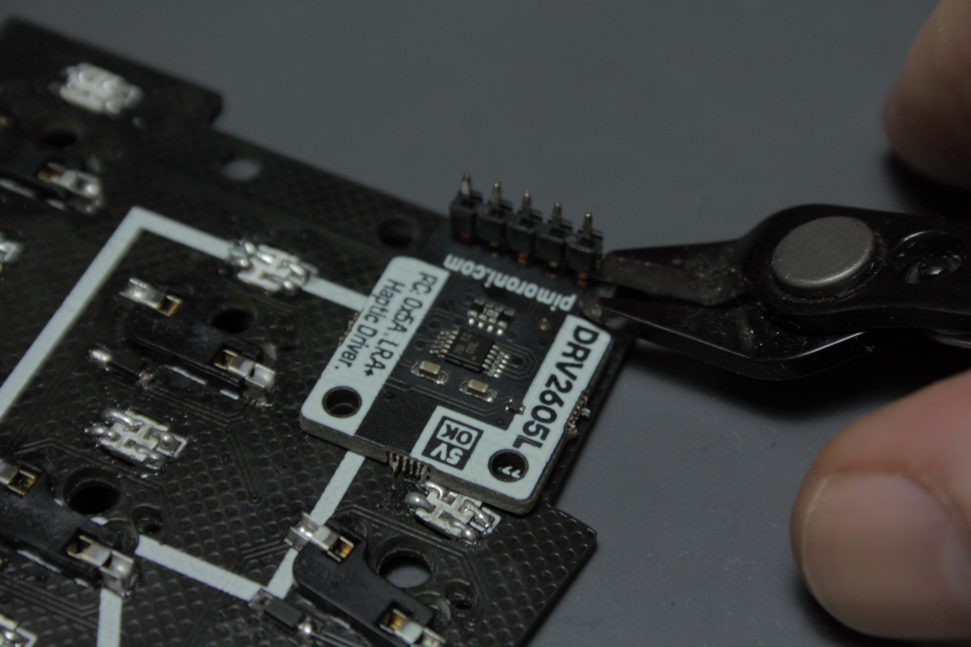
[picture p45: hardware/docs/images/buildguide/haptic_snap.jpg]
haptic feedback snap of pins


You can also use a screw and a nut to stabilize the module further. But this step is optional.

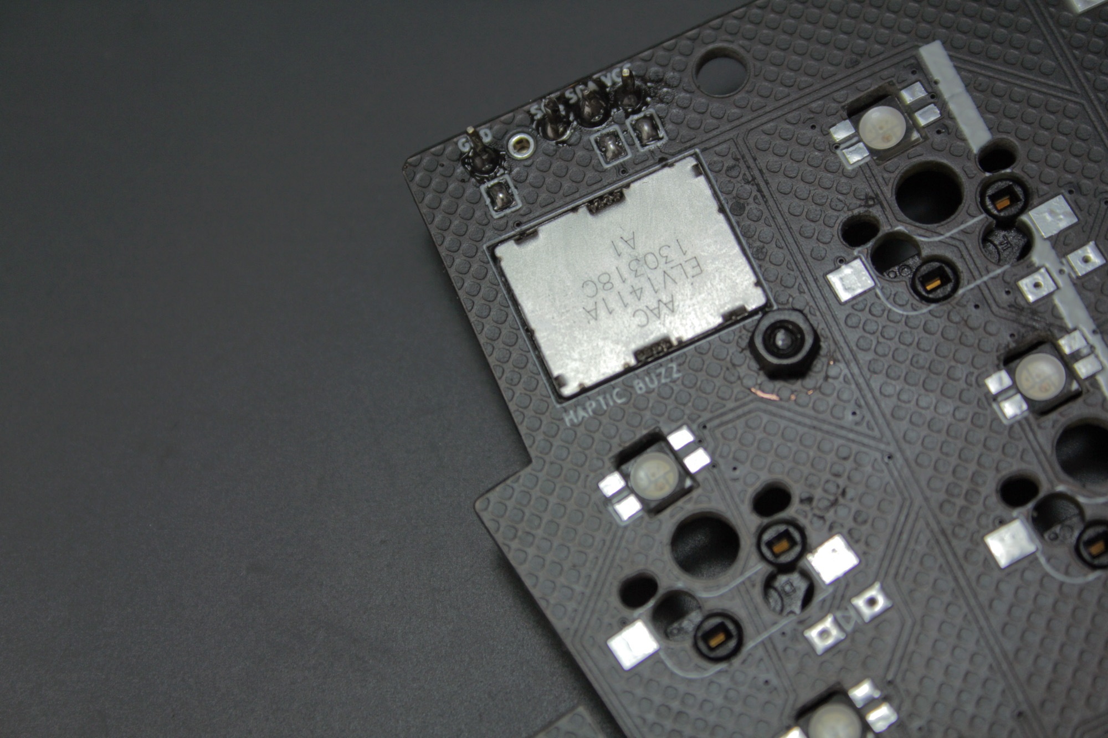
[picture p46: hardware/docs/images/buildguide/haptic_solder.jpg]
haptic feedback solder


***

## SPEAKER (optional)

> **Note**
> Currently the speaker only works on the primary side of your keyboard, which is a limitation of QMK. Currently, you need to use [this PR](https://github.com/qmk/qmk_firmware/pull/17723) to make the audio feature work with the RP2040.

Soldering the speaker is pretty simple. Apply a tiny bit of solder on one of the pads, use tweezers to hold the speaker in place and reheat the solder. After that apply solder to the other pad.

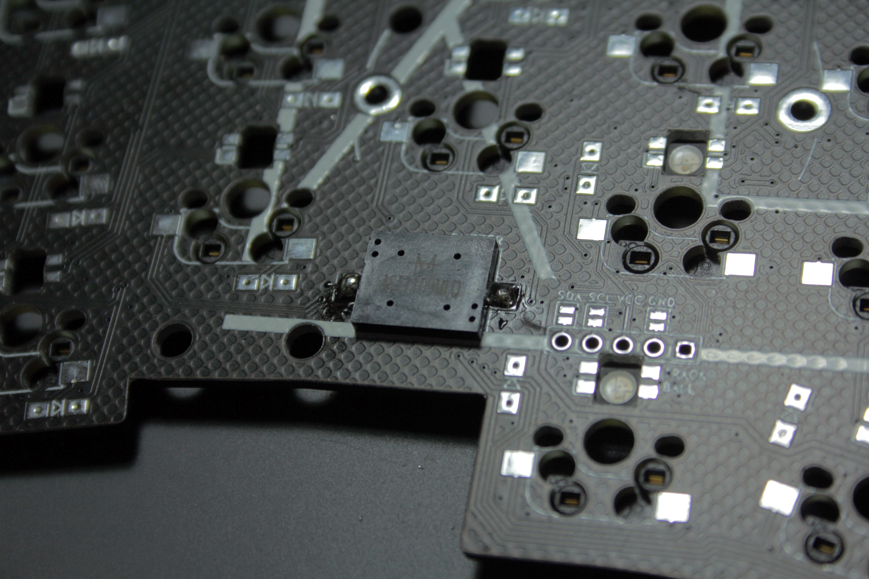
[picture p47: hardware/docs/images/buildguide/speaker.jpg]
speaker


***

## TRACKBALL (optional)
> **Note**
> While the hardware side should already work fine, I still need to add the code for the trackball.

TBA

***

## ENCODERS

Mount the rotary encoder on the top side of the PCB. It should click into place maybe requiring a firm press. If it's seated correctly solder the pins on the bottom.

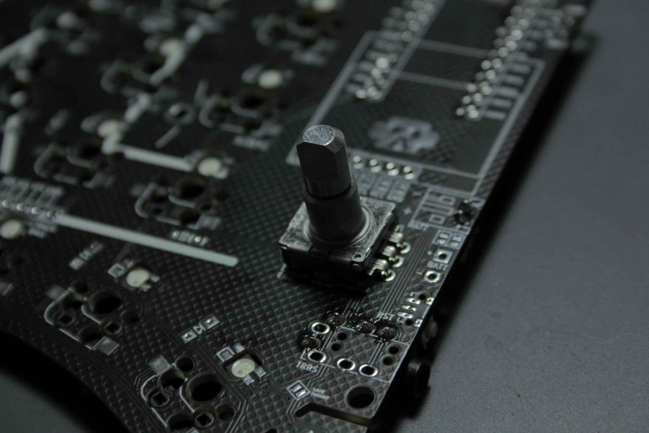
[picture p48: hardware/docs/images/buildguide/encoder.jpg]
encoder


***

## OLEDs

> **Warning**
> Make sure the keyboard is fully functional before soldering the OLEDs, since they're the only components that cover pins, you won't be able to access them once they are in place.

First step should be to bridge the jumpers on the top of the PCB next to the OLED.

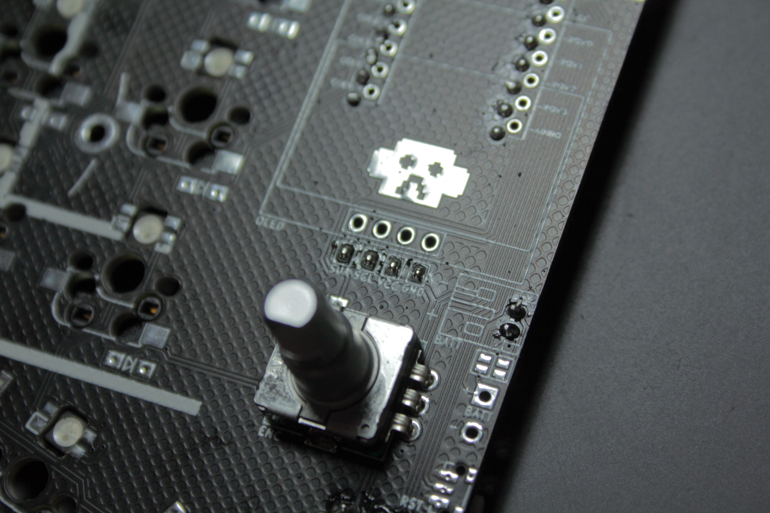
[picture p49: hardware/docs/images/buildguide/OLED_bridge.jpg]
OLED bridge jumpers


> **Note**
> The OLED needs to be as flush to the PCB as possible to fit under the switchplate.

You need to remove the plastic part, which is usually attached to the OLED, from the headers, while keeping the pins. For me, the easiest way is to use flush cutters to snap the plastic in half, which allows you to remove the parts easily. You probably need to bend the pins back in place after doing this.

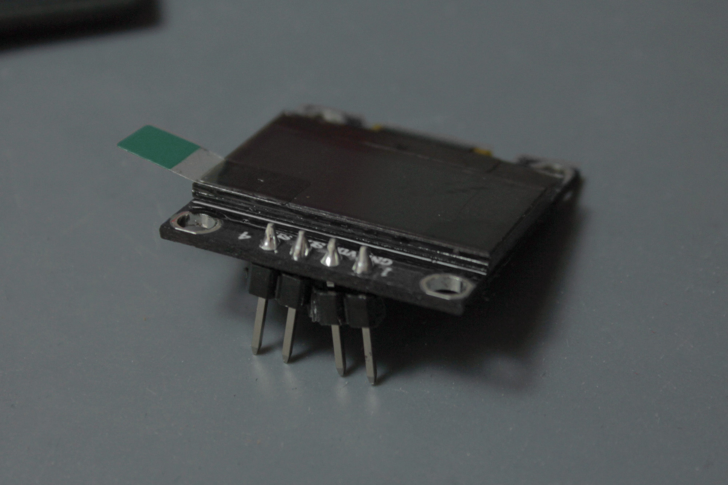
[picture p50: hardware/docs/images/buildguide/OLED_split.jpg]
OLED pin split


You also need to cover the back of the OLED with electrical tape, to prevent shorts with the microcontroller pins. Especially the top part with the copper traces is important.

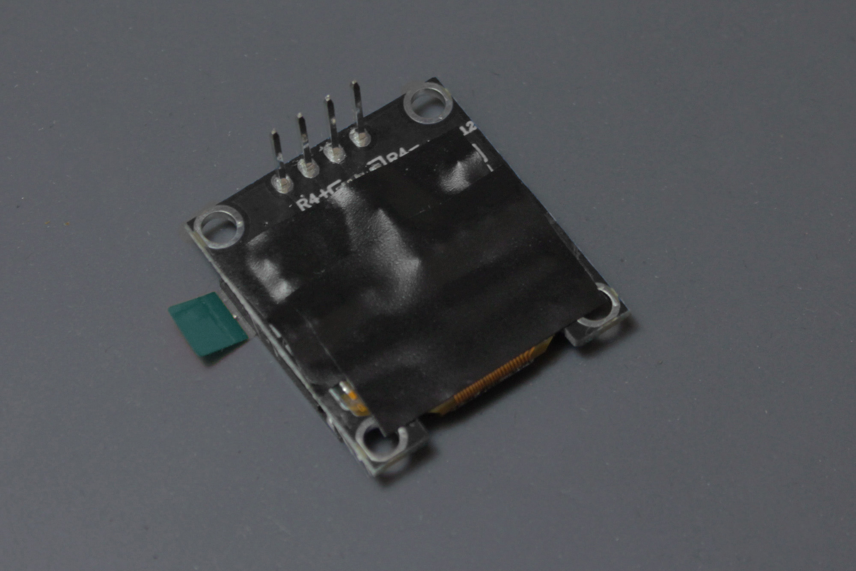
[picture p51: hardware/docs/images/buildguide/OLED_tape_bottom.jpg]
OLED tape on bottom


Insert the OLED on the top of the PCB. Make sure it sits as flush with the PCB as possible. Maybe hold it in place with some masking tape.

> **Note**
> You could also temporarily install the switchplate over the OLED, using a few switches. This way you make sure it's exactly in the right spot and rotation.

Solder the OLED into place.

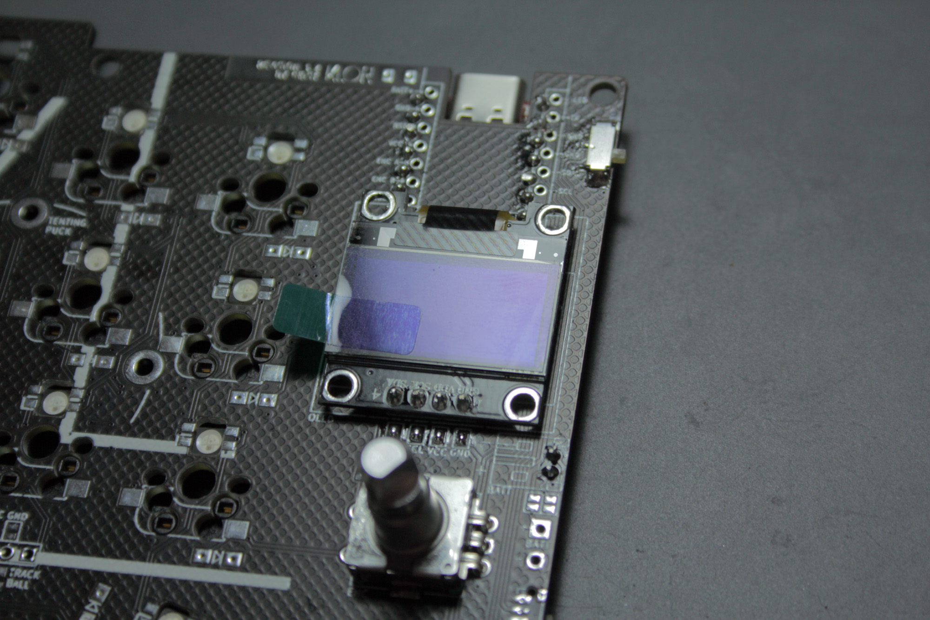
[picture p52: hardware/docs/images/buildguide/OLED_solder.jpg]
OLED soldering


Now use flush cutters to trim the top and bottom pins. Especially the top pins should be as short as possible to avoid interference with the switch plate.

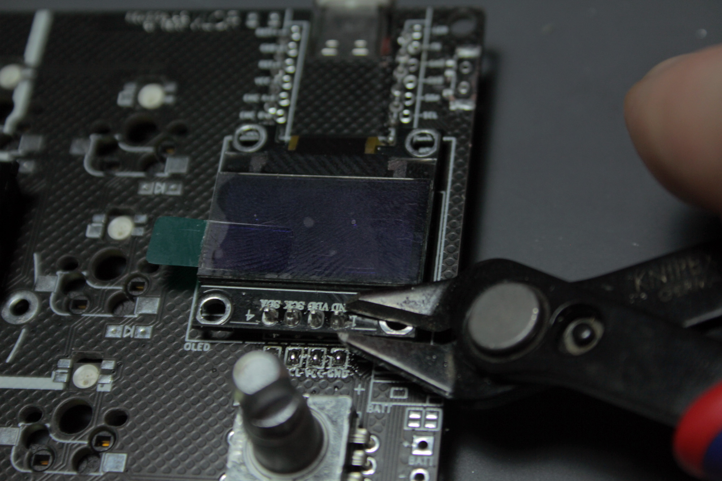
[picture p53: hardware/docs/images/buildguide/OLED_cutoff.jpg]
OLED flush cutter


If you use a metal switch plate consider covering them with electrical tape to prevent shorts.

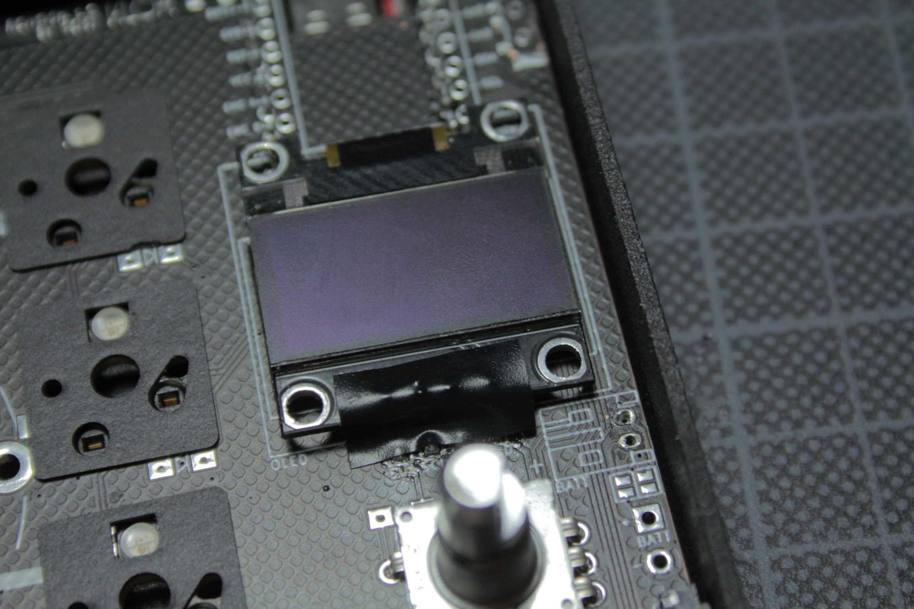
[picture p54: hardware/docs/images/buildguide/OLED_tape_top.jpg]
OLED tape on top


> **Note**
> If you need to desolder the OLED or fix its placement just apply a lot of solder to the four pins to connect them. This way you can heat all four pins at once and remove it by gently applying force to the bottom edge of the OLED module. Be really careful not to use too much pressure, since you could rip off a pad or destroy the OLED (which happens pretty fast).

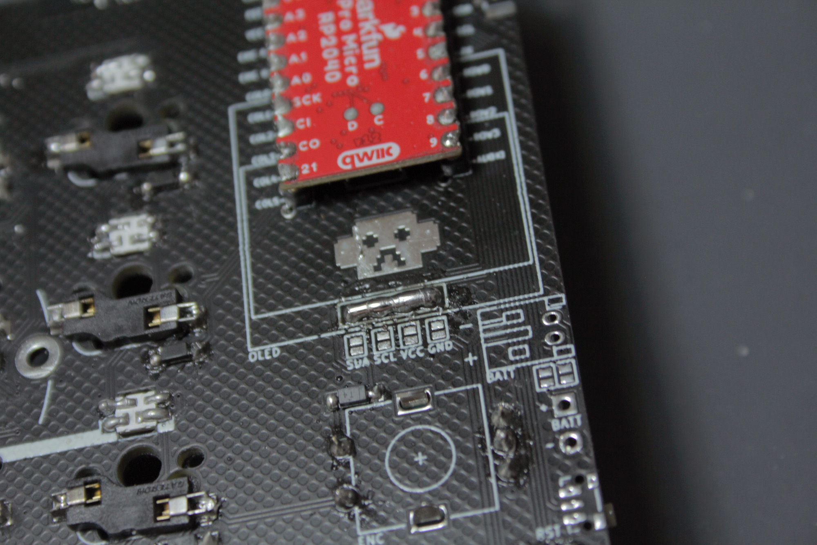
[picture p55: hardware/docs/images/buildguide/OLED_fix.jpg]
OLED desolder


***

## CLEANING

This is what your finished PCB probably will look like. You can use an old toothbrush and some isopropanol to clean it from residues. 

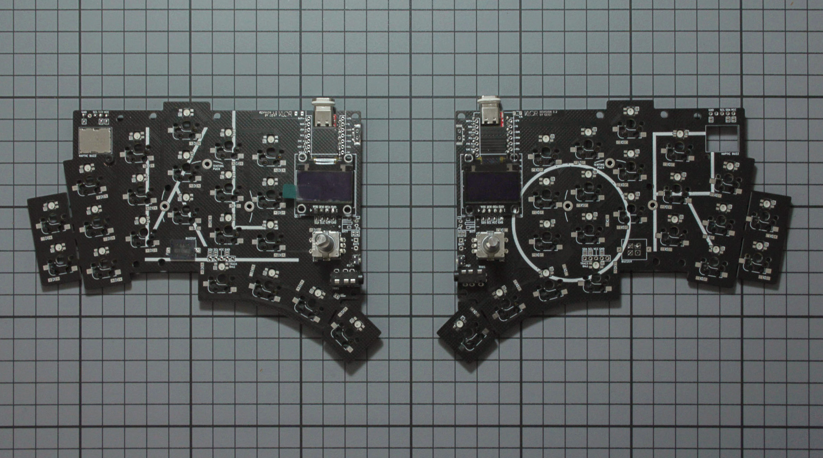
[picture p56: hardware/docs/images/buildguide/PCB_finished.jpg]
Finished PCB


***

## FIRMWARE

### AVR-based ProMicro 
**e.g. Pro Micro / Elite-C / Puchi-C**

If you have not already flashed the firmware to the microcontroller you should do it now, to make sure everything works, before inserting it into the case.\
[Here](https://github.com/GEIGEIGEIST/qmk-config-klor) you can find the QMK firmware for the KLOR.\
Copy the **klor** folder into the **keyboards** directory of your qmk installation.\
Then use [QMK MSYS](https://msys.qmk.fm/) (or the command line tool of your choice) to compile it with this command:

``qmk compile -kb klor -km default`` 

This will create a file called **klor_default.hex** in your **qmk_firmware** folder.\
Open [QMK Toolbox](https://github.com/qmk/qmk_toolbox) and locate the **klor_default.hex** file.\
Connect the ProMicro/keyboard and press the reset button (or connect the RST and GND pins on the ProMicro). QMK toolbox should show a connected device.\
Press **flash** in QMK toolbox to flash the firmware on your microcontroller.

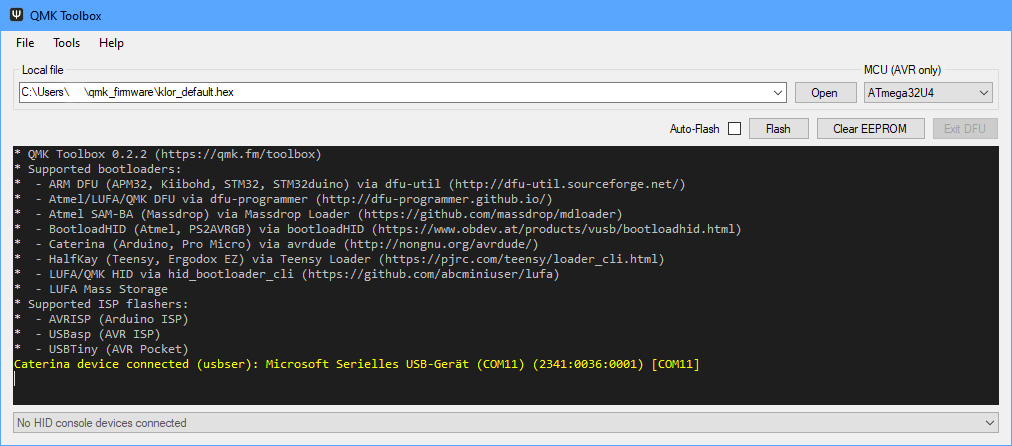
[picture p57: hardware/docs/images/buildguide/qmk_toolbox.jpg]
QMK toolbox


### RP2040 ProMicro 
**e.g. Adafruit KB2040 / Sparkfun Pro Micro RP2040 / Boardsource Blok / Elite-Pi / Sea-Picro**

Copy the **klor** folder into the **keyboards** directory of your qmk installation.\
Then use [QMK MSYS](https://msys.qmk.fm/) (or the command line tool of your choice) to compile it with this command:

``qmk compile -kb klor/rp2040 -km default``

This will create a file called **klor_rp2040_default.uf2** in your **qmk_firmware** folder.\
The first time you need to keep boot pressed, then press reset and release boot. This will open the flash memory of your MicroController as a device in your OS.\
Copy the **klor_rp2040_default.uf2** there to flash it. 

> **Note**
> After flashing the firmware the first time you can access the flash memory by double pressing the reset button on your keyboard or define a software reset key by using **QK_boot** as keycode.

***

## 3DP CASE

Here you can find the STL files for the case. I got them printed in PA12-HP Nylon (Multi Jet Fusion printing) by [JLCPCB](https://jlcpcb.com/3d-printing), which seemed pretty reasonably priced, for the level of detail.

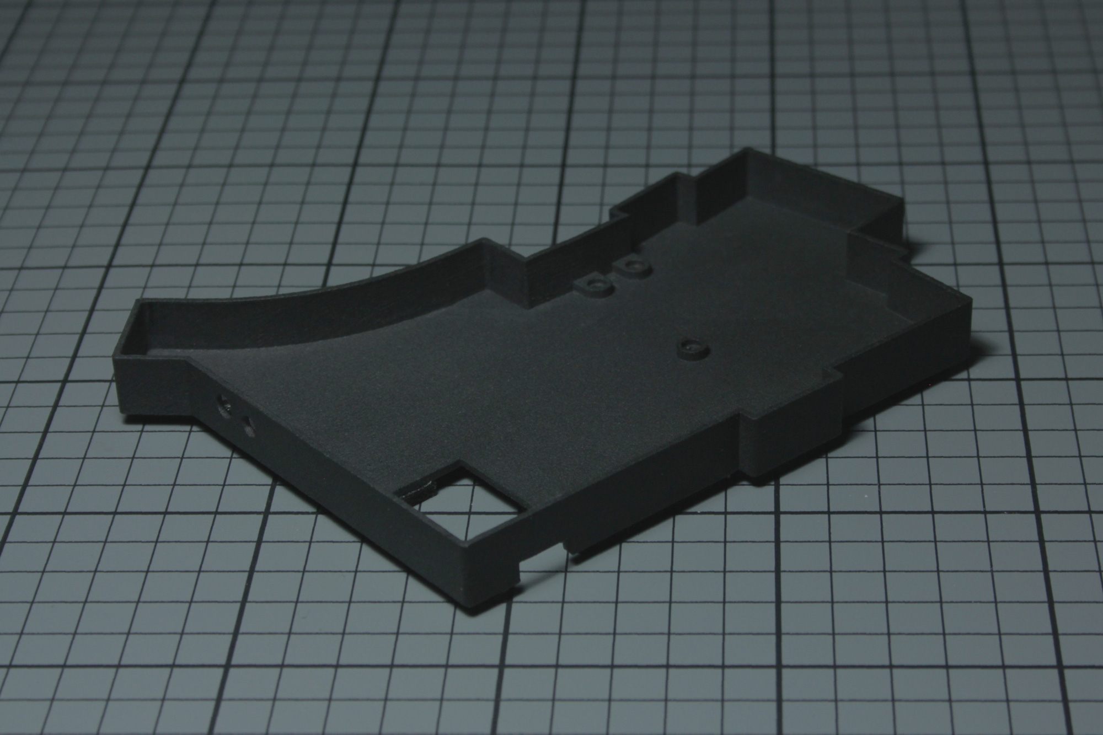
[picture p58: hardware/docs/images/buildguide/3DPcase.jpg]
3DP case


Insert the PCB first. Starting with inserting the microcontroller in the cutout at the top.

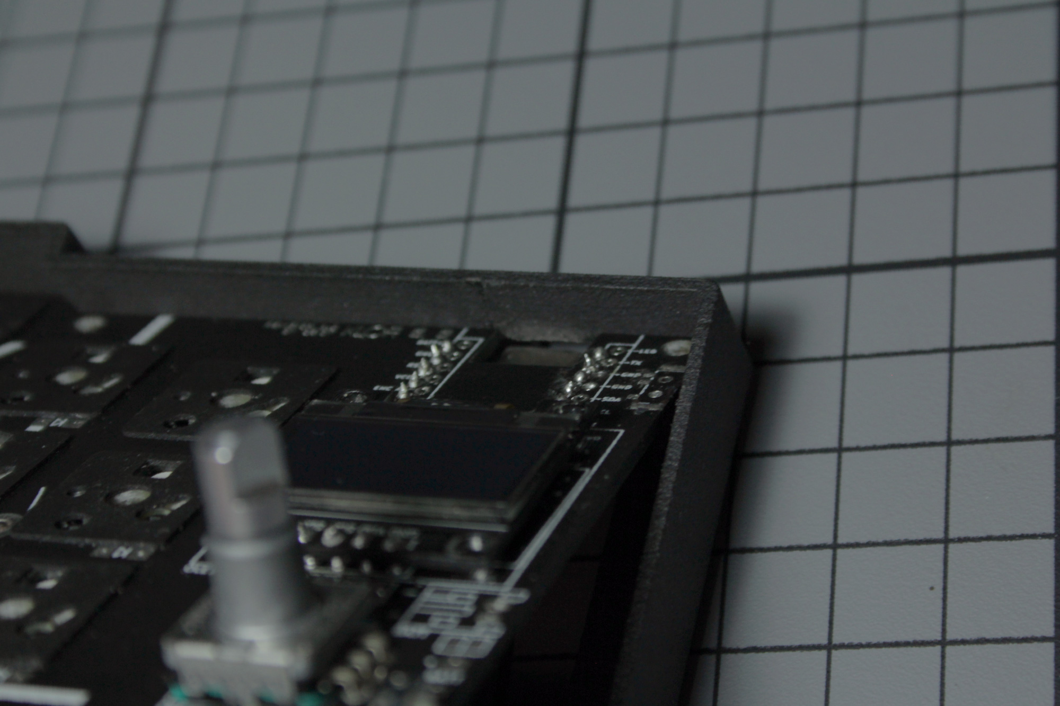
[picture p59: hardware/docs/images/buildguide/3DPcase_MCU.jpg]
3DP case insert MCU


Then lower it into the case. To make it fit, you probably need to bend a bit the part of the case containing the holes for reset switch and TRRS jack.

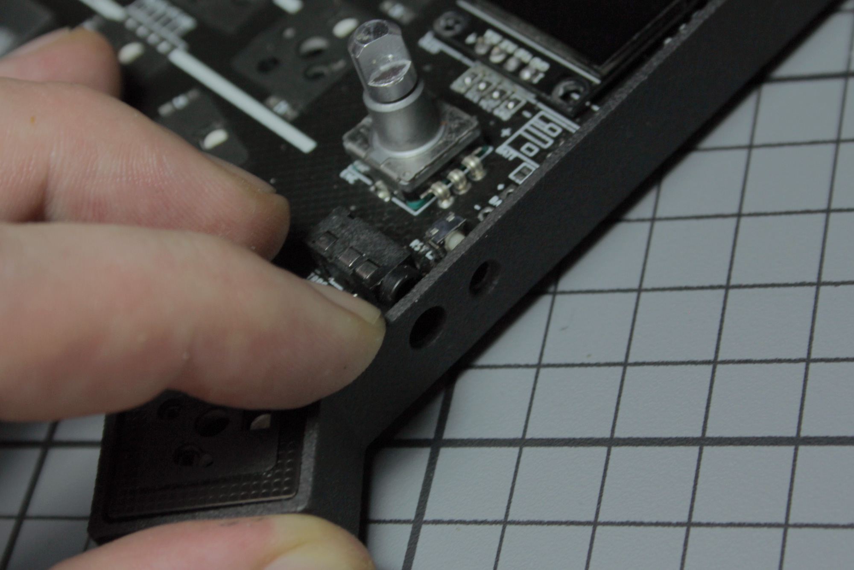
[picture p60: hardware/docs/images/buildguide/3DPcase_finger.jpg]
3DP case bend


The TRRS jack should snap in the provided hole.

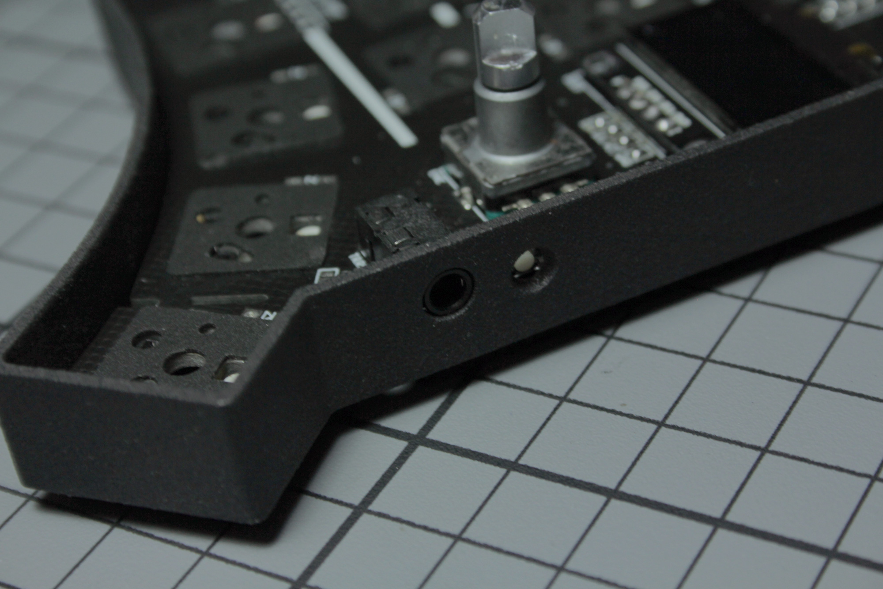
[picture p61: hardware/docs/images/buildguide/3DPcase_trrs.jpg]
3DP case trrs


Insert the standoffs in the PCB and screw them into the bottom of the case using the countersunk screws.

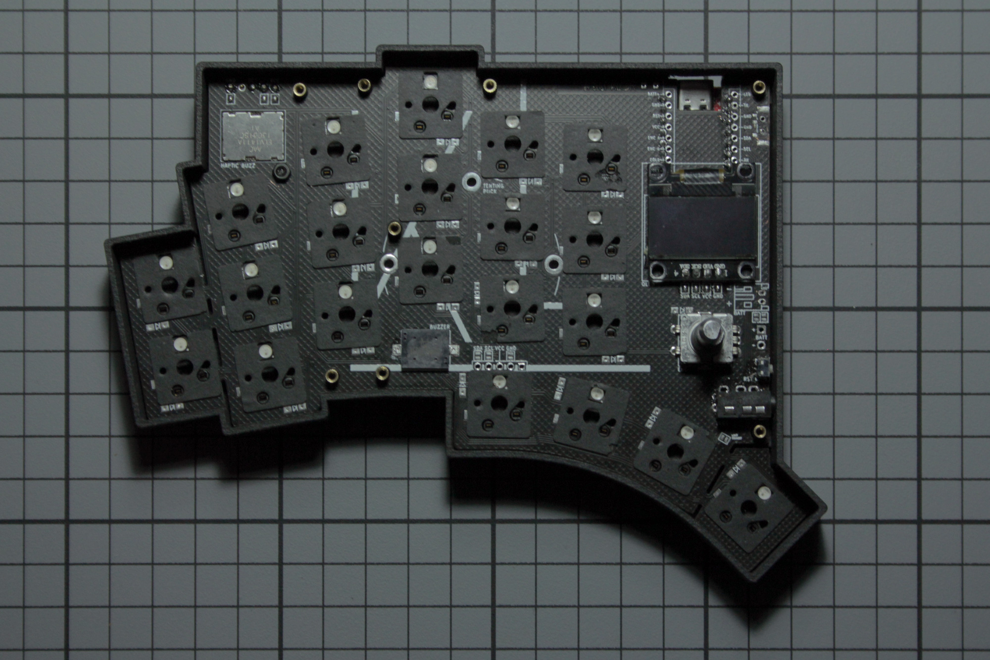
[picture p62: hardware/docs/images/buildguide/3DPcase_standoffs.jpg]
3DP case standoffs


Now you can insert the plate and screw it to the case using the center standoff. 

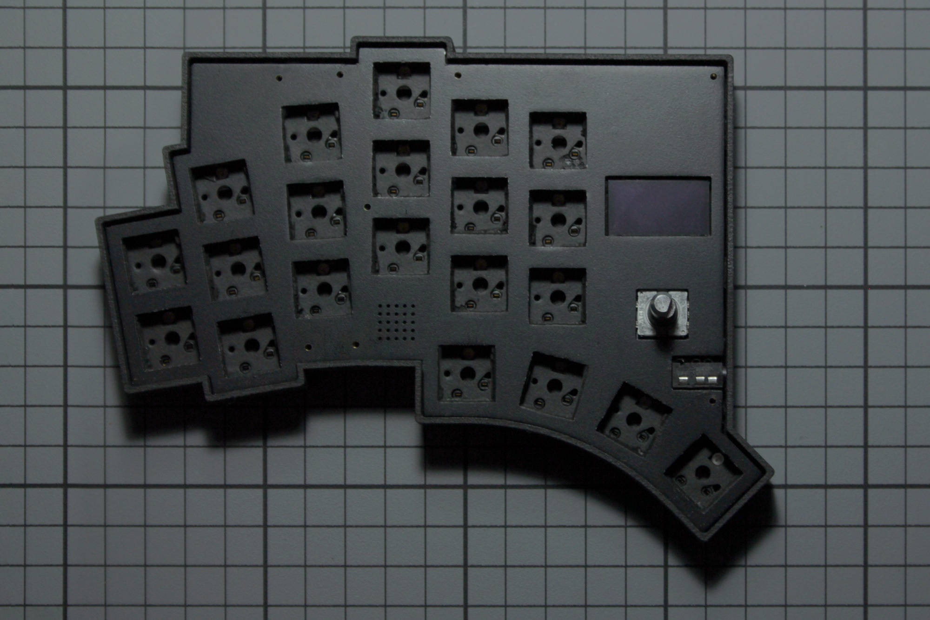
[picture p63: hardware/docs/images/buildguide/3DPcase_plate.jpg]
3DP case plate


***

## ACRYLIC PARTS

Here you can find the files for the acrylic parts. Made from smokey acrylic (by a laser cutting service) it will hide the OLED, while still allowing it  to shine through the top layer. It will look best if you can get a pretty dark type, like 7C83 by PlexiGlas (used by formulor.de for example).\
If you want to get rid of the shine you can carefully sand the parts with some really fine sanding paper (I used a 2000 sanding pad).\
You need to glue the ring to the top right part using acrylic glue (Acrifix for example). Be careful to apply only a really thin layer using a toothpick.\
If you choose a case with the KLOR logotype you can emphasize it by retracing it with some sort of white paint marker. Use turpentine or something similar to get rid of the excess paint.

Screw the acrylic parts on top of the plate.

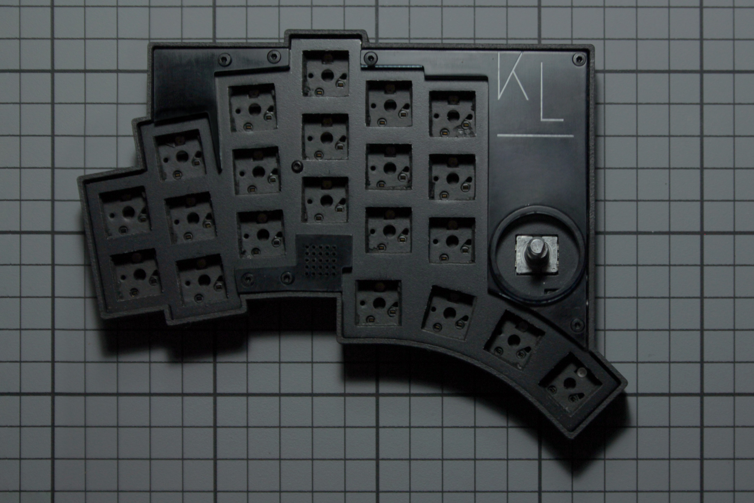
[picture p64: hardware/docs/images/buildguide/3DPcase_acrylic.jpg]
acrylic parts on top of plate


***

## KNOBS

The design works best with 23mm (0.9") diameter encoder knobs. My recommendation would be a knob from kilo international with a number beginning with 90 (which means a 0.9" diameter) like the OEDNI-90-4-7 shown here.

OEDNI-90-4-7

***

## FINAL BUILD

This is how the final keyboard will look like. In this picture, I use RAMA Grid keycaps in NOCT.

final KLOR build

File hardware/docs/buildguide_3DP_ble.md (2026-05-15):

# KLOR BUILD GUIDE (3DP CASE BLE) [WIP]

Since the BLE versin of the 3D print case is untested this build guide isn't created yet.

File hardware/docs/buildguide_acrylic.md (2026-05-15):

# KLOR BUILD GUIDE (STACKED ACRYLIC CASE) [WIP]

## PART LIST

### REQUIRED PARTS

| Part name | Count | Remarks | 
| :--- | :---: | :--- |
| KLOR PCB | 02 | You can find the files for it [here](/PCB/) |
| ProMicro | 02 | Alternatively, you can use another controller with a similar pinout like the Elite-C, Puchi-C, KB2040 dda. |
| MX Key switch | 42 | 40 switches for Konrad / 38 switches for Yubitsume / 36 switches for Saegewerk |
| switch socket | 42 | 40 sockets for Konrad / 38 sockets for Yubitsume / 36 sockets for Saegewerk |
| diodes 1N4148W| 44 | These are surface mount diodes in SOD123 package. 42 for Konrad / 40 for Yubitsume / 38 for Saegewerk |
| 1u MX keycaps | 42 | 40 keycaps for Konrad / 38 keycaps for Yubitsume / 36 keycaps for Saegewerk |
| OLED module | 02 | SSD1306 128x64 pixel OLED Displays |
| reset button  | 02 | Alps SKRTLAE010 |
| TRRS jack | 02 | MJ-4PP-9 or PJ320A |
| TRRS cable | 01 | Alternatively, you can use a TRS cable for [half-duplex](https://github.com/qmk/qmk_firmware/blob/master/docs/serial_driver.md#usart-half-duplex)|
| EC11 encoder  | 02 | You can use any EC11 encoder, but it will look better if you use a short one, like the EC11N1524402 |
| encoder knob  | 02 | The design works best with a 2,2cm encoder knob. I'd recommend kilo international knobs with a number starting with 90. You could also use the [knob](/knob/) I designed for the KLOR, based on the kilo knob. 
| USB cable | 01 | For connecting the keyboard to your PC |

### OPTIONAL PARTS

| Part name | Count | Remarks | 
| :--- | :---: | :--- |
| MCU sockets | 04 | For socketing your MCU. Highly recommended |
| MCU pins | 48 | In combination with the MCU sockets |
| SK6812 Mini LED (not Mini-E) 3535 size | 42 | 40 LEDs for Konrad / 38 LEDs for Yubitsume / 36 LEDs for Saegewerk |
| [Haptic Feedback Module](https://shop.pimoroni.com/products/drv2605l-linear-actuator-haptic-breakout) | 01 | Pimoroni Haptic Buzz |
| speaker | 01 | Mallory AST1109MLTRQ or Keliking KLJ-1102 |
| [trackball](https://bit-trade-one.co.jp/selfmadekb/adtb7m/) | 01 | Pixart PAW3204OA. Available at [Yushakobo](https://shop.yushakobo.jp/products/adtb7m) |
| [level converter](https://github.com/sekigon-gonnoc/LevelConverterForTrackballModule) | 01 | Needed to use the trackball. You can get it from [Yushakobo](https://shop.yushakobo.jp/products/a0800tl-01-1/) |
| [tenting puck](https://splitkb.com/products/tenting-puck)| 02 | SplitKB Tenting Puck |

### ACRYLIC CASE PARTS

| Part name | Count | Remarks | 
| :--- | :---: | :--- |
| acrylic parts | 02 | Find the case files [here](/case/acrylic/) |
| switch plate | 02 | 1.5mm switch plate |
| 9mm M2 standoffs | 22 | Up to 22 9mm round standoffs for the actual case (check the appropriate puzzle guide) |
| 7mm M2 standoffs | 12 | 7mm round standoffs for holding the PCB in place |
| 6mm M2 screws | 56 | Up to 56 regular 6mm M2 screws (check the appropriate puzzle guide) |
| 5mm M2 wafer head screws | 12 | These screws need a flat head to fit under the acrylic top layer |

## INTRODUCTION

Here is an overview of where and on which side each component needs to be soldered (click on the image to see a larger version).

KLOR solder guide

To see what component needs to sit where you can take a look at the [interactive HTML BOM](https://htmlpreview.github.io/?https://github.com/GEIGEIGEIST/KLOR/blob/main/docs/klor_rev1-3_ibom.html).

> **Warning**
> This interactive HTML BOM does show where each component is located, but please still refer to the soldering guide above to see if a component needs to go on the top or bottom of the PCB.

Be aware that for the 3D-printed case, some components need to be soldered on the opposite side.\
Some people mark the top and bottom with tape to keep track of which side is which, as the PCB is reversible.\
Begin with the flat components and progress to the higher ones, ending with the OLEDs and the encoders.

***

## BREAK OFF PARTS (optional)

If you choose a layout [other than](/README.md#layouts) Polydactyl you should remove the unnecessary parts. Use a flush cutter to snip through the support sections. You can also use a boxcutter to carve in grooves, which makes it easier to break on the right spot. 

> **Warning**
> Be very careful with this step, since there is a risk to break the PCB. Probably it would be best to begin with this step, to avoid losing already soldered parts.

break off parts

You can use a file to smooth out the edges, but you should wear a mask while doing this since the FR4 dust is considered to be toxic.

***

## MICROCONTROLLER

> **Warning**
> First flash the microcontroller to make sure it works, before soldering it in.

Unlike most other boards here the microcontroller needs to be mounted on the bottom, with the components facing upwards (to the PCB).\
Feel free to use the included header pins, but it's highly recommended to use MillMax low-profile sockets.\
Place the sockets in the marked spots on the bottom side of the PCB.

MCU sockets

You can keep them in place by using masking tape.

sockets taped

Then you can flip the board to solder in the sockets from the top.
Flip it again and insert the pins into the sockets.

> **Note**
> Use tweezers to insert them. Don't apply too much force, you will feel them snapping in. After that, you can carefully apply some pressure, using a flat object to make sure they're fully seated. 

MCU pins

Now place your microcontroller on the pins (components facing the PCB) and solder it to them.\
You can use flush cutters to trim the header pins.

MCU solder

> **Warning**
> When trimming with flush cutters wear eye protection or hold your hand close above the pins. Otherwise, sharp metal pins flying around might hurt you.

***

## LEDS (optional)

> **Note**
> If you use a layout with three thumbs, instead of four, you need to bridge the 'lost thumb?' jumper below the TRRS sockets on the primary and secondary PCB, since the led chain lost its beginning. 

Lost thumb jumper

LEDs are very heat sensitive. So it's a good idea to solder the pads on the PCB bottom first and then insert the LED.

LED solder pads

While the bottom of the PCB is facing you, insert the LEDs in the holes. The lens should face the table.

LED in place

This image depicts the correct orientation.\
The L-shaped pad on the LED needs to be connected to the square-marked pad.

LED orientation1

> **Note**
> While the orientation is uniform within one half, it differs between left and right.

> **Warning**
> It's recommended to solder the LEDs in at 220º, since they're pretty heat sensitive. Personally, I had a hard time keeping it below 270º. So my advice would be while soldering the first pad on every LED, try to be really quick. Then solder the second pad on every LED, starting with the first LED. This way they can cool down in the meantime.

Make sure the solder always builds a strong connection between the pad on the LED and the pad on the PCB. 

LED connection

The advantage of soldering in the microcontroller first is that you can occasionally check if all the LEDs work before continuing. 

KLOR LED working

This graphic shows the order in which the LEDs are chained together.

KLOR LED order

***

## DIODES

The diodes need to be soldered on the bottom of the PCB. Pay attention to their orientation:  They have a small line on one side, which should be on the side the arrow on the PCB is facing to.

<p align="center">
<picture>
  <source media="(prefers-color-scheme: dark)" srcset="/docs/images/buildguide/diodes_dark.svg">
  <source media="(prefers-color-scheme: light)" srcset="/docs/images/buildguide/diodes_bright.svg">
  diode orientation
</picture>
</p>

Apply a small amount of solder on one pad.

Solder on one pad

Then use tweezers to place the diode on the pads and reheat the solder to secure the diode.

Solder diode

Now you can solder the second pad.

***

## SWITCH SOCKETS

Here you can apply the same technique as used for the diodes: Apply some solder on one of the pads first.

switch sockets pad

Then place the switch socket in the silk screen markings and reheat the solder. Apply some pressure with a pair of tweezers to make sure the socket is fully seated.\
Now solder the second pad.

switch socket soldered

***

## RESET SWITCHES

The reset switches are a bit fiddly to solder. It helps to apply a really thin film of solder to the outer pads first. Then hold the switch in place with tweezers and solder the big pads on the left and right of the switch (they do not fulfill any electrical purpose, but serve to hold the switches in place). If the switch is seated correctly flip the PCB and solder the pads in the middle from below.

reset switch

***

## TRRS JACKS

Install the TRRS jack on the bottom side of the PCB. The place where you should insert it is marked with a white line.
You may want to use some masking tape to hold it in place since you need to solder it on the bottom.

TRRS jack taped

TRRS jack soldered

***

## HAPTIC FEEDBACK (optional)

> **Note**
> Currently, haptic feedback only works on the primary side of your keyboard, which is a limitation of QMK.

Apply some solder to the jumpers on the top to bridge them.

haptic feedback Jumper

Insert the module from below with the motor facing upwards. Then insert the pin headers from below.

haptic feedback pins

Now you can solder the pins and use a flush cutter to snap off the excess. Remember to hold your hand above them or wear eye protection while doing so.

haptic feedback snap of pins

You can also use a screw and a nut to stabilize the module further. But this step is optional.

haptic feedback solder

***

## SPEAKER (optional)

> **Note**
> Currently haptic feedback only works on the primary side of your keyboard, which is a limitation of QMK. Unfortunately, the audio feature of QMK doesn't work yet with the RP2040.

Soldering the speaker is pretty simple. Apply a tiny bit of solder on one of the pads, use tweezers to hold the speaker in place, and reheat the solder. After that apply solder to the other pad.

speaker

***

## TRACKBALL (optional)
> **Note**
> While the hardware side should already work fine, I still need to add the code for the trackball.

TBA

***

## ENCODERS

Mount the rotary encoder on the top side of the PCB. It should click into place maybe requiring a firm press. If it's seated correctly solder the pins on the bottom.

encoder

***

## OLEDs

> **Warning**
> Make sure the keyboard is fully functional before soldering the OLEDs, since they're the only components that cover pins, you won't be able to access them once they are in place.

The first step should be to bridge the jumpers on the top of the PCB next to the OLED.

OLED bridge jumpers

> **Note**
> The OLED needs to be as flush to the PCB as possible to fit under the switchplate.

You need to remove the plastic part, which is usually attached to the OLED, from the headers, while keeping the pins. For me the easiest way is to use flush cutters to snap the plastic in half, which allows you to remove the parts easily. You probably need to bend the pins back in place after doing this.

OLED pin split

You also need to cover the back of the OLED with electrical tape, to prevent shorts with the microcontroller pins. Especially the top part with the copper traces is important.

OLED tape on bottom

Insert the OLED on the top of the PCB. Make sure it sits as flush with the PCB as possible. Maybe hold it in place with some masking tape.

> **Note**
> You could also temporarily install the switchplate over the OLED, using a few switches. This way you make sure it's exactly in the right spot and rotation.

Solder the OLED into place.

OLED soldering

Now use flush cutters to trim the top and bottom pins. Especially the top pins should be as short as possible to avoid interference with the switch plate.

OLED flush cutter

If you use a metal switch plate consider covering them with electrical tape to prevent shorts.

OLED tape on top

> **Note**
> If you need to desolder the OLED or fix its placement just apply a lot of solder to the four pins to connect them. This way you can heat all four pins at once and remove them by gently applying force to the bottom edge of the OLED module. Be really careful not to use too much pressure, since you could rip off a pad or destroy the OLED (which happens pretty fast).

OLED desolder

***

## CLEANING

This is what your finished PCB probably will look like. You can use an old toothbrush and some isopropanol to clean it from residues. 

Finished PCB
***IMAGE***

***

## FIRMWARE

### AVR-based ProMicro 
**e.g. Pro Micro / Elite-C / Puchi-C**

If you have not already flashed the firmware to the microcontroller you should do it now, to make sure everything works, before inserting it into the case.\
[Here](https://github.com/GEIGEIGEIST/qmk-config-klor) you can find the QMK firmware for the KLOR.\
Copy the **klor** folder into the **keyboards** directory of your qmk installation.\
Then use [QMK MSYS](https://msys.qmk.fm/) (or the command line tool of your choice) to compile it with this command:

``qmk compile -kb klor -km default`` 

This will create a file called **klor_default.hex** in your **qmk_firmware** folder.\
Open [QMK Toolbox](https://github.com/qmk/qmk_toolbox) and locate the **klor_default.hex** file.\
Connect the ProMicro/keyboard and press the reset button (or connect the RST and GND pins on the ProMicro). QMK toolbox should show a connected device.\
Press **flash** in QMK toolbox to flash the firmware on your microcontroller.

QMK toolbox

### RP2040 ProMicro 
**e.g. Adafruit KB2040 / Sparkfun Pro Micro RP2040 / Boardsource Blok / Elite-Pi / Sea-Picro**

Copy the **klor** folder into the **keyboards** directory of your qmk installation.\
Then use [QMK MSYS](https://msys.qmk.fm/) (or the command line tool of your choice) to compile it with this command:

``qmk compile -kb klor/rp2040 -km default``

This will create a file called **klor_rp2040_default.uf2** in your **qmk_firmware** folder.\
The first time you need to keep boot pressed, then press reset and release boot. This will open the flash memory of your MicroController as a device in your OS.\
Copy the **klor_rp2040_default.uf2** there to flash it. 

> **Note**
> After flashing the firmware the first time you can access the flash memory by double pressing the reset button on your keyboard or define a software reset key by using **QK_boot** as keycode.

***

## STACKED ACRYLIC CASE

> **Note**
> Since there are a lot of different parts please check the 'puzzle guide' which you can find in the same folder as the case files of your layout. 

Screw the standoffs onto the bottom plate. You can find the location of the 7mm standoffs and 9mm standoffs in the 'puzzle guide', but as a rule of thumb, the 9mm standoffs should be on the outside, holding the case parts, while the 7mm standoffs will hold the PCB and switchplate.\
(The dark shapes on the bottom are pieces of deskmat, I use as bumpers.) 

acrylic bottom

Next, you should align the parts of the first layer to the outer standoffs. The parts for the left and right cases are interchangeable.

acrylic first layer

Now you can insert the PCB and add the other layers.

acrylic all layers

 Align the plate and screw them to the center standoffs.

 acrylic switchplate

For this step, you need the 5mm wafer head screws, since other screwheads would intersect with the top layer.

wafer head screws

Finally, attach the top plate and insert the switches into the plate.

acrylic top plate

***

## KNOBS

The design works best with 23mm (0.9") diameter encoder knobs. My recommendation would be a knob from kilo international with a number beginning with 90 (which means a 0.9" diameter) like the OEDNI-90-4-7 shown here.

OEDNI-90-4-7

***

## FINAL BUILD

This is how the final keyboard will look like. In this picture you see the KLOR saegewerk, with RAMA Grid keycaps in NOCT.

KLOR acrylic case

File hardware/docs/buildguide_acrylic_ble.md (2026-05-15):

# KLOR BUILD GUIDE (STACKED ACRYLIC CASE BLE) [WIP]

## PART LIST

### REQUIRED PARTS

| Part name | Count | Remarks | 
| :--- | :---: | :--- |
| KLOR PCB | 02 | You can find the files for it [here](/PCB/) |
| Nice!Nano | 02 | Alternatively, you can use another controller with similar pinout and bluetooth capabilities like the Puchi-BLE |
| MX Key switch | 42 | 40 switches for Konrad / 38 switches for Yubitsume / 36 switches for Saegewerk |
| switch socket | 42 | 40 sockets for Konrad / 38 sockets for Yubitsume / 36 sockets for Saegewerk |
| diodes 1N4148W| 44 | These are surface mount diodes in SOD123 package. 42 for Konrad / 40 for Yubitsume / 38 for Saegewerk |
| 1u MX keycaps | 42 | 40 keycaps for Konrad / 38 keycaps for Yubitsume / 36 keycaps for Saegewerk |
| OLED module | 02 | SSD1306 128x64 pixel OLED Displays |
| reset button  | 02 | Alps SKRTLAE010 |
| power switch  | 02 | MSK12C02 |
| EC11 encoder  | 02 | You can use any EC11 encoder, but it will look better if you use a short one, like the EC11N1524402 |
| encoder knob  | 02 | The design works best with a 2,2cm encoder knob. I'd recommend kilo international knobs with a number starting with 90. You could also use the [knob](/knob/) I designed for the KLOR, based on the kilo knob. 
| Lipo battery  | 02 | 
| USB cable | 01 | For connecting the keyboard with your PC |

### OPTIONAL PARTS

| Part name | Count | Remarks | 
| :--- | :---: | :--- |
| MCU sockets | 04 | For socketing your MCU. Highly recommended |
| MCU pins | 48 | In combinatin with the MCU sockets |
| JST Jack | 02 | JST PH |
| SK6812 Mini LED (not Mini-E) 3535 size | 42 | 40 LEDs for Konrad / 38 LEDs for Yubitsume / 36 LEDs for Saegewerk |
| TRRS jack | 02 | MJ-4PP-9 or PJ320A You can add TRRS jacks, so you can swap out the Microcontroller to make it a wired board |
| TRRS cable | 01 | See TRRS jack |
| [trackball](https://bit-trade-one.co.jp/selfmadekb/adtb7m/) | 01 | Pixart PAW3204OA. Available at [Yushakobo](https://shop.yushakobo.jp/products/adtb7m) |
| [level converter](https://github.com/sekigon-gonnoc/LevelConverterForTrackballModule) | 01 | Needed to use the trackball. You can get it from [Yushakobo](https://shop.yushakobo.jp/products/a0800tl-01-1/) |
| [tenting puck](https://splitkb.com/products/tenting-puck)| 02 | SplitKB Tenting Puck |

### ACRYLIC CASE PARTS

| Part name | Count | Remarks | 
| :--- | :---: | :--- |
| acrylic parts | 02 | Find the case files [here](/case/acrylic/) |
| switch plate | 02 | 1.5mm switch plate |
| 9mm M2 standoffs | 22 | Up to 22 9mm round standoffs for the actual case (check the appropiate puzzleguide) |
| 7mm M2 standoffs | 12 | 7mm round standoffs for holding the PCB in place |
| 6mm M2 screws | 56 | Up to 56 regular 6mm M2 screws (check the appropiate puzzleguide) |
| 5mm M2 wafer head screws | 12 | These screws need a flat head to fit under the acrylic top layer |

## INTRODUCTION

Here is an overview of where and on which side each component needs to be soldered (click on the image to see a larger version).

KLOR solder guide

To see what component needs to sit where you can take a look at the [interactive HTML BOM](https://htmlpreview.github.io/?https://github.com/GEIGEIGEIST/KLOR/blob/main/docs/klor_rev1-3_ibom.html).

> **Warning**
> This interactive HTML BOM does show where each component is located, but please still refer to the solder guide above to see if a component needs to go on the top or bottom of the PCB.

Be aware that for the 3D printed case some components need to be soldered on the opposite side.\
Some people mark the top and bottom with tape to keep track of which side is which, as the PCB is reversible.\
Beginn with the flat components and progress to the higher ones, ending with the OLEDs and the encoders.

***

## BREAK OFF PARTS (optional)

If you choose a layout [other than](/README.md#layouts) Polydactyl you should remove the unnecessary parts. Use a flush cutter to snip through the support sections. You can also use a boxcutter to carve in grooves, which makes it easier to break on the right spot. 

> **Warning**
> Be very careful with this step, since there is a risk to break the PCB. Probably it would be best to beginn with this step, to avoid loosing already soldered parts.

break off parts

You can use a file to smooth out the edges, but you should wear a mask while doing this, since the FR4 dust is considered to be toxic.

***

## MICROCONTROLLER

> **Warning**
> First flash the microcontroller to make sure it works, before soldering it in.

Unlike most other boards here the microcontroller needs to be mounted on the bottom, with the components facing upwards (to the PCB).\
Feel free to use the included header pins, but it's highly recommended to use MillMax low profile sockets.\
Place the sockets in the marked spots on the bottom side of the PCB.

MCU sockets

You can keep them in place by using masking tape.

sockets taped

Then you can flip the board to solder in the sockets from the top.
Flip it again and insert the pins into the sockets.

> **Note**
> Use tweezers to insert them. Don't apply too much force, you will feel them snap in. After that, you can carefully apply some pressure, using a flat object to make sure they're fully seated. 

MCU pins

Now place your microcontroller on the pins (components facing the PCB) and solder it to them.\
You can use flush cutters to trim the header pins.

MCU solder

> **Warning**
> When trimming with flush cutters wear eye protection or hold your hand close above the pins. Otherwise sharp metal pins flying around might hurt you.

***

## LEDS (optional)

> **Note**
> If you use a layout with three thumbs, instead of four, you need to bridge the 'lost thumb?' jumper below the TRRS sockets on the primary and secondary PCB, since the led chain lost its beginning. 

Lost thumb jumper

LEDs are very heat sensitive. So it's a good idea to solder the pads on the PCB bottom first and then insert the LED.

LED solder pads

While the bottom of the PCB is facing you, insert the LEDs in the holes. The lens should face the table.

LED in place

This image depicts the correct orientation.\
The L shaped pad on the LED need to be connected to the square marked pad.

LED orientation1

> **Note**
> While the orientation is uniform within a half, it differs between left and right.

> **Warning**
> It's recommended to solder the LEDs in at 220º, since they're pretty heat sensitive. Personally, I had a hard time keeping it below 270º. So my advice would be while soldering the first pad on every LED, try to be really quick. Then solder the second pad on every LED, starting with the first LED. This way they can cool down in the meantime.

Make sure the solder always builds a strong connection between the pad on the LED and the pad on the PCB. 

LED connection

The advantage of soldering in the microcontroller first is that you can occasionally check if all the LEDs work before continuing. 

KLOR LED working

This graphic shows the order in which the LEDs are chained together.

KLOR LED order

> **Note**
> While it's possible to use LEDs in a BLE board be aware that this will hugely decrease your battery life. 

***

## DIODES

The diodes needs to be soldered on the bottomm of the PCB. Pay attention to their orientation:  They have a small line on one side, which should be on the side the arrow on the PCB is facing to.

<p align="center">
<picture>
  <source media="(prefers-color-scheme: dark)" srcset="/docs/images/buildguide/diodes_dark.svg">
  <source media="(prefers-color-scheme: light)" srcset="/docs/images/buildguide/diodes_bright.svg">
  diode orientation
</picture>
</p>

Apply a small amount of solder on one pad.

Solder on one pad

Then use tweezers to place the diode on the pads and reheat the solder to secure the diode.

Solder diode

Now you can solder the second pad.

***

## SWITCH SOCKETS

Here you can apply the same technique as used for the diodes: Apply some solder on one of the pads first.

switch sockets pad

Then place the switch socket in the silk screen markings and reheat the solder. Apply some pressure with a pair of tweezers to make sure the socket is fully seated.\
Now solder the second pad.

switch socket soldered

***

## POWER SWITCHES

Apply a tiny bit of solder on one of the bigger, outer pads on top of the PCB. The power switch has some tiny knobs on its bottom, which fits into the PCB holes. Hold it in place with tweezers and than reheat the solder on the pad. After this you can solder the other pad and the three pins.

power switch

***

## JST JACKS (optional)

Insert the legs of the JST jack into the bottom of the PCB with the open side facing inwards

JST jack

Now use some masking tape to keep it in place, since you need to solder it from the top.

JST tape

You also need to bridge the jumpers next to the connector to make it work.

JST brigded jumpers

> **Note**
> While it's easier to swap out batteries if they already got a JST-PH connector you can also solder the battery to the **+ RED** and **- BLACK** pinholes. This way you don't need to bridge the jumpers.

battery connector

***

## RESET SWITCHES

The reset switches are a bit fiddly to solder. It helps to apply a really thin film of solder to the outer pads first. Then hold the switch in place with tweezers and solder the big pads on the left and right of the switch (they do not fulfill any electrical purpose, but serve to hold the switches in place). If the switch is seated corretly flip the PCB and solder the pads in the middle from below.

reset switch

***

## TRRS JACKS (optional)

> **Warning**
> You don't need the TRRS jacks for running the KLOR with ZMK. Actually you can damage your board when connecting it through TRRS, while also connected to a battery.

Install the TRRS jack on the bottom side of the PCB. The place where you should insert it is marked with a white line.
You may want to use some masking tape to hold it in place, since you need to solder it on the bottom.

TRRS jack taped

TRRS jack soldered

***

## TRACKBALL (optional)

> **Note**
> While the hardware side should already work fine, I still need to add the code for the trackball.

TBA

***

## ENCODERS

> **Note**
> Currently ZMK only supports encoders on the primary side of split keyboards. 

Mount the rotary encoder on the top side of the PCB. It should click into place maybe requiring a firm press. If it's seated correctly solder the pins on the bottom.

encoder

***

## OLEDs

> **Warning**
> Make sure the keyboard is fully functional before soldering the OLEDs, since they're the only components which cover pins, you won't be able to access once they are in place.

First step should be to bridge the jumpers on the top of the PCB next to the OLED.

OLED bridge jumpers

> **Note**
> The OLED needs to be as flush to the PCB as possible to fit under the switchplate.

You need to remove the plastic part, which is usually attached to the OLED, from the headers, while keeping the pins. For me the easiest way is to use flush cutters to snap the plastic in half, which allows you to remove the parts easily. You probably need to bend the pins back in place after doing this.

OLED pin split

You also need to cover the back of the OLED with electrical tape, to prevent shorts with the microcontroller pins. Especially the top part with the copper traces is important.

OLED tape on bottom

Insert the OLED on the top of the PCB. Make sure it sits as flush to the PCB as possible. Maybe hold it in place with some masking tape.

> **Note**
> You could also temporarily install the switchplate over the OLED, using a few switches. This way you make sure it's exactly in the right spot and rotation.

Solder the OLED into place.

OLED soldering

Now use flush cutters to trim the top and bottom pins. Especially the top pins should be as short as possible to avoid interference with the switch plate.

OLED flush cutter

If you use a metal switch plate consider to cover them with electrical tape to prevent shorts.

OLED tape on top

> **Note**
> If you need to desolder the OLED or fix its placement just apply a lot of solder to the four pins to connect them. This way you can heat all four pins at once and remove it by gently applying force to the bottom edge of the OLED module. Be really carefull not to use too much pressure, since you could rip off a pad or destroy the OLED (which happens pretty fast).

OLED desolder

***

## CLEANING

This is how your finished PCB probably will look like. You can use an old toothbrush and some isopropanol to clean it from residues. 

Finished PCB

***

## FIRMWARE

If you have not already flashed the firmware to the microcontroller you should do it now, to make sure everything works, before inserting it into the case.\
[Here](https://github.com/GEIGEIGEIST/zmk-config-klor) you can find the ZMK firmware for the KLOR.\
You need to create an own fork of it. In this fork you can edit the keymap to trigger an Github action, which will create your firmware. 

***

## STACKED ACRYLIC CASE

> **Note**
> Since there are a lot of different parts please check the 'puzzle guide' which you can find in the same folder than the case files of your layout. 

Screw the standoffs onto the bottom plate. You can find the locastion of the 7mm standoffs and 9mm standoffs in the 'puzzle guide', but as a rule of thumb the 9mm standoffs should be on the outside, holding the case parts, while the 7mm standoffs will hold the PCB and switchplate.\
(The dark shapes on the bottom are pieces of deskmat, I use as bumpers.) 

acrylic bottom

Next you should align the parts of the first layer to the outer standoffs. The parts for the left and right case are interchangeable.

acrylic first layer

Now you can insert the PCB and add the other layers.

acrylic all layers

 Align the plate and screw them to the center standoffs.

 acrylic switchplate

For this step you need the 5mm wafer head screws, since other screwheads would intersect with the top layer.

wafer head screws

Finally attach the top plate and insert the switches into the plate.

acrylic top plate

***

## KNOBS

The design works best with 23mm (0.9") diameter encoder knobs. My recomendation would be a knob from kilo internationl with a number beginning with 90 (which means a 0.9" diameter) like the OEDNI-90-4-7 shown here.

OEDNI-90-4-7

***

## FINAL BUILD

This is how the final keyboard will look like. In this picture you see the KLOR saegewerk, with RAMA Grid keycaps in NOCT.

KLOR acrylic case

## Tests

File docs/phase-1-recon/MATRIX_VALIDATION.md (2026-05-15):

# Phase 1 / Deliverable #2 — MATRIX_VALIDATION

> Validates matrix dimensions, pin mapping, layout structure, and GPIO budget untuk polydactyl layout target. Read-only audit. Critical findings di Section F akan affect Phase 2 PCB redesign.

---

## A. Matrix dimensions (confirmed)

| Setting | Value | Source |
|---|---|---|
| MATRIX_ROWS | **8** | [config.h:35](../../hardware/FIRMWARE/qmk_rp2040/electronlab/klor/config.h) |
| MATRIX_COLS | **6** | [config.h:36](../../hardware/FIRMWARE/qmk_rp2040/electronlab/klor/config.h) |
| DIODE_DIRECTION | COL2ROW | [keyboard.json:17](../../hardware/FIRMWARE/qmk_rp2040/electronlab/klor/keyboard.json) |
| DEBOUNCE | 5 ms | [config.h:37](../../hardware/FIRMWARE/qmk_rp2040/electronlab/klor/config.h) |

**Topology:** Split keyboard pakai QMK row-offset model.
- Each half punya 4 row pins fisik (hardware rows)
- QMK menggabungkan jadi 8 logical rows: **left half = rows 0-3, right half = rows 4-7**
- 6 col pins shared (each half scans col-nya sendiri independently)
- Logical matrix: **8 × 6 = 48 max keys**
- Polydactyl variant uses **44 of 48 slots** (4 unused: row 0 col 0 left, row 3 col 0 left, row 4 col 0 right, row 7 col 0 right)

## B. Matrix pin assignment (fork current)

### Rows (4 pins per half — same array, software offsets right half)

| Logical row L / R | Pin (RP2040 GPxx) | Source |
|---|---|---|
| 0 / 4 | GP5 | `keyboard.json` matrix_pins.rows[0] |
| 1 / 5 | GP6 | matrix_pins.rows[1] |
| 2 / 6 | GP7 | matrix_pins.rows[2] |
| 3 / 7 | GP8 | matrix_pins.rows[3] |

### Cols (6 pins, same array per half)

| Logical col | Pin (RP2040 GPxx) | Source | RP2040-Zero exposed? |
|---|---|---|---|
| 0 | GP27 | matrix_pins.cols[0] | ✅ broken out (ADC2 pad) |
| 1 | GP26 | matrix_pins.cols[1] | ✅ broken out (ADC1 pad) |
| 2 | GP22 | matrix_pins.cols[2] | ❌ **NOT broken out on RP2040-Zero** |
| 3 | GP20 | matrix_pins.cols[3] | ❌ **NOT broken out** |
| 4 | GP23 | matrix_pins.cols[4] | ❌ **NOT broken out** |
| 5 | GP21 | matrix_pins.cols[5] | ❌ **NOT broken out** |

> 🚨 **Critical** — 4 of 6 col pins tidak available on RP2040-Zero footprint. See Section F.1.

### Note: C macros commented out in config.h

[config.h:32-34](../../hardware/FIRMWARE/qmk_rp2040/electronlab/klor/config.h):
```c
//#define MATRIX_ROW_PINS { GP5, GP6, GP7, GP8 }
//#define MATRIX_COL_PINS { GP27, GP26, GP22, GP20, GP23, GP21 }
//#define DIODE_DIRECTION COL2ROW
```

Modern QMK is **data-driven via keyboard.json** — C macros are vestigial comments untuk legacy reference. Source of truth = keyboard.json.

## C. Other pin assignments (full GPIO budget snapshot)

| GPIO | Function | Source | RP2040-Zero exposed? | Status |
|---|---|---|---|---|
| GP0 | WS2812 RGB DI | `keyboard.json` ws2812.pin | ✅ edge | KEEP |
| GP1 | Serial (currently half-duplex TX) | [config.h:49](../../hardware/FIRMWARE/qmk_rp2040/electronlab/klor/config.h) | ✅ edge | KEEP |
| GP2 | I²C1 SDA (OLED data) | [config.h:26](../../hardware/FIRMWARE/qmk_rp2040/electronlab/klor/config.h) | ✅ edge | KEEP |
| GP3 | I²C1 SCL (OLED clock) | [config.h:25](../../hardware/FIRMWARE/qmk_rp2040/electronlab/klor/config.h) | ✅ edge | KEEP |
| GP4 | (reserved for full-duplex serial RX) | config.h:52 commented | ✅ edge | Phase 2 lock-in |
| GP5–GP8 | Matrix rows × 4 | matrix_pins.rows | ✅ edge | KEEP |
| GP9 | Audio PWM (DROPPED feature) | [config.h:115](../../hardware/FIRMWARE/qmk_rp2040/electronlab/klor/config.h) | ✅ edge | **FREED** |
| GP10–GP15 | Unused di fork | — | ✅ edge | **Available untuk col remap (F.1)** |
| GP16 | Internal RGB LED on RP2040-Zero board (status indicator) | Waveshare wiki | ⚠️ not on edge | Skip — reserved by board |
| GP17–GP19, GP24, GP25 | Not broken out on RP2040-Zero | — | ❌ | Skip permanently |
| GP20–GP23 | **Matrix cols 2-5 (CURRENT fork mapping)** | matrix_pins.cols | ❌ NOT on RP2040-Zero | **MUST REMAP** (F.1) |
| GP26, GP27 | Matrix cols 0-1 | matrix_pins.cols | ✅ ADC pads | KEEP |
| GP28, GP29 | Encoder A, B (left half) | `keyboard.json` encoder | ✅ ADC pads | KEEP |

## D. Inter-half serial transport — current state

**Currently active: half-duplex single-wire on GP1.** Full-duplex documented but commented out.

[config.h:48-55](../../hardware/FIRMWARE/qmk_rp2040/electronlab/klor/config.h):
```c
//Half Duplex communication        ← ACTIVE
#define SERIAL_USART_TX_PIN GP1

//Full Duplex communication        ← COMMENTED OUT
//#define SERIAL_USART_TX_PIN GP4
//#define SERIAL_USART_RX_PIN GP1
//#define SERIAL_USART_FULL_DUPLEX
//#define SERIAL_USART_PIN_SWAP
```

> 🔧 **Correction to earlier assumption** (Phase 0.5 framework): saya tulis "full-duplex GP1/GP4 active" — that's wrong. Fork's compiled firmware uses **half-duplex GP1 only**. Full-duplex documented as available option, tapi not active. Will update [PROJECT_SPEC.md](../../PROJECT_SPEC.md) Component Decisions after Phase 1 done.

**Implications untuk USB-C inter-half wiring:**

| Transport | Wires needed | GP usage | PCB routing |
|---|---|---|---|
| Half-duplex (current) | 3: VBUS + GND + Data | GP1 only | Simple |
| Full-duplex (upgrade) | 4: VBUS + GND + TX + RX | GP4 + GP1 (cross-wired between halves) | Both pads routed to USB-C |

**Decision (Claude, Phase 2):** Design PCB **future-proof** — route both GP1 and GP4 ke USB-C connector pads. Firmware start dengan half-duplex (proven working), upgrade ke full-duplex post-validation. Cost = 1 extra trace, near-zero downside.

## E. LAYOUT_polydactyl — key count & coordinate mapping

### Key count (from keyboard.json LAYOUT_polydactyl)

**44 keys total** — counted by enumerating `keyboard.json` layouts.LAYOUT_polydactyl.layout array entries:

| Position group | Left side | Right side | Subtotal |
|---|---|---|---|
| Top row (cols 1-5) | L01-L05 (5) | R01-R05 (5) | 10 |
| Home row (cols 0-5) | L10-L15 (6) | R10-R15 (6) | 12 |
| Bottom row (cols 0-5) | L20-L25 (6) | R20-R25 (6) | 12 |
| **Polydactyl horn** (col 5, between row 2 & thumb) | **L35 (1)** | **R30 (1)** | **2** |
| Thumb cluster (cols 1-4) | L31-L34 (4) | R31-R34 (4) | 8 |
| **TOTAL** | **22** | **22** | **44** |

### Matrix coordinate → physical position (LEFT half)

```
              ┌───┬───┬───┬───┬───┐
              │L01│L02│L03│L04│L05│      y=0  [matrix row 0]
              │0,1│0,2│0,3│0,4│0,5│
              └───┴───┴───┴───┴───┘
          ┌───┬───┬───┬───┬───┬───┐
          │L10│L11│L12│L13│L14│L15│      y=1  [matrix row 1]
          │1,0│1,1│1,2│1,3│1,4│1,5│
          └───┴───┴───┴───┴───┴───┘
          ┌───┬───┬───┬───┬───┬───┬───┐
          │L20│L21│L22│L23│L24│L25│L35│  y=2  [row 2 + horn at row 3 col 5]
          │2,0│2,1│2,2│2,3│2,4│2,5│3,5│
          └───┴───┴───┴───┴───┴───┴───┘
                  ┌───┬───┬───┬───┐
                  │L31│L32│L33│L34│      y=3  [matrix row 3 thumb]
                  │3,1│3,2│3,3│3,4│
                  └───┴───┴───┴───┘
```

Per cell: top = QMK label, bottom = matrix [row, col].

### Matrix coordinate → physical position (RIGHT half, mirrored)

```
              ┌───┬───┬───┬───┬───┐
              │R01│R02│R03│R04│R05│      y=0  [matrix row 4]
              │4,5│4,4│4,3│4,2│4,1│
              └───┴───┴───┴───┴───┘
          ┌───┬───┬───┬───┬───┬───┐
          │R10│R11│R12│R13│R14│R15│      y=1  [matrix row 5]
          │5,5│5,4│5,3│5,2│5,1│5,0│
          └───┴───┴───┴───┴───┴───┘
        ┌───┬───┬───┬───┬───┬───┬───┐
        │R30│R20│R21│R22│R23│R24│R25│    y=2  [row 6 + horn at row 7 col 5]
        │7,5│6,5│6,4│6,3│6,2│6,1│6,0│
        └───┴───┴───┴───┴───┴───┴───┘
              ┌───┬───┬───┬───┐
              │R31│R32│R33│R34│          y=3  [matrix row 7 thumb]
              │7,4│7,3│7,2│7,1│
              └───┴───┴───┴───┘
```

> **Note:** Right side matrix col indexing reversed (e.g., R01 = [4,5], not [4,1]) — mirror image semantics typical untuk split keyboards. Col 0 secara fisik = outer pinky, di kanan terletak di sisi kanan, di kiri di sisi kiri. Pin GP27 on kedua half = col 0.

## F. Critical findings untuk Phase 2 / 3 / 6

### F.1 🚨 GP20–GP23 not exposed on RP2040-Zero → 4 col pins MUST be remapped

**Issue:** Fork's `matrix_pins.cols` array references GP20, GP22, GP21, GP23 — pin GPxx labels yang elite_pi (RP2040 ProMicro form-factor) expose via Pro Micro pinout. **Waveshare RP2040-Zero only breaks out GP0-15 + GP26-29** = 20 GPIO. GP16-25 (except GP26, GP27) are NOT accessible on the board's castellated edge.

**Affected pins:** GP22, GP20, GP23, GP21 — semua 4 col pins yang bukan GP26/GP27.

**Decision (Claude, Phase 2 prep):** Remap 4 col pins ke GP10-GP15 range (6 contiguous unused pins di RP2040-Zero). Phase 1 #4 PIN_MAPPING_PROPOSAL will lock specific assignment.

Proposed remap (subject Phase 1 #4 refinement):
| Logical col | Old pin (elite_pi) | New pin (RP2040-Zero) |
|---|---|---|
| 0 | GP27 | GP27 ✅ keep |
| 1 | GP26 | GP26 ✅ keep |
| 2 | GP22 | **GP10** (or other in 10-15) |
| 3 | GP20 | **GP11** |
| 4 | GP23 | **GP14** |
| 5 | GP21 | **GP15** |

**Affects:**
- ✅ **PCB routing (Phase 3):** physical traces from MCU pad → matrix col diodes/switches
- ✅ **Firmware (Phase 6):** update `keyboard.json` `matrix_pins.cols` array  
- ✅ **PROJECT_SPEC.md update needed** at end of Phase 1

> **This invalidates the Phase 0 assumption** ("PCB route same GPxx physical traces, firmware delta = zero"). Firmware DOES need update — at least `matrix_pins.cols` array. Other pins (rows GP5-8, RGB GP0, encoder GP28/29, I²C GP2/3, serial GP1) tetap valid pada RP2040-Zero.

### F.2 OLED is 128×64 in fork (not 128×32 as user spec)

[config.h:74](../../hardware/FIRMWARE/qmk_rp2040/electronlab/klor/config.h):
```c
#define OLED_DISPLAY_128X64
```

Plus footprint named `SSD1306_128x64OLED.kicad_mod`. Both consistent → fork built around 128×64.

**Decision (Claude):** **Accept 128×64** (revise PROJECT_SPEC.md from 128×32).

**Justification:**
- Fork OLED rendering code (klor.c, klorimation.h, glcdfont.c logo bitmap) all tuned untuk 128×64
- Changing to 128×32 = firmware rewrite + animation re-tune + logo re-render
- 128×64 0.96" module = ~28×28mm physical, vs 128×32 0.91" ~30×11mm — both fit klor1_4 PCB OLED slot
- Tokopedia stock both, similar price (~25-35rb)
- More screen real estate untuk status/animations
- ✅ Reduces project scope (one less firmware change)

**Update PROJECT_SPEC.md** after Phase 1 complete: COMPONENT_DECISIONS.OLED → "SSD1306 0.96" 128×64 I²C 4-pin".

### F.3 Serial transport = half-duplex GP1 (not full-duplex as initially assumed)

Already detailed in Section D. PROJECT_SPEC.md Component Decision needs update:
- Was: "full-duplex GP1/GP4"
- Correct: "half-duplex GP1 active, GP4 reserved for future upgrade"
- PCB design (Phase 3): route BOTH GP1 + GP4 to USB-C connector future-proof

### F.4 Polydactyl is 44-key (R1 spec says 42-key)

User REQUIREMENT R1 ("42-key split keyboard, polydactyl layout") doesn't match fork's actual `LAYOUT_polydactyl` = **44 keys**.

Variants di fork dengan key count:
- **saegewerk**: 38 keys
- **yubitsume**: 40 keys
- **konrad**: 42 keys (matches "42-key" label)
- **polydactyl**: 44 keys (matches "polydactyl" label)

**Decision (Claude):** **Accept polydactyl = 44 keys.** User specified "polydactyl" name explicitly; "42-key" likely colloquial label (split42 category) bukan precise count. Polydactyl's defining feature = L35/R30 horn keys → without them it's not polydactyl, it's konrad.

**Update R1 setelah Phase 1 complete:** "44-key split keyboard, polydactyl layout, 22 keys per half".

> 🔔 Flagging this untuk Anda explicit — kalau Anda actually MAU 42-key (konrad shape, no horns), ini moment untuk redirect ke konrad. Default = polydactyl-44 sesuai requirement R1 spirit.

## G. GPIO budget recap (RP2040-Zero, 20 GPIO available)

After audio/haptic dropped + col remap planned:

| Function | GPIO count | Pins |
|---|---|---|
| Matrix rows | 4 | GP5, GP6, GP7, GP8 |
| Matrix cols (post-remap) | 6 | GP26, GP27 + 4 from GP10-15 |
| WS2812 RGB DI | 1 | GP0 |
| Serial (current half-duplex) | 1 | GP1 |
| Serial RX (if full-duplex upgrade) | +1 | GP4 |
| I²C (OLED + future trackball) | 2 | GP2, GP3 |
| Encoder A, B | 2 | GP28, GP29 |
| **TOTAL (current half-duplex)** | **16** | |
| **TOTAL (full-duplex upgrade)** | **17** | |

**RP2040-Zero exposes:** 20 GPIO (GP0-15 + GP26-29).  
**Headroom:** **3-4 GPIO free** (GP9 freed from audio + 2 of GP10-15 after col remap).

✅ **Budget passes comfortably** — proceed dengan RP2040-Zero, no GPIO compromise needed.

## H. Cross-references

- [INVENTORY.md](INVENTORY.md) — Phase 1 #1 baseline
- [PROJECT_SPEC.md](../../PROJECT_SPEC.md) — Component decisions (akan ada updates ke OLED, serial, key count post-Phase 1)
- [keyboard.json](../../hardware/FIRMWARE/qmk_rp2040/electronlab/klor/keyboard.json) — Pin & matrix source of truth
- [config.h](../../hardware/FIRMWARE/qmk_rp2040/electronlab/klor/config.h) — Firmware-level config
- [Waveshare RP2040-Zero pinout](https://www.waveshare.com/wiki/RP2040-Zero) — GPIO availability reference

## I. Open items (will defer atau lock di subsequent deliverables)

| Item | Status | Resolve at |
|---|---|---|
| Col pin remap specific GP10-15 assignment | Proposed (GP10,11,14,15) | Phase 1 #4 PIN_MAPPING_PROPOSAL |
| OLED footprint pad layout (verify 128×64 fits) | Decided 128×64 | Phase 1 #3 FOOTPRINT_INVENTORY (verify only) |
| Half-duplex vs full-duplex final lock-in | Decided: both routed, half-duplex firmware initial | Phase 2 schematic |
| Polydactyl 44-key acceptance | Recommended accept; flag for user override | THIS deliverable — see Section F.4 |
| PROJECT_SPEC.md updates: OLED 128×64, serial half-duplex, R1 → 44-key | Pending | End of Phase 1 (after #3-#5) |

## J. Next deliverable

**Phase 1 deliverable #3: `FOOTPRINT_INVENTORY.md`**

Scope:
- Identify existing footprints per category (MCU, TRRS, RGB LED, switch, encoder, OLED, diode, reset button)
- Library source per footprint (marbastlib? built-in? custom dalam KLORlib?)
- Identify footprints needed untuk modifications:
  - RP2040-Zero footprint (cari source — marbastlib, community, atau custom)
  - SK6812MINI-E **verify orientation** (apakah really south-facing di fork?)
  - USB-C 16-pin midmount (marbastlib coverage check)
- **Verify SSD1306 128×64 footprint pad layout** consistent dengan keputusan F.2

Estimated read targets: open ~5 `.kicad_mod` files dari `KLOR.pretty/`, marbastlib documentation, OLED module datasheets if needed. Output ~150-200 lines.

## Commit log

2026-05-15 Initial commit: KLORID Phase 2 close baseline
    KLORID = 42-key split keyboard, polydactyl layout, Indonesia-sourceable
    build. Derivative of Lefuneste83/KLOR (which forks GEIGEIGEIST/KLOR).
    Hardware modifications (Phase 2 schematic + initial PCB sync):
    - MOD #1: Pro Micro -> Waveshare RP2040-Zero (2.54mm pitch through-hole)
    - MOD #2: TRRS -> USB-C 16-pin midmount (HRO Type-C-31-M-12)
    - MOD #3: SK6812MINI south-facing verified (no schematic change needed)
    - Housekeeping: drop haptic, audio, trackball module, battery section
    Pin remap: matrix cols GP22/20/23/21 -> GP9/10/11/12 (ascending)
    RESET button -> GP15 (soft reset via Vial keycode)
    CC pulldowns R1/R2 = 5.1k 0603 SMD; J1 = HRO USB-C midm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
    [Base-Konrad.stl, BaseWithTenting-Konrad.stl, EncoderInsert-16mm.stl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]
2026-05-17 Phase 3 complete: PCB routing functional (0 DRC errors)
    Routing work since initial commit:
    - All 17 matrix unconnected items routed (cols 0-5, rows 0-3)
    - Power network completed (+5V from J1 VBUS to U1, VCC distribution)
    - I2C OLED routed (SDA/SCL via U1 pins 20-21 to JP5/JP6)
    - Inter-half serial routed (TX/RX U1 to J1 USB-C pads)
    - Reset switch GND connection (with bridge via)
    - Encoder + LED chain routing preserved
    Design rule updates:
    - Via size: 0.4mm -> 0.6mm (JLCPCB compliant 6 mil annular ring)
    - All 325 vias updated to manufacturing-safe dimensions
    - +5V added to Power netclass (alongside GND, VCC)
    - Power netclass clearance retained at 0.2mm (manual via moves resolved
    initial cl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
2026-05-18 Phase 3d: title block + routing improvements
    PCB updates since Phase 3 complete:
    - Title block updated: Author=Hallaz, Title=Klor-ID Split Keyboard, Rev=v1.5
    - 113 GND stitching vias added (improve noise rejection)
    - Reset switch moved from side to top position
    - OLED footprint shifted up (utilize space from shorter RP2040-Zero vs Pro Micro)
    - Encoder footprint repositioned
    - USB-C J1 area decluttered (more clearance to neighbors)
    - Vias reorganized to resolve clearance violations (97 -> 0)
    DRC: 0 errors maintained
    Pre-encoder-experiment checkpoint (next: try encoder -> MX switch conversion)
2026-05-18 Phase 3e: dual-purpose encoder/MX switch + LED chain integration
    Schematic changes:
    - Added SW23 (SW_PUSH-MX_W_LED) as dual-purpose alternative to encoder push
    - New MX switch shares matrix position [3,5] with encoder push button
    (col5 + SW18B nets, shared diode)
    - LED chain extended: SW23B inserted between existing LEDs in chain
    - Footprint property fixed: KLOR:SK6812MINI_and_cherry_1 (south-facing variant)
    PCB changes:
    - SW23 footprint placed at encoder position (overlapping dual-purpose)
    - LED chain trace routed (SW23 DOUT -> next LED DIN)
    - Encoder MP overlap clearance fixed via repositioning
    - GND zone refilled
    DRC status: 0 errors, 0 unconnected ✓
    Build flexibility: builder choi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
    [klor1_4.kicad_sch]
2026-05-18 Phase 3f: cleanup orphan footprints + remove left thumb breakaway notch
    - Delete orphan encoder footprint (-31.605, 143.12) — F8 Update PCB artifact
    - Delete 2 orphan LED footprints at negative-X (-66.66, -76.615) — off-board
    - Delete breakaway notch Edge.Cuts in left thumb cluster bottom
    (2 segments at Y=143-149, V-pattern, 6.6mm legs)
    - USB-C J1 minor reposition (+0.05mm X, -1.02mm Y)
    - SW18 active encoder minor reposition (+0.36mm X, +0.11mm Y)
    Decision context:
    - Breakaway removed per real-world fragility evidence (manufactured PCB
    reference showing tab snap failure under normal handling)
    - 2 other V-notch candidates at (88.96, 138.91) and (213.24, 77.00)
    PRESERVED — functio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
2026-05-18 Phase 3g: add haptic feedback Pimoroni connector (DNP)
    Re-add haptic capability dropped in Phase 2, but with DNP flag for
    optional install. User decision: V1-only build (no Rev 2 planned), so
    add now or skip permanently. Haptic chosen for layering feedback +
    curiosity. DNP = order PCB ready, install Pimoroni breakout later.
    Schematic:
    - Add Conn_01x05_Pin symbol J2 "Haptic_Buzz_DNP" to lib_symbols
    - Symbol instance with dnp flag set (red X visual indicator)
    - Wire 5 pins in Pimoroni Haptic Buzz pin order: VCC, SDA, SCL,
    HAPTIC_TRIG, GND (direct plug-in via female header, no Dupont)
    - I2C SDA/SCL share OLED bus (GP2/GP3, multi-device on same bus)
    - HAPTIC_TRIG net new, connected to MCU GP1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
    [klor1_4.kicad_sch]
2026-05-19 Phase 3h: silkscreen KLORID + Garuda image (footprint approach)
    PCB Silkscreen branding:
    - Add gr_text "KLORID" on F.SilkS layer at (97.125, 70.85, 90deg)
    Vertical orientation, 3.5mm height, above OLED area on left half
    Position chosen by user via KiCad GUI move
    Garuda image (Indonesia national emblem branding):
    - 4 Garuda footprint variants created in KLOR.pretty library:
    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
2026-05-19 Phase 4 prep: regenerate Gerber output files
    Regenerated all Gerber export files via KiCad File -> Plot reflecting
    Phase 3a-3h cumulative design state (current commit-ready PCB):
    Layers exported:
    - F.Cu / B.Cu (copper)
    - F.Mask / B.Mask (soldermask)
    - F.Paste / B.Paste (solder paste, for SMD stencils)
    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
    [klor1_4-B_Cu.gbl, klor1_4-B_Mask.gbs, klor1_4-B_Paste.gbp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]
2026-05-19 docs: sync README to current state (Phase 3a-3h + 4 prep complete)
    Updates:
    - Status section: Phase 2 close -> Phase 4 ready
    - Add Phase 3 enhancements table (3e dual-purpose SW23, 3f breakaway
    removal, 3g haptic DNP, 3h KLORID+Garuda silkscreen)
    - Remove haptic from DROPPED list (re-added as DNP in Phase 3g)
    - Add latest milestones bullet list (Gerber export, switchplate DXF, etc.)
    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
